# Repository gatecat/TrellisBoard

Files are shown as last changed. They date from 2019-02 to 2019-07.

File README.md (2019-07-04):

# Ultimate ECP5 Board

WIP - Rev 1.0 prototypes currently under test...

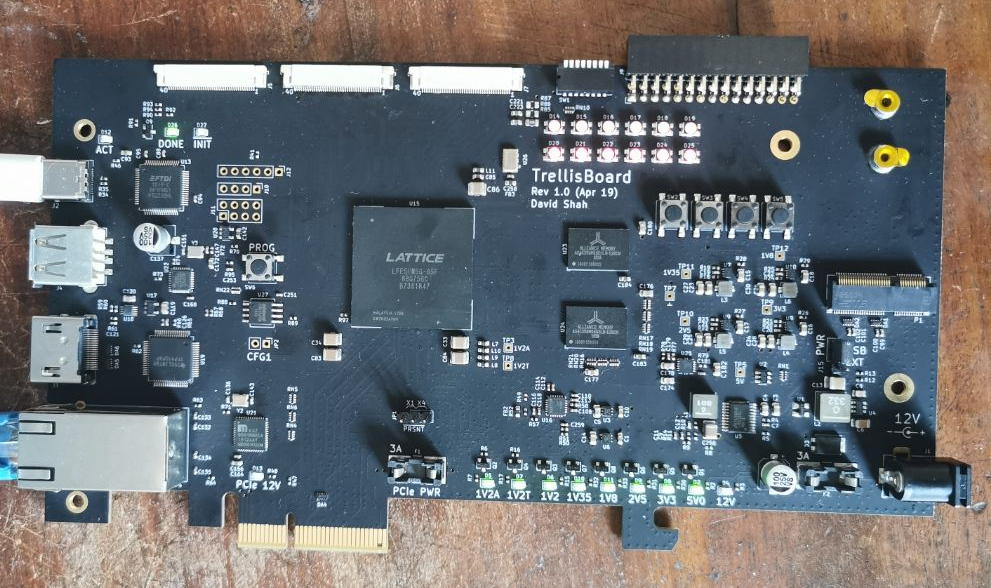
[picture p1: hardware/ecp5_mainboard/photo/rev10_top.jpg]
Photo of PCB rev 1.0

Render of PCB rev 1.0

## Key Features
 - Largest ECP5; LFE5UM5G-85F
 - PCIe 2.0 x2 card edge connector on two SERDES channels
 - Remaining two SERDES channels on M.2 E-key connector
 - 1GByte x32 DDR3L (two x16 chips)
 - Dedicated HDMI output, using TFP410 serialiser
 - 1000BASE-T GbE connector with RGMII PHY
 - USB-A 2.0 host connector with ULPI PHY
 - FT2232H for debug JTAG and UART/FIFO with type-C connector
 - PCIe, external 12V or USB power input
 - 12 bicolour (tristate) user LEDs, 4 user buttons, 8 user DIP switches
 - 128Mbit QSPI flash for boot and data
 - microSD card connector
 - Dual PMOD connector with extra "middle" IO pins
 - As many remaining IO as possible on high speed FFC connectors with a differential optimised pinout (3x 24 IO). Selectable 1.8V/2.5V/3.3V

## Layout
 - PCIe card form factor
 - At least Ethernet, USB-A, USB type-C power/debug and HDMI out
 - Other connectors probably would have to be on other sides. FFC connectors probably on top so they can loop over to another card to form a 2-slot card (e.g. with ADCs/DACs for SDR/DAQ)

## Possible accessories using high-speed FFC connectors
 - MIPI DSI smartphone-style LCDs
 - MIPI CSI-2 cameras
 - High speed ADC/DAC
 - HDMI in/out, direct or using serialiser chip
 - LVDS video in/out for LCDs or block cameras
 - Breakout board to dual or triple PMOD

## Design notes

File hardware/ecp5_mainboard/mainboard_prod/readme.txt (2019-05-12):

TrellisBoard rev1.0
--------------------

Contact: David Shah <dave@ds0.me>

Files:
 - gerber/: gerbers for all layers
        F_Cu, In1_Cu..In6_Cu, B_Cu: copper layers from top to bottom (8 layers)
        F_SilkS, B_SilkS: top and bottom silkscreen
        F_Mask, B_Mask: top and bottom soldermask
        F_Paste, B_Paste: top and bottom stencil
        Edge_Cuts: board outline
        NPTH: non-plated holes drill
        PTH: plated holes drill
 - part_mapping_top.svg, part_mapping_bottom.svg: graphical part mapping (copy of silkscreen)
 - ecp5_mainboard-all-pos.csv: x & y coordinates for all SMD parts
 - ecp5_mainboard_bom_elecrow.xls: bill-of-materials for all parts

BOM notes:
 - Turnkey order, all parts to be ordered by Elecrow
 - Parts with "Substition Allowed" = N must be exact part number match from a distributor (DigiKey, Mouser, etc). DigiKey part numbers are typically given but other distributors may be used
 - Parts with "Substition Allowed" = Y may be substitued with parts of an equal or better specification from another manufacturer/distributor.

PCB specification:
 - 200mm x 111.14mm
 - 8 layers
 - FR4 material
 - 1.6mm board thickness
 - 1oz copper thickness
 - 3mil track/3mil space
 - 0.2mm minimum hole diameter
 - ENIG surface finish
 - Hard gold fingers with 30 degree bevelling for card edge connector
 - Matte black soldermask (black if matte unavailable)
 - White silkscreen

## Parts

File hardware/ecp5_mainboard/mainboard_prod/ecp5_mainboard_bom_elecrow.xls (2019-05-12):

Designator | Package | Quantity | Value | Place | Pads SMD | Pads THT | Description | Manufacturer | Manufacturer P/N | Supplier | Supplier P/N | Substitution Allowed
C10,C1 | C_0603_1608Metric | 2 | 1µ | Y | 2 | 0 | 1uF 0603 16V X7R capacitor | Samsung | CL10B105MO8NNWC | Digikey | 1276-6524-1-ND | Y
C11 | C_0402_1005Metric | 1 | 180p | Y | 2 | 0 | 180pF 0402 50V C0G capacitor | Samsung | CL05C181JB5NNNC | Digikey | 1276-1651-1-ND | Y
C114,C112,C259,C258,C257,C204,C78,C77,C76,C75,C38,C39,C40,C54,C45,C74,C215,C217,C218,C224,C55,C56,C57,C58,C44,C61,C64,C79,C67,C71,C72,C113,C116,C82,C216,C94,C92,C91,C87,C98,C122,C95,C48,C51,C52,C53,C41,C111,C73,C97,C108,C110,C140,C156,C159,C194,C162,C186,C187,C188,C189,C190,C191,C192,C193,C195,C163,C185,C254,C239,C196,C197,C198,C199,C200,C203,C252,C205,C206,C225,C209,C210,C211,C212,C70,C226,C227,C229,C230,C231,C232,C234,C235,C236,C237,C238,C251,C249,C248,C247,C246,C245,C244,C242,C241 | C_0402_1005Metric | 105 | 470n | Y | 2 | 0 | 470nF 0402 10V X5R capacitor | Samsung | CL05A474KP5NNNC | Digikey | 1276-1173-1-ND | Y
C117,C115 | C_0402_1005Metric | 2 | DNP | N
C12 | C_0402_1005Metric | 1 | 750p | Y | 2 | 0 | 750pF 0402 50V X7R capacitor | Yageo | CC0402KRX7R9BB751 | Digikey | 311-3649-1-ND | Y
C121 | C_0402_1005Metric | 1 | 100p | Y | 2 | 0 | 100pF 0402 50V C0G capacitor | Yageo | CC0402JRNPO9BN101 | Digikey | 311-1024-1-ND | Y
C130,C129,C128,C127,C126,C131 | C_0402_1005Metric | 6 | 10n | Y | 2 | 0 | 10nF 0402 16V X7R capacitor | Samsung | CL05B103KO5NNNC | Digikey | 1276-1051-1-ND | Y
C136,C143 | C_0402_1005Metric | 2 | 22p | Y | 2 | 0 | 22pF 0402 50V C0G capacitor | Samsung | CL05C220JB5NNNC | Digikey | 1276-1116-1-ND | Y
C2, C137 | CP_Elec_6.3x5.8 | 2 | 100u/25V | Y | 2 | 0 | 100uF 25V 6.3mm SMD electrolytic | Nichicon | UWT1E101MCL1GS | Digikey | 493-2190-1-ND | Y
C147,C151 | C_0402_1005Metric | 2 | 12p | Y | 2 | 0 | 12pF 0402 50V C0G capacitor | Samsung | CL05C120JB5NNNC | Digikey | 1276-1178-1-ND | Y
C149,C146,C145,C144,C148,C160,C158,C157,C155,C154,C153,C152,C150,C47,C65,C42,C43,C63,C46,C62,C66 | C_0201_0603Metric | 21 | 10n | Y | 2 | 0 | 10nF 0201 10V X7R capacitor | Samsung | CL03B103KP3NNNC | Digikey | 1276-1152-1-ND | Y
C19,C20,C21,C22 | C_0402_1005Metric | 4 | 120p | Y | 2 | 0 | 120pF 0402 50V C0G capacitor | Yageo | CC0402FRNPO9BN121 | Digikey | 311-3727-1-ND | Y
C256,C84,C31,C33,C34,C13,C83, C86 | C_1210_3225Metric | 8 | 47µ | Y | 2 | 0 | 47uF 1210 16V X6S capacitor | Murata | GRM32EC81C476KE15L | Digikey | 490-10531-1-ND | Y
C260,C161,C173,C172,C220,C93,C165,C164,C96,C219,C221,C222,C223,C228,C90,C250,C89,C142,C37,C139,C243,C32,C35,C233,C36,C240,C138,C81,C80,C85,C184,C183 | C_0603_1608Metric | 32 | 4.7µ | Y | 2 | 0 | 4.7uF 0603 10V X5R capacitor | Samsung | CL10A475MP5LNNC | Digikey | 1276-6684-1-ND | Y
C27,C25,C24,C23,C18,C17,C16,C3,C4,C5,C15,C174,C14,C125,C176,C26,C28,C29,C30,C255,C180,C107,C109,C178,C177,C119,C120,C123,C124, C182 | C_0805_2012Metric | 30 | 10µ | Y | 2 | 0 | 10uF 0805 10V X7R capacitor | Samsung | CL21B106KPQNNNE | Digikey | 1276-1764-1-ND | Y
C59,C60,C50,C49 | C_0201_0603Metric | 4 | 1n | Y | 2 | 0 | 1nF 0201 16V X7R capacitor | Samsung | CL03B102KO3NNNC | Digikey | 1276-1342-1-ND | Y
C6 | C_1206_3216Metric | 1 | 22µ/25V | Y | 2 | 0 | 22uF 1206 25V X6S capacitor | Samsung | CL31X226KAHN3NE | Digikey | 1276-3299-1-ND | Y
C7,C253,C207,C68,C69,C88,C99,C101,C102,C103,C104,C105,C106,C118,C100,C134,C135,C141,C166,C167,C168,C169,C170,C171,C175,C179,C181,C133,C201,C202,C208,C213,C214,C132 | C_0402_1005Metric | 34 | 100n | Y | 2 | 0 | 100nF 0402 16V X7R capacitor | Samsung | CL05B104KO5NNNC | Digikey | 1276-1001-1-ND | Y
C8 | C_0805_2012Metric | 1 | 100n/25V | Y | 2 | 0 | 100nF 0805 25V X7R capacitor | Samsung | CL21B104KACNNNC | Digikey | 1276-1099-1-ND | Y
C9 | C_0402_1005Metric | 1 | 1.8n | Y | 2 | 0 | 1.8nF 0402 50V X7R capacitor | Samsung | CL05B182KB5NNNC | Digikey | 1276-1526-1-ND | Y
D18,D17,D19,D16,D15,D14 | Wurth_BiLED_150141_3528 | 6 | 150141YB73100 | Y | 4 | 0 | Blue/Yellow 3528 LED | Wurth | 150141YB73100 | Digikey | 732-5003-1-ND | N
D22,D21,D23,D24,D25,D20 | Wurth_BiLED_150141_3528 | 6 | 150141RV73100 | Y | 4 | 0 | Green/Red 3528 LED | Wurth | 150141RV73100 | Digikey | 732-5001-1-ND | N
D27 | LED_0805_2012Metric | 1 | RED | Y | 2 | 0 | Red 0805 LED | OSRAM | LH R974-LP-1 | Digikey | 475-1415-1-ND | Y
D3 | TO-277B | 1 | MBR15U60 | Y | 3 | 0 | Schottky Diode 60V 15A TO-277 | Micro | MBR15U60-TP | Digikey | MBR15U60-TPMSCT-ND | N
D8,D2,D26,D4,D5,D6,D7,D9,D10,D11,D12,D13 | LED_0805_2012Metric | 12 | GREEN | Y | 2 | 0 | Green 0805 LED | OSRAM | LG R971-KN-1 | Digikey | 475-1410-1-ND | Y
DA5,DA4,DA3,DA1,DA6,DA2 | USON10 | 6 | TPD4E02B04 | Y | 10 | 0 | High speed TVS 10USON | TI | TPD4E02B04DQAR | Digikey | 296-43875-1-ND | N
F1, F2 | FuseHolder_SMD_Shurter_0031.7701.11 | 2 | 3A | Y | 2 | 0 | SMD fuse holder OMF 63, OMF 125 | Schurter | 0031.7701.11 | Digikey | 486-1991-ND | N
FB1,FB2 | L_0603_1608Metric | 2 | 220R@100MHz | Y | 2 | 0 | 220R @ 100MHz 2A 0603 ferrite | TDK | MPZ1608S221ATA00 | Digikey | 445-1565-1-ND | N
FB3,FB8,FB9,FB7,FB5,FB6,FB4, L10,L11,L9,L8,L7,L12,L13 | L_0603_1608Metric | 14 | 100R | Y | 2 | 0 | 100R @ 100MHz 2A 0603 ferrite | TDK | MPZ1608Y101BTA00 | Digikey | 445-2984-1-ND | N
J1 | BarrelJack_Horizontal | 1 | 12V_EXT | Y | 0 | 3 | 2.1mm THT barrel connector | CUI | PJ-037A | Digikey | CP-037A-ND | N
J10 | PinHeader_1x04_P2.54mm_Vertical | 1 | UART | N
J11 | PinHeader_2x04_P2.54mm_Vertical | 1 | FLASH | N
J12 | PinHeader_1x06_P2.54mm_Vertical | 1 | JTAG | N
J13 | microSD_HC_Hirose_DM3AT-SF-PEJM5 | 1 | Micro_SD_Card | Y | 14 | 0 | SMD micro SD card socket | Hirose | DM3AT-SF-PEJM5 | Digikey | HR1964CT-ND | N
J2 | USB_C_Receptacle_Amphenol_12401610E4-2A | 1 | USB_C_Receptacle | Y | 24 | 4 | USB type-C connector | Amphenol | 12401610E4#2A | Digikey | 12401610E4#2ACT-ND | N
J3 | Molex_HDMI_A_47151-0001 | 1 | HDMI_A | Y | 19 | 4 | HDMI type-A SMD connector | Molex | 471510001 | Digikey | WM19086CT-ND | N
J4 | 292303-7 | 1 | USB_A | Y | 4 | 2 | USB A connector | TE | 292303-7 | Digikey | A115151-ND | N
J5, J6, J7 | TE_FPC_40pin_p0.5mm_4-1734839-0 | 3 | EXT2 | Y | 42 | 0 | 40pin 0.5mm FPC connector top contact | TE | 4-1734839-0 | Digikey | A100229CT-ND | N
J8,J14 | 9774025151R | 2 | 9774025151R | Y | 1 | 0 | M2.5x0.45 standoff | Wurth | 9774025151R | Digikey | 732-7078-1-ND | N
J9 | PinHeader_2x15_P2.54mm_Horizontal | 1 | PMOD_01 | Y | 0 | 30 | 2x15 2.54mm right angle THT socket | Sullins | PPPC152LJBN-RC | Digikey | S5568-ND | Y
JP1 | PinHeader_1x03_P2.54mm_Vertical | 1 | PRSNT | Y | 0 | 3 | 1x3 2.54mm straight THT header | Wurth | 61300311121 | Digikey | 732-5316-ND | Y
JP2 | PinHeader_1x02_P2.54mm_Vertical | 1 | CFG1 | N
L1 | L_Coilcraft_XAL5030 | 1 | 800nH/XAL5030 | Y | 2 | 0 | 800nH 13A 5030 inductor | Coilcraft | XAL5030-801MEB | Mouser | 994-XAL5030-801MEB | N
L2 | L_CoilCraft_XAL60xx | 1 | 3.3µH/XAL6030-332 | Y | 2 | 0 | 3.3uH 8A 6030 inductor | Coilcraft | XAL6030-332MEC | Mouser | 994-XAL6030-332MEC | N
L6,L3,L5,L4 | L_Vishay_IHLP-1212 | 4 | 470n/IHLP1212 | Y | 2 | 0 | 470nH 6.7A 1212 inductor | Vishay Dale | IHLP1212AEERR47M11 | Digikey | 541-1330-1-ND | N
P1 | 2199230-4 | 1 | M2_SOCKET_E | Y | 69 | 0 | M.2 socket E key | TE | 2199230-4 | Mouser | 571-2199230-4 | N
P3 | PCIe_EDGE_x4 | 1 | PCIe_x4_EDGE | N
P4 | Pulse_MagJack_JK0654219NL | 1 | JK0654219NL | Y | 0 | 20 | 1GbE Magjack | Pulse | JK0654219NL | Digikey | 1840-1183-ND | N
Q4,Q2 | SOT-23 | 2 | BC850 | Y | 3 | 0 | NPN transistor 45V 0.1A SOT-23 | ON semi | BC850BLT1G | Digikey | BC850BLT1GOSCT-ND | N
Q5,Q7,Q3,Q1,Q9,Q8,Q6 | SOT-23 | 7 | BSH111BKR | Y | 3 | 0 | N-ch MOSFET 55V 0.2A SOT-23 | Nexperia | BSH111BKR | Digikey | 1727-2340-1-ND | N
R12 | R_0402_1005Metric | 1 | 54.9k | Y | 2 | 0 | 54.9k 1% 0402 resistor | Yageo | RC0402FR-0754K9L | Digikey | YAG3185CT-ND | Y
R14 | R_0402_1005Metric | 1 | 470k | Y | 2 | 0 | 470k 1% 0402 resistor | Yageo | RC0402FR-07470KL | Digikey | 311-470KLRCT-ND | Y
R18 | R_0402_1005Metric | 1 | 124k | Y | 2 | 0 | 124k 1% 0402 resistor | Yageo | RC0402FR-07124KL | Digikey | 311-124KLRCT-ND | Y
R2,R46 | R_0402_1005Metric | 2 | 1.5k | Y | 2 | 0 | 1.5k 1% 0402 resistor | Yageo | RC0402FR-071K5L | Digikey | 311-1.50KLRCT-ND | Y
R20 | R_0402_1005Metric | 1 | 453k | Y | 2 | 0 | 453k 1% 0402 resistor | Yageo | RC0402FR-07453KL | Digikey | YAG3164CT-ND | Y
R22 | R_0402_1005Metric | 1 | 316k | Y | 2 | 0 | 316k 1% 0402 resistor | Yageo | RC0402FR-07316KL | Digikey | YAG3113CT-ND | Y
R23,R25,R21,R19 | R_0402_1005Metric | 4 | 100k | Y | 2 | 0 | 100k 1% 0402 resistor | Yageo | RC0402FR-07100KL | Digikey | 311-100KLRCT-ND | Y
R24,R61 | R_0402_1005Metric | 2 | 200k | Y | 2 | 0 | 200k 1% 0402 resistor | Yageo | RC0402FR-07200KL | Digikey | 311-200KLRCT-ND | Y
R3,R9,R88,R48 | R_0402_1005Metric | 4 | 4.7k | Y | 2 | 0 | 4.7k 1% 0402 resistor | Yageo | RC0402FR-074K7L | Digikey | 311-4.7KLRCT-ND | Y
R31,R30,R33,R17,R15,R64,R32,R65,R66,R63,R73,R7,R92,R89,R93,R47 | R_0402_1005Metric | 16 | 1k | Y | 2 | 0 | 1k 1% 0402 resistor | Yageo | RC0402FR-071KL | Digikey | 311-1.00KLRCT-ND | Y
R35,R34,R58 | R_0402_1005Metric | 3 | 0R | Y | 2 | 0 | 0R 0402 resistor | Yageo | RC0402FR-070RL | Digikey | 311-0.0LRCT-ND | Y
R36,R97,R91,R37 | R_0402_1005Metric | 4 | 22 | Y | 2 | 0 | 22R 1% 0402 resistor | Yageo | RC0402FR-0722RL | Digikey | 311-22.0LRCT-ND | Y
R39 | R_0402_1005Metric | 1 | 12k | Y | 2 | 0 | 12k 1% 0402 resistor | Yageo | RC0402FR-0712KL | Digikey | 311-12.0KLRCT-ND | Y
R4 | R_0402_1005Metric | 1 | 10 | Y | 2 | 0 | 10R 1% 0402 resistor | Yageo | RC0402FR-0710RL | Digikey | 311-10.0LRCT-ND | Y
R49 | R_0402_1005Metric | 1 | DNP | N
R5 | R_0402_1005Metric | 1 | 47k | Y | 2 | 0 | 47k 1% 0402 resistor | Yageo | RC0402FR-0747KL | Digikey | 311-47.0KLRCT-ND | Y
R51,R67,R68,R60,R59,R38,R50 | R_0402_1005Metric | 7 | 2.2k | Y | 2 | 0 | 2.2k 1% 0402 resistor | Yageo | RC0402FR-072K2L | Digikey | 311-2.20KLRCT-ND | Y
R52 | R_0402_1005Metric | 1 | 2.2 | Y | 2 | 0 | 2.2R 1% 0402 resistor | Yageo | RC0402FR-072R2L | Digikey | 311-2.20LRCT-ND | Y
R54,R53,R1,R29,R28,R27,R16,R10,R78,R77,R70,R11,R69,R6,R96,R8,R94,R79,R90,R95,R26,R13,R57,R40,R41 | R_0402_1005Metric | 25 | 10k | Y | 2 | 0 | 10k 1% 0402 resistor | Yageo | RC0402FR-0710KL | Digikey | 311-10.0KLRCT-ND | Y
R62 | R_0402_1005Metric | 1 | 510 | Y | 2 | 0 | 510R 1% 0402 resistor | Yageo | RC0402FR-07510RL | Digikey | 311-510LRCT-ND | Y
R71 | R_0402_1005Metric | 1 | 12.1k | Y | 2 | 0 | 12.1k 1% 0402 resistor | Yageo | RC0402FR-0712K1L | Digikey | 311-12.1KLRCT-ND | Y
R72 | R_0402_1005Metric | 1 | 1M | Y | 2 | 0 | 1M 1% 0402 resistor | Yageo | RC0402FR-071ML | Digikey | 311-1.00MLRCT-ND | Y
R74 | R_0402_1005Metric | 1 | 120k | Y | 2 | 0 | 120k 1% 0402 resistor | Yageo | RC0402FR-07120KL | Digikey | 311-120KLRCT-ND | Y
R76,R75 | R_0402_1005Metric | 2 | 51 | Y | 2 | 0 | 51R 1% 0402 resistor | Yageo | RC0402FR-0751RL | Digikey | 311-51.0LRCT-ND | Y
R81,R80 | R_0402_1005Metric | 2 | 240 | Y | 2 | 0 | 240R 1% 0402 resistor | Yageo | RC0402FR-07240RL | Digikey | 311-240LRCT-ND | Y
R82,R45,R42,R43,R44,R85 | R_0805_2012Metric | 6 | 0R | Y | 2 | 0 | 0R 1% 0805 resistor | Yageo | RC0805JR-070RL | Digikey | 311-0.0ARCT-ND | Y
R83,R84,R86,R87 | R_0805_2012Metric | 4 | DNP | N
RN12,RN9,RN8,RN5,RN4,RN6,RN22,RN23,RN24,RN1,RN2, RN3 | R_Array_Convex_4x0402 | 12 | 10k | Y | 8 | 0 | 10k 4x0402 convex resistor array | Panasonic | EXB-28V103JX | Digikey | Y7103CT-ND | Y
RN14,RN11,RN10,RN7,RN15,RN13 | R_Array_Convex_4x0402 | 6 | 2.2k | Y | 8 | 0 | 2.2k 4x0402 convex resistor array | Panasonic | EXB-28V222JX | Digikey | Y7222CT-ND | Y
RN16,RN18,RN19,RN20,RN21,RN17 | R_Array_Convex_4x0402 | 6 | 51 | Y | 8 | 0 | 51R 4x0402 convex resistor array | Panasonic | EXB-28V510JX | Digikey | Y7510CT-ND | Y
SW1 | DipSW_CHP-081TA | 1 | CHP-081TA | Y | 8 | 0 | 8x piano SMD DIP switch | Nidec Copal | CHP-081TA | Digikey | 563-1019-1-ND | N
SW6,SW5,SW4,SW3,SW2 | SW_SPST_B3S-1000 | 5 | SW_Push | Y | 4 | 0 | Push switch 6.6x6mm SMD | Omron | B3S-1000P | Digikey | SW836CT-ND | Y
TP10 | TestPoint_THTPad_1.5x1.5mm_Drill0.7mm | 1 | 2.5V | N
TP11 | TestPoint_THTPad_1.5x1.5mm_Drill0.7mm | 1 | 1.35V | N
TP12 | TestPoint_THTPad_1.5x1.5mm_Drill0.7mm | 1 | 1.8V | N
TP3 | TestPoint_THTPad_1.5x1.5mm_Drill0.7mm | 1 | 1.2VA | N
TP4 | TestPoint_Pad_1.5x1.5mm | 1 | 1.2V | N
TP5 | TestPoint_THTPad_1.5x1.5mm_Drill0.7mm | 1 | 5V | N
TP6 | TestPoint_Pad_1.5x1.5mm | 1 | GND | N
TP7 | TestPoint_THTPad_1.5x1.5mm_Drill0.7mm | 1 | GND | N
TP8 | TestPoint_THTPad_1.5x1.5mm_Drill0.7mm | 1 | 1.2VT | N
TP9 | TestPoint_THTPad_1.5x1.5mm_Drill0.7mm | 1 | 3.3V | N
U1 | SOT-143 | 1 | MAX811MEUS-T | Y | 4 | 0 | Voltage monitor 4.38V SOT143-4 | Maxim | MAX811MEUS+T | Digikey | MAX811MEUS+TCT-ND | N
U11 | WQFN-20-1EP_2.5x4.5mm_P0.5mm_EP1x2.9mm | 1 | CBTL02043A | Y | 21 | 0 | 2:1 high speed mux | NXP | CBTL02043ABQ,115 | Digikey | 568-6678-1-ND | N
U12 | SOT-23-6 | 1 | 93AA46B_OT | Y | 6 | 0 | 1K SPI EEPROM SOT-23-6 | Microchip | 93AA46BT-I/OT | Digikey | 93AA46BT-I/OTCT-ND | N
U13 | LQFP-64_10x10mm_P0.5mm | 1 | FT2232H | Y | 64 | 0 | USB HS UART/FIFO 64-LQFP | FTDI | FT2232HL | Digikey | 768-1024-1-ND | N
U15 | CABGA756_27x27mm_p0.8mm | 1 | ECP5UM5G_85_CABGA756 | Y | 756 | 0 | ECP5 FPGA 83.6K LUT 5G SERDES | Lattice Semi | LFE5UM5G-85F-8BG756C | Digikey | 220-2115-ND | N
U16 | QFN-24-1EP_4x4mm_P0.5mm_EP2.7x2.7mm | 1 | 5P49V6965 | Y | 25 | 0 | Programmable clock generator | IDT | 5P49V6965A000NLGI | Digikey | 800-3818-ND | N
U18 | VSSOP-8_2.3x2mm_P0.5mm | 1 | PCA9306 | Y | 8 | 0 | I2C level translator | TI | PCA9306DCUR | Digikey | 296-17988-1-ND | N
U19 | HTQFP-64-1EP_10x10mm_P0.5mm_EP8x8mm_Mask4.4x4.4mm_ThermalVias | 1 | TFP410 | Y | 65 | 0 | DVI transmitter | TI | TFP410PAP | Digikey | 296-12666-ND | N
U2 | SOT-23-6 | 1 | LM3880 | Y | 6 | 0 | Power supply sequencer | TI | LM3880MFE-1AA/NOPB | Digikey | 296-46426-1-ND | N
U20,U17 | SOT-23-5 | 2 | TPS2041B | Y | 5 | 0 | 0.5A power dist switch SOT-23-5 | TI | TPS2041BDBVR | Digikey | 296-21263-1-ND | N
U21 | QFN-48-1EP_7x7mm_P0.5mm_EP5.15x5.15mm | 1 | KSZ9031RNXCA | Y | 49 | 0 | 1GbE transceiver | Microchip | KSZ9031RNXCA-TR | Digikey | KSZ9031RNXCA-CT-ND | N
U22 | QFN-32-1EP_5x5mm_P0.5mm_EP3.45x3.45mm | 1 | USB3300-EZK | Y | 33 | 0 | USB2 HS ULPI PHY | Microchip | USB3300-EZK-TR | Digikey | USB3300-EZK-CT-ND | N
U24,U23 | BGA-96_9.0x13.0mm_Layout2x3x16_P0.8mm | 2 | AS4C256M16D3 | Y | 96 | 0 | 4Gb 256Mx16 800MHz DDR3L | Alliance Memory | AS4C256M16D3LB-12BCN | Digikey | 1450-1395-ND | N
U25 | VSON-10-1EP_3x3mm_P0.5mm_EP1.65x2.4mm | 1 | TPS51200DRC | Y | 11 | 0 | DDR termination regulator | TI | TPS51200DRCR | Digikey | 296-26978-1-ND | N
U26 | OSC_IDT_XU_5x3.2mm | 1 | XL_XO_LVDS | Y | 6 | 0 | 100MHz 3.3V LVDS oscillator 5x3.2mm | IDT | XUL535100.000JS6I8 | Digikey | 800-2855-1-ND | N
U27 | SO-8_5.3x6.2mm_P1.27mm | 1 | W25Q | Y | 8 | 0 | 128M SPI flash SO-8 | Winbond | W25Q128JVSIM TR | Digikey | W25Q128JVSIMCT-ND | N
U3,U6 | TI_WSON6_2x2mm_p0.65mm | 2 | TLV75712PDR | Y | 7 | 0 | 1.2V 1A LDO 6WSON | TI | TLV75712PDRVR | Digikey | 296-50005-1-ND | N
U4 | SOT-23-6 | 1 | TPS565208 | Y | 6 | 0 | 5A synchronous buck converter SOT-23-6 | TI | TPS565208DDCT | Digikey | 296-47502-1-ND | N
U5 | HTSSOP-20-1EP_4.4x6.5mm_P0.65mm_EP3.4x6.5mm | 1 | LM21212-2 | Y | 21 | 0 | 12A buck converter | TI | LM21212MH-2/NOPB | Digikey | LM21212MH-2/NOPB-ND | N
U7,U8,U9,U10 | TI_VSON-HR_1.5x2mm_p0.5mm | 4 | TPS62823 | Y | 8 | 0 | 3A buck converter | TI | TPS62823DLCR | Digikey | 296-50425-1-ND | N
X1 | Oscillator_SMD_EuroQuartz_XO32-4Pin_3.2x2.5mm | 1 | XO32 | Y | 4 | 0 | 12MHz 3.3V CMOS oscillator 3.2x2.5mm | Abracon | ASE-12.000MHZ-LC-T | Digikey | 535-9561-1-ND | N
Y1,Y2 | Crystal_Epsom_TSX-3225 | 2 | 25MHz | Y | 4 | 0 | 25MHz SMD crystal 3.2x2.5mm | Diodes Inc | FL2500133 | Digikey | FL2500133CT-ND | N
Y3 | Crystal_Epsom_TSX-3225 | 1 | 24MHz | Y | 4 | 0 | 24MHz SMD crystal 3.2x2.5mm | Epson | TSX-3225 24.0000MF10Z-C3 | Digikey | SER4373CT-ND | N
J16,J17 | MountingHole_3.2mm_M3_Pad | 2 | MOUNT | N

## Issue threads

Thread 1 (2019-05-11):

Consider 2 x 2 GB

tommythorn, 2019-05-11:
An ultimate board should IMhO maximize external memory.  Since 2 GiB chips are only ~$13, qty 1, maybe you’d consider going to that?

daveshah1, 2019-05-11:
What is the source for these chips? I can't find any DDR3/DDR3L 16Gb x16 chips stocked by DigiKey. Going to two 8Gb chips for 2GiB total might be an option, but these seem to be about $26 each on DigiKey so not super cheap. I suspect most applications needing this much memory will be bottlenecked by the maximum clock frequency of the ECP5 anyway.

tommythorn, 2019-05-11:
I have never used them so I can’t vouch for them, but https://www.components-center.com/product/Micron-Technology-Inc/MT41K1G16DGA-125-A.html

I strongly disagree with your assertion though. If you used this board for running Fedora/RISC-V, then 1 GB is very limiting.  The argument I got from Fedora for why they wouldn’t support 32-bit RISC-V is that they have packages that can barely compile in that little memory.

tommythorn, 2019-05-11:
Aiee, the qty 1 was a misread, sorry.  It’s qty 1020 but it doesn’t fundamentally change what I wrote.

daveshah1, 2019-05-11:
Seems like this part is now obsolete - https://media.digikey.com/pdf/PCNs/Micron/PCN-32255.pdf - so probably not a good idea to design it into something new. However, I will consider going up to at least 2GiB (two 8Gb chips) for the next revision as I can see this use case now (although compiling packages that need >1GiB RAM on a 100MHz system doesn't sound like a great deal of fun, adding swap into the equation won't help either)

tommythorn, 2019-05-11:
Reasonable if you expect to produce more than 500 of these boards, but if they are pin compatible and just a part swap away, I’d personally just stock up and use them.

Closed 2019-05-11.

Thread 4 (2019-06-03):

SDRAM

emard, 2019-06-03:
Big board, big FPGA, plenty of pins and PCB space.
DDR3 is great but some for some low-latency application SDRAM is still better.
Can you see if possible to add a 32-bit 64MB SDRAM on the next release :)?

daveshah1, 2019-06-03:
There certainly isn't plenty of PCB space available, almost all of the "empty" space is used for routing - and although there are a few spare FPGA pins, they are mostly impossible to break out without major rerouting and higher spec PCB (which I want to avoid now).

It might be possible to use some of the FFCs with a short cable for 16-bit SDRAM.

daveshah1, 2019-06-03:
Incidentally, the latency should be fairly similar to SDRAM - I am seeing a Trc (afaik, this is roughly random latency) of 48.75ns for the DDR3 compared to 60ns for a random SDRAM chip. Likewise a random column latency (Tck*CL) of 15ns for DDR3 compared to 18ns for SDRAM.

emard, 2019-06-03:
If minimig could be made to work with DDR3 that would be
a real-world test because its latency is for sprites running of
EDO RAM. Some people tried, minimig could boot of DDR3
but sprites don't work...

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

daveshah1, 2019-06-03:
My guess is that the problem is typical DDR3 controllers are optimised for throughput rather than latency; rather than an intrinsic fault of the memory itself.

emard, 2019-06-03:
yes DDR3 prefers to transfer a blocks of data
between random accesses, so roughly saying,
it's more similar to SD card than traditional RAM.

It's great for linux, it uses DDR3 very efficiently

With some practical opensource driver
I look forward that other projects also try
switching to DDR3

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

tommythorn, 2019-06-03:
Dave is absolutely correct, with a DDR controller configured/designed for low latency, DDR3 will be at least as fast as SDRAM (probably faster), but optimizing for latency usually compromises bandwidth.

*Iff* latency is of primary concern, you should consider SSRAM, RLDRAM (I & II), etc. but I the $/b is much higher and it probably wouldn't make sense for a general purpose board (I'd personally rather see higher capacity and bandwidth).

emard, 2019-06-04:
OK! Is the DDR3 on this board fully functional can it
already run risc-v linux for example?

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

daveshah1, 2019-06-04:
Yes, both DDR3 and Ethernet are working, although had to make some hacks to LiteX to give Linux access to the full 1GB.

```
        __   _ __      _  __
       / /  (_) /____ | |/_/
      / /__/ / __/ -_)>  <
     /____/_/\__/\__/_/|_|

 (c) Copyright 2012-2019 Enjoy-Digital
 (c) Copyright 2007-2015 M-Labs Ltd

 BIOS built on Jun  3 2019 19:48:31
 BIOS CRC passed (f0c3adde)

--============ SoC info ================--
CPU:       VexRiscv @ 75MHz
ROM:       32KB
SRAM:      4KB
L2:        8KB
MAIN-RAM:  1048576KB

--========= Peripherals init ===========--
Initializing SDRAM...
SDRAM now under software control
Read leveling:
m0, b0: |01100000| delays: 02+-01
best: m0, b0 delays: 02+-01
m1, b0: |01100000| delays: 02+-01
best: m1, b0 delays: 02+-01
m2, b0: |01110000| delays: 02+-01
best: m2, b0 delays: 02+-01
m3, b0: |01110000| delays: 02+-01
best: m3, b0 delays: 02+-01
SDRAM now under hardware control
Memtest OK

--========== Boot sequence =============--
Booting from serial...
Press Q or ESC to abort boot completely.
sL5DdSMmkekro
Timeout
Booting from network...
Local IP : 192.168.7.100
Remote IP: 192.168.7.1
Fetching from: UDP/69
Successfully downloaded 2726644 bytes from Image over TFTP
Successfully downloaded 4056576 bytes from rootfs.cpio over TFTP
Successfully downloaded 1870 bytes from rv32.dtb over TFTP
Successfully downloaded 9008 bytes from emulator.bin over TFTP
Executing booted program at 0x18000000
--============= Liftoff! ===============--
VexRiscv Machine Mode software built Jun  3 2019 19:41:01
--========== Booting Linux =============--
[    0.000000] No DTB passed to the kernel
[    0.000000] Linux version 5.0.9 (florent@lab) (gcc version 8.3.0 (Buildroot 2019.05-git-00938-g75f9fcd0c9-dirty)) #2 Fri May 10 15:14:31 CEST 2019
[    0.000000] Initial ramdisk at: 0x(ptrval) (8388608 bytes)
[    0.000000] Zone ranges:
[    0.000000]   Normal   [mem 0x00000000c0000000-0x00000000ffffffff]
[    0.000000] Movable zone start for each node
[    0.000000] Early memory node ranges
[    0.000000]   node   0: [mem 0x00000000c0000000-0x00000000ffffffff]
[    0.000000] Initmem setup node 0 [mem 0x00000000c0000000-0x00000000ffffffff]
[    0.000000] elf_hwcap is 0x1101
[    0.000000] Built 1 zonelists, mobility grouping on.  Total pages: 260096
[    0.000000] Kernel command line: mem=1024M@0x40000000 rootwait console=hvc0 root=/dev/ram0 init=/sbin/init swiotlb=32
[    0.000000] Dentry cache hash table entries: 131072 (order: 7, 524288 bytes)
[    0.000000] Inode-cache hash table entries: 65536 (order: 6, 262144 bytes)
[    0.000000] Sorting __ex_table...
[    0.000000] Memory: 1028716K/1048576K available (1957K kernel code, 92K rwdata, 317K rodata, 104K init, 184K bss, 19860K reserved, 0K cma-reserved)
[    0.000000] SLUB: HWalign=64, Order=0-3, MinObjects=0, CPUs=1, Nodes=1
[    0.000000] NR_IRQS: 0, nr_irqs: 0, preallocated irqs: 0
[    0.000000] clocksource: riscv_clocksource: mask: 0xffffffffffffffff max_cycles: 0x114c1bade8, max_idle_ns: 440795203839 ns
[    0.000269] sched_clock: 64 bits at 75MHz, resolution 13ns, wraps every 2199023255546ns
[    0.002474] Console: colour dummy device 80x25
[    0.138878] printk: console [hvc0] enabled
[    0.143473] Calibrating delay loop (skipped), value calculated using timer frequency.. 150.00 BogoMIPS (lpj=300000)
[    0.153687] pid_max: default: 32768 minimum: 301
[    0.168633] Mount-cache hash table entries: 2048 (order: 1, 8192 bytes)
[    0.175284] Mountpoint-cache hash table entries: 2048 (order: 1, 8192 bytes)
[    0.238500] devtmpfs: initialized
[    0.280905] clocksource: jiffies: mask: 0xffffffff max_cycles: 0xffffffff, max_idle_ns: 7645041785100000 ns
[    0.290435] futex hash table entries: 256 (order: -1, 3072 bytes)
[    0.432059] clocksource: Switched to clocksource riscv_clocksource
[    0.742689] Unpacking initramfs...
[    2.362331] Initramfs unpacking failed: junk in compressed archive
[    2.388519] workingset: timestamp_bits=30 max_order=18 bucket_order=0
[    2.759652] Block layer SCSI generic (bsg) driver version 0.4 loaded (major 254)
[    2.766647] io scheduler mq-deadline registered
[    2.770322] io scheduler kyber registered
[    4.714238] random: get_random_bytes called from init_oops_id+0x4c/0x60 with crng_init=0
[    4.751172] Freeing unused kernel memory: 104K
[    4.755315] This architecture does not have kernel memory protection.
[    4.761498] Run /init as init process
mount: mounting tmpfs on /dev/shm failed: Invalid argument
mount: mounting tmpfs on /tmp failed: Invalid argument
mount: mounting tmpfs on /run failed: Invalid argument
Starting syslogd: OK
Starting klogd: OK
Initializing random number generator... [    7.455767] random: dd: uninitialized urandom read (512 bytes read)
done.
Starting network: ip: socket: Function not implemented
ip: socket: Function not implemented
FAIL

Welcome to Buildroot
buildroot login: root

   __   _                                  __   _ __      _  __   _   __         ___  _
  / /  (_)__  __ ____ _________  ___  ____/ /  (_) /____ | |/_/__| | / /____ __ / _ \(_)__ _____  __
 / /__/ / _ \/ // /\ \ /___/ _ \/ _ \/___/ /__/ / __/ -_)>  </___/ |/ / -_) \ // , _/ (_-</ __/ |/ /
/____/_/_//_/\_,_//_\_\    \___/_//_/   /____/_/\__/\__/_/|_|    |___/\__/_\_\/_/|_/_/___/\__/|___/

                32-bits VexRiscv CPU with MMU integrated in a LiteX SoC
login[48]: root login on 'hvc0'
root@buildroot:~# free -m
              total        used        free      shared  buff/cache   available
Mem:           1004           3         996           0           5         990
Swap:             0           0           0
root@buildroot:~# cat /proc/cpuinfo
processor	: 0
hart		: 0
isa		: rv32ima
mmu		: sv32
uarch		: spinalhdl,vexriscv

root@buildroot:~#
```

emard, 2019-06-04:
oho, wonderful, a running linux!
maybe i'm off topic already but
i'd like to know is the SD card working also?

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

emard, 2019-06-04:
Actually I'd like to ask is linux booting off SD card and SPI flash,
standalone mode.

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

daveshah1, 2019-06-04:
No, haven't tested that yet - I don't think the SD card bootloader is in LiteX yet. Right now it is booting using TFTP to get the kernel, device tree & ramdisk

Closed 2019-06-04.

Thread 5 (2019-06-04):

Rev 1.0 status tracking

daveshah1, 2019-06-04:
Features tested so far:
 - [x] FT2232H JTAG and UART
 - [ ] FT2232H parallel mode
 - [x] USB powered
 - [ ] 12V power circuitry and connector
 - [x] LEDs
 - [x] Buttons and DIP switches
 - [x] DDR3 (tested up to 400Mbps at present)
 - [x] Ethernet PHY
 - [x] TFP410 HDMI (tested up to 1080p30 at present)
 - [ ] USB ULPI PHY
 - [ ] Clock generator
 - [ ] PCIe
 - [ ] M.2
 - [ ] FFCs
 - [ ] PMOD
 - [ ] micro SD

ki5libs, 2019-10-27:
Hi @daveshah1,

does FFC actual placement let you to use them? I see in the [datasheet](https://www.te.com/commerce/DocumentDelivery/DDEController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) that actuator opens down so connector should be very close to the board edge. How is it really?

daveshah1, 2019-10-28:
I haven't actually got a suitable cable to test with. On the board I have, it seems to move in and out alright at least. But maybe they should be moved to the edge in the next revision.

ki5libs, 2019-11-30:
Hi @daveshah1,

have you already checked clock from U26 oscillator? I'm just a little bit confused with not connected E/D pin...

daveshah1, 2019-11-30:
Hi @ki5libs, see #2 - it should be going into a PCLK pair on the left or right side, ideally near the DDR3. As it stands I've been using the 12MHz clock instead.

ki5libs, 2019-11-30:
@daveshah1, yes, I saw that. Maybe I wasn't clear enough, I just want to ask did you check U26 output in general. Is clock OK on both OUT pins without external pull-up resistor. I didn't noticed that datasheet has information about internal pull-up. Sorry, nevermind.

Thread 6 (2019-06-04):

LED "leakage"

daveshah1, 2019-06-04:
The Vf of the red and green LEDs combined is just enough for them to light dimly even with the middle tristated at 3.3V total. Perhaps this should be dropped a bit with a Schottky in the supply to avoid this.

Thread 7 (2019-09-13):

Using KiCAD repository symbols/footprints

ki5libs, 2019-09-13:
Hello @daveshah1

Nice board! But why do you use local libraries? Some symbols (ex. 93AA46B_OT in eco_memory) exist in upstream KiCAD repository (93AAxxB in Memory_EEPROM). What do you think about my help for creating  KiCAD repository PRs for the rest of the symbols (and may be footprints) with some reworkings in reasonable cases? It would be a good idea to use symbols from the repository in rev.1.1, woudn't it?

Best regards,
Anton Lysak

daveshah1, 2019-09-13:
In most cases, local libraries were used when I couldn't find a suitable symbol in the included ones, in some cases this might have been historical and an equivalent symbol is now upstream. I would certainly welcome your help in upstreaming symbols and move towards using upstreamed symbols wherever possible.

The ECP5 symbol came from a generator (https://github.com/xesscorp/KiPart/), I'm not sure how that would work in terms of upstreaming - given the large number of pins, one would want to avoid significant manual fixes.

ki5libs, 2019-09-13:
Perfect! Do you have any BOM for producing this board, which could be used as a datasheet source? Just because any symbol in the KiCAD repository should have the datasheet link.

daveshah1, 2019-09-13:
Yes, https://github.com/daveshah1/TrellisBoard/blob/master/hardware/ecp5_mainboard/mainboard_prod/ecp5_mainboard_bom_elecrow.xls (generating more of the BOM automatically might be something to look at in the future)

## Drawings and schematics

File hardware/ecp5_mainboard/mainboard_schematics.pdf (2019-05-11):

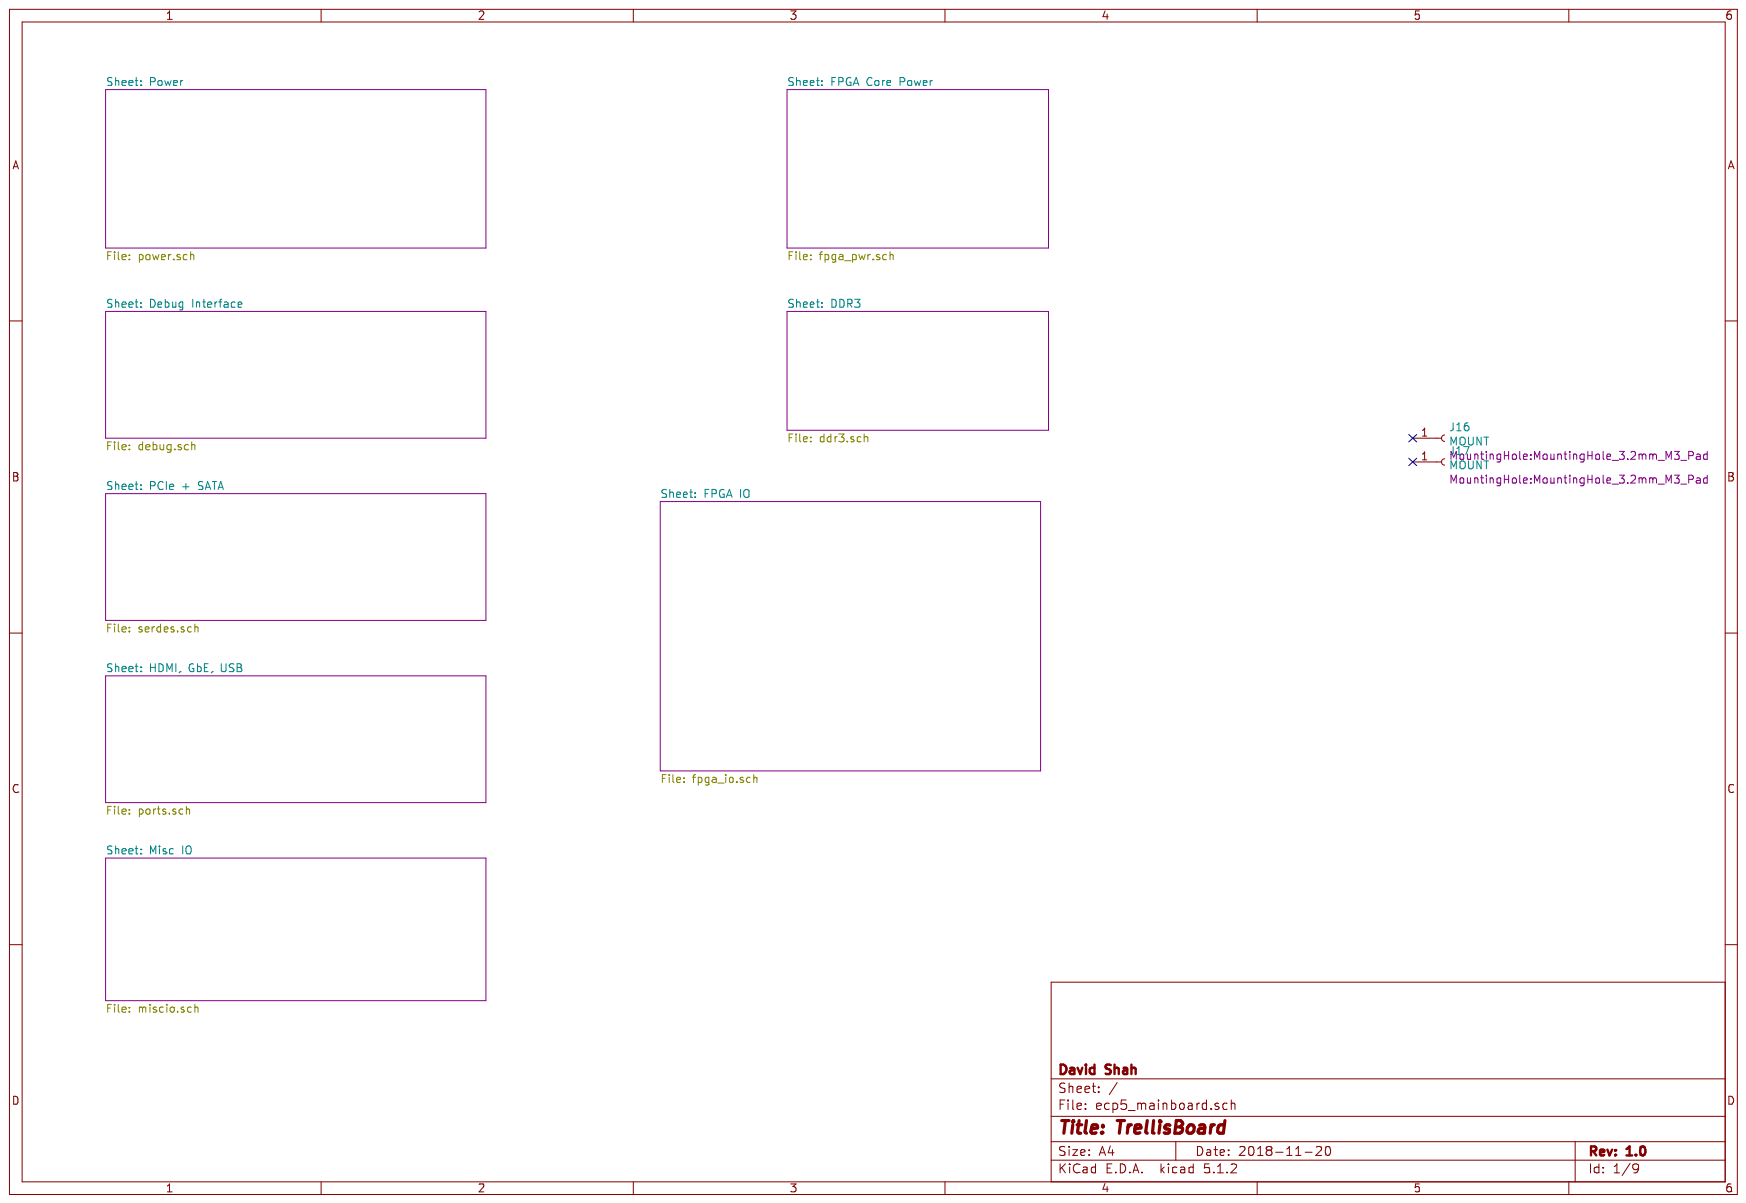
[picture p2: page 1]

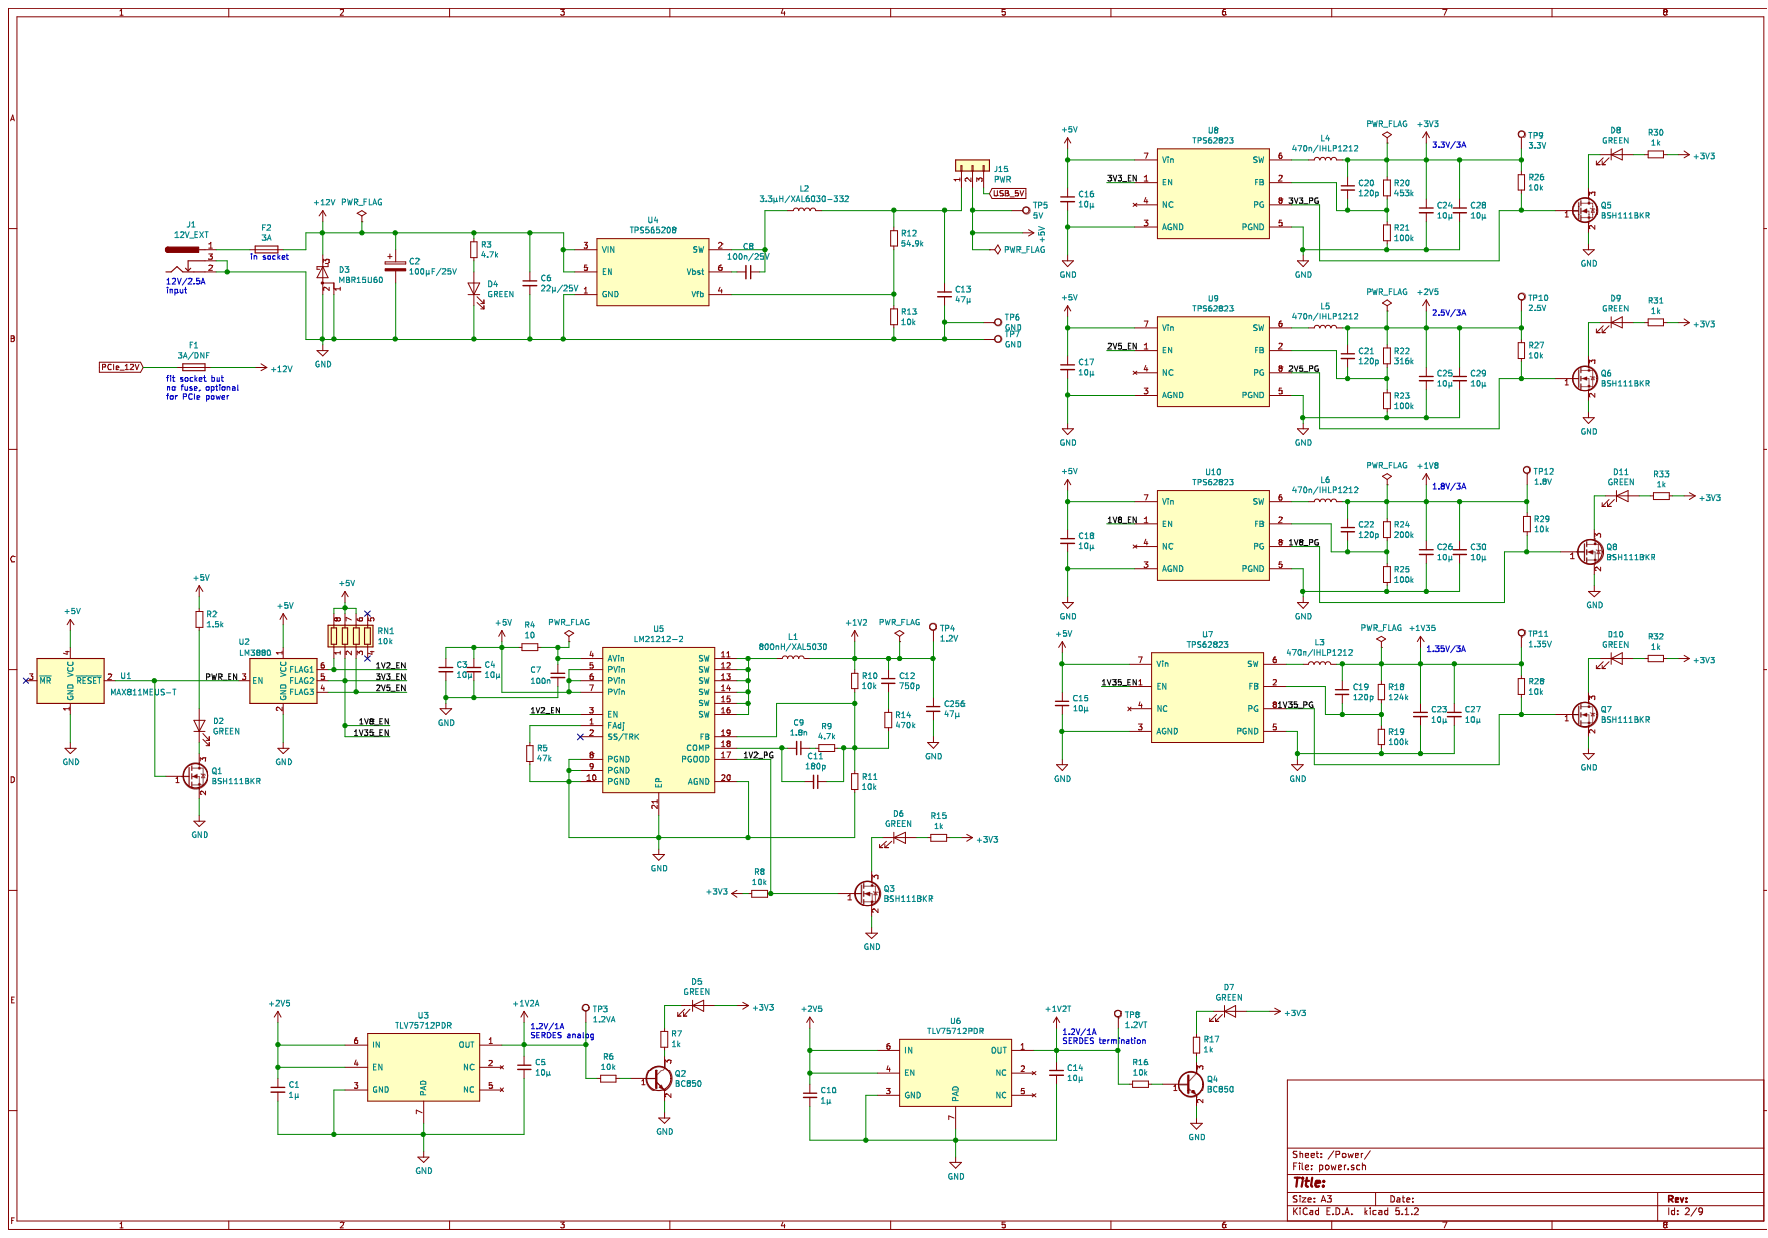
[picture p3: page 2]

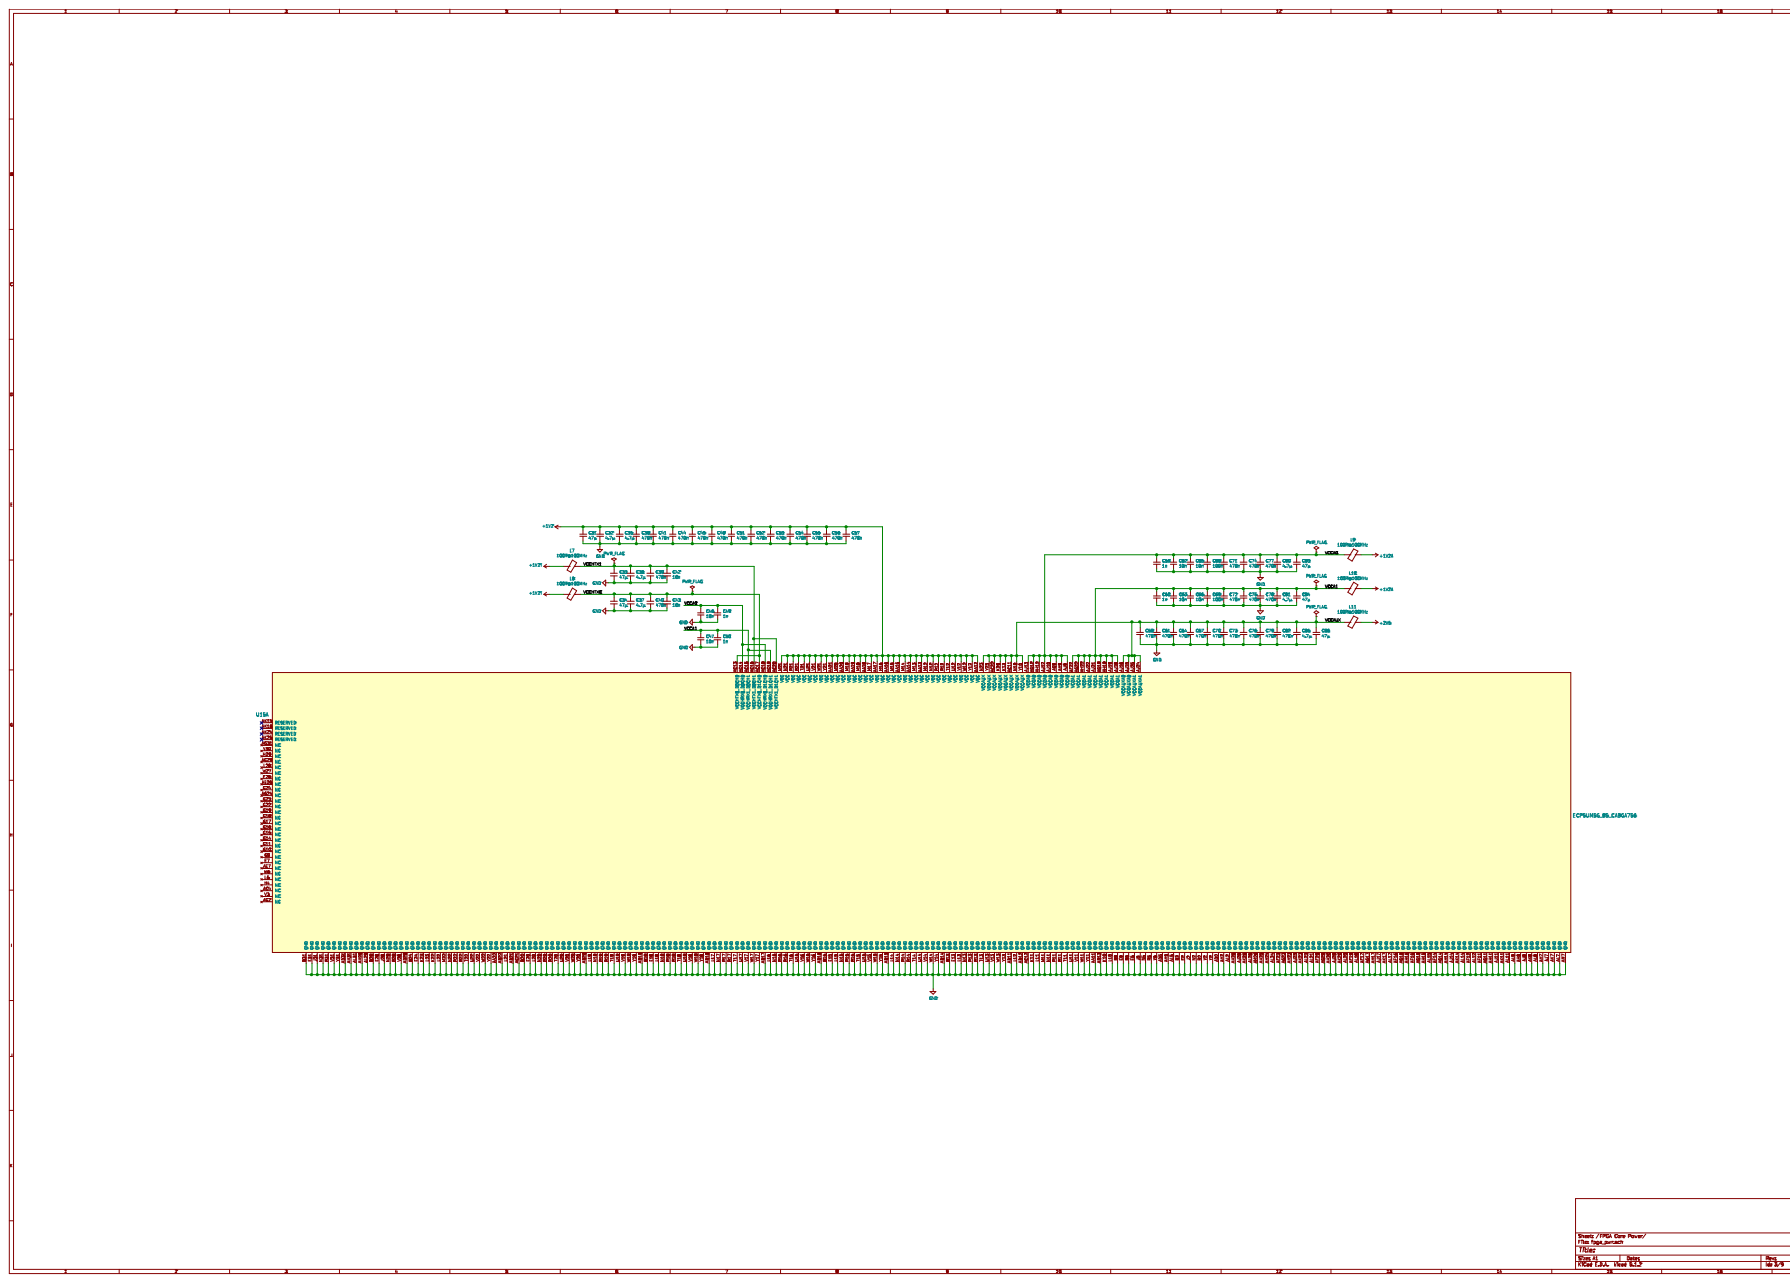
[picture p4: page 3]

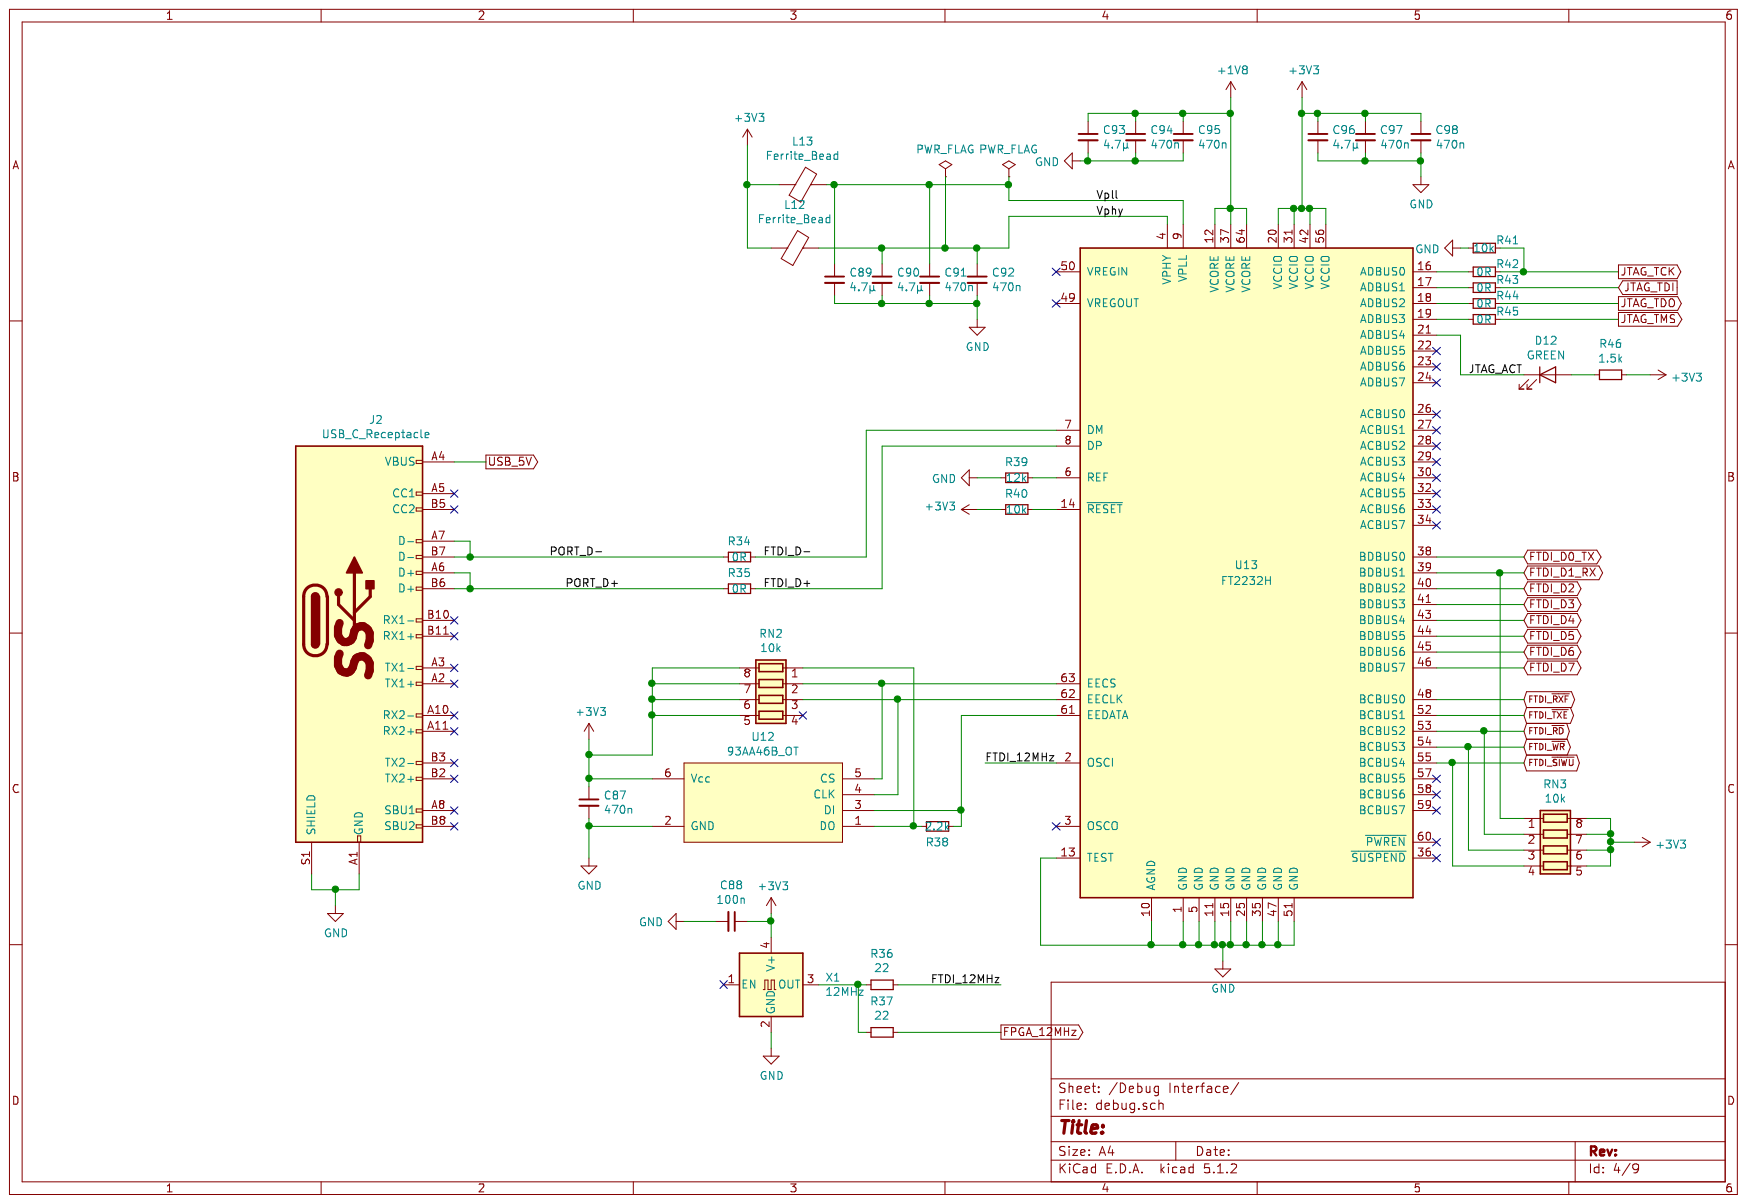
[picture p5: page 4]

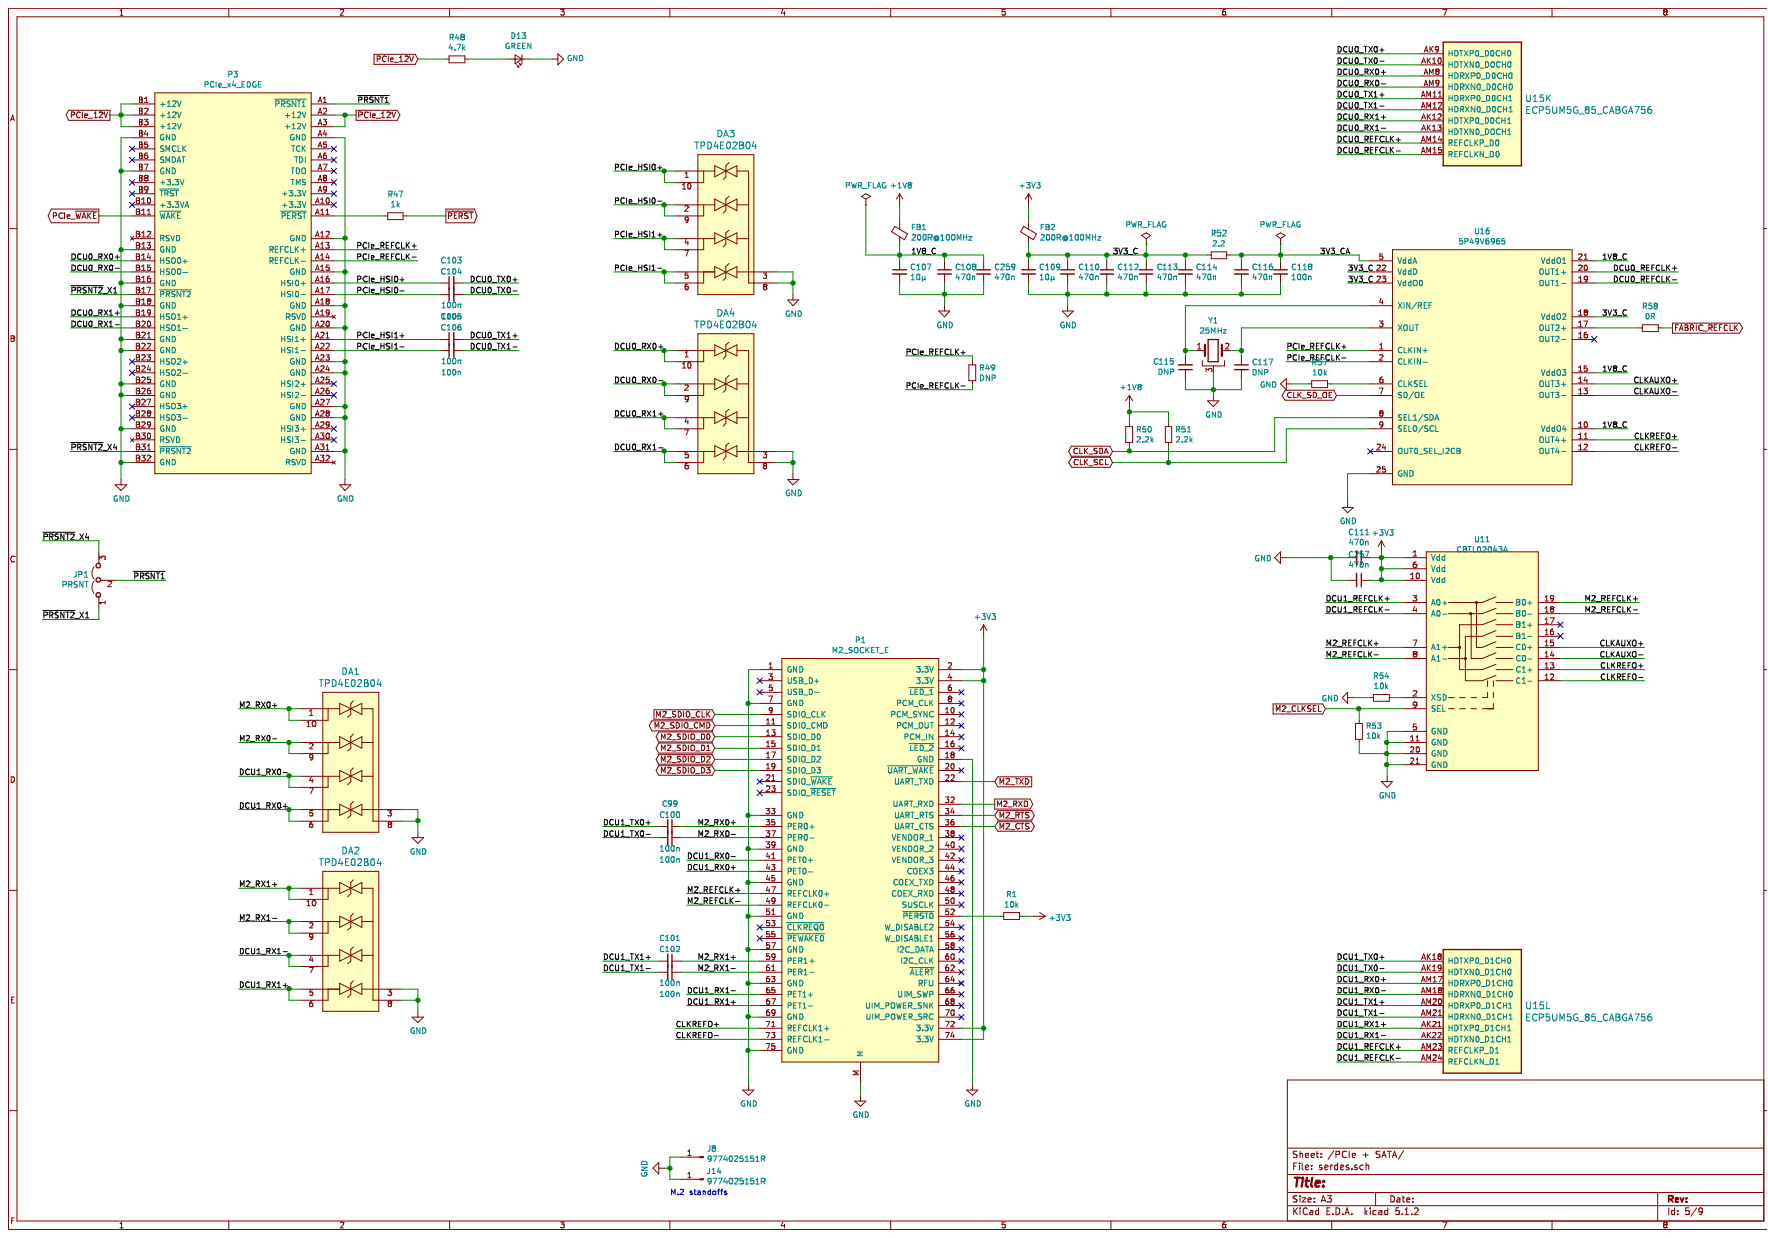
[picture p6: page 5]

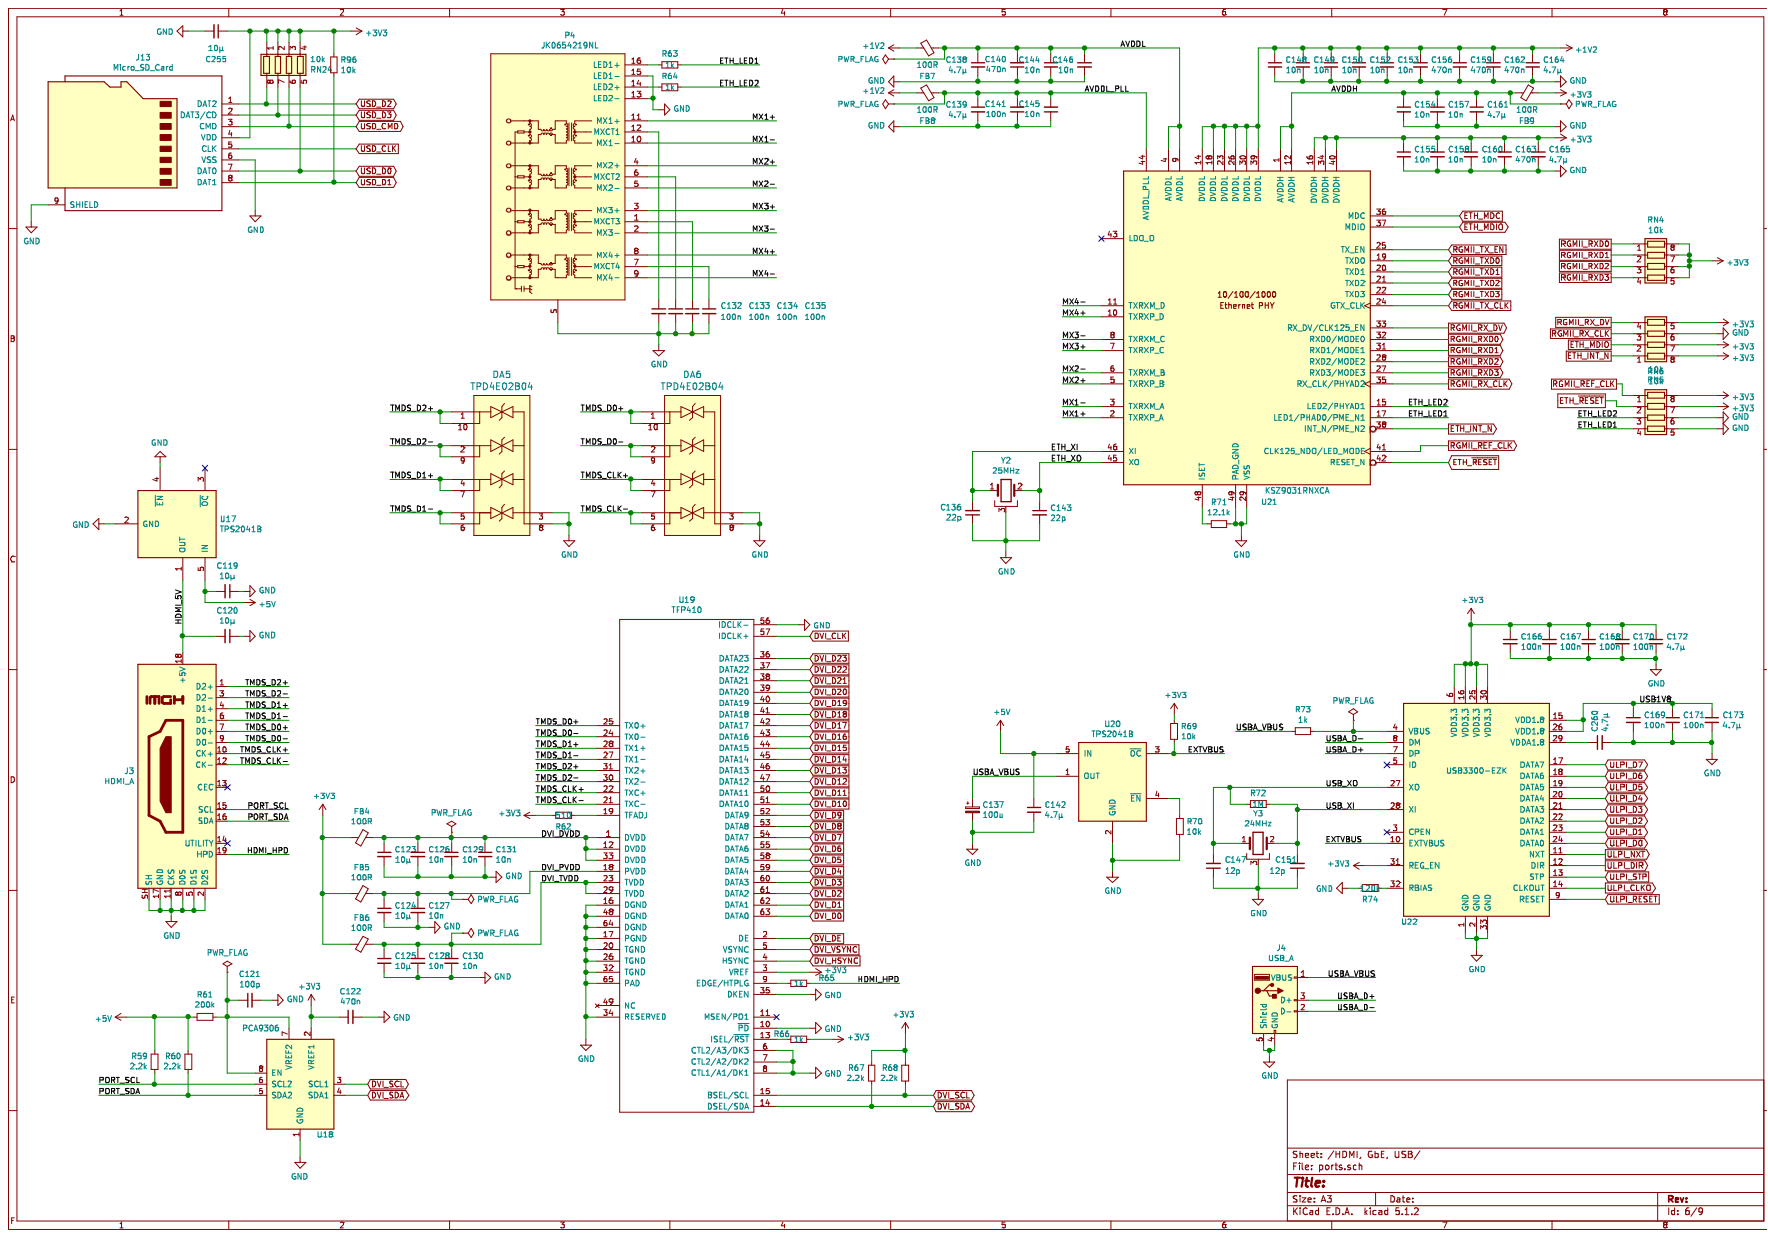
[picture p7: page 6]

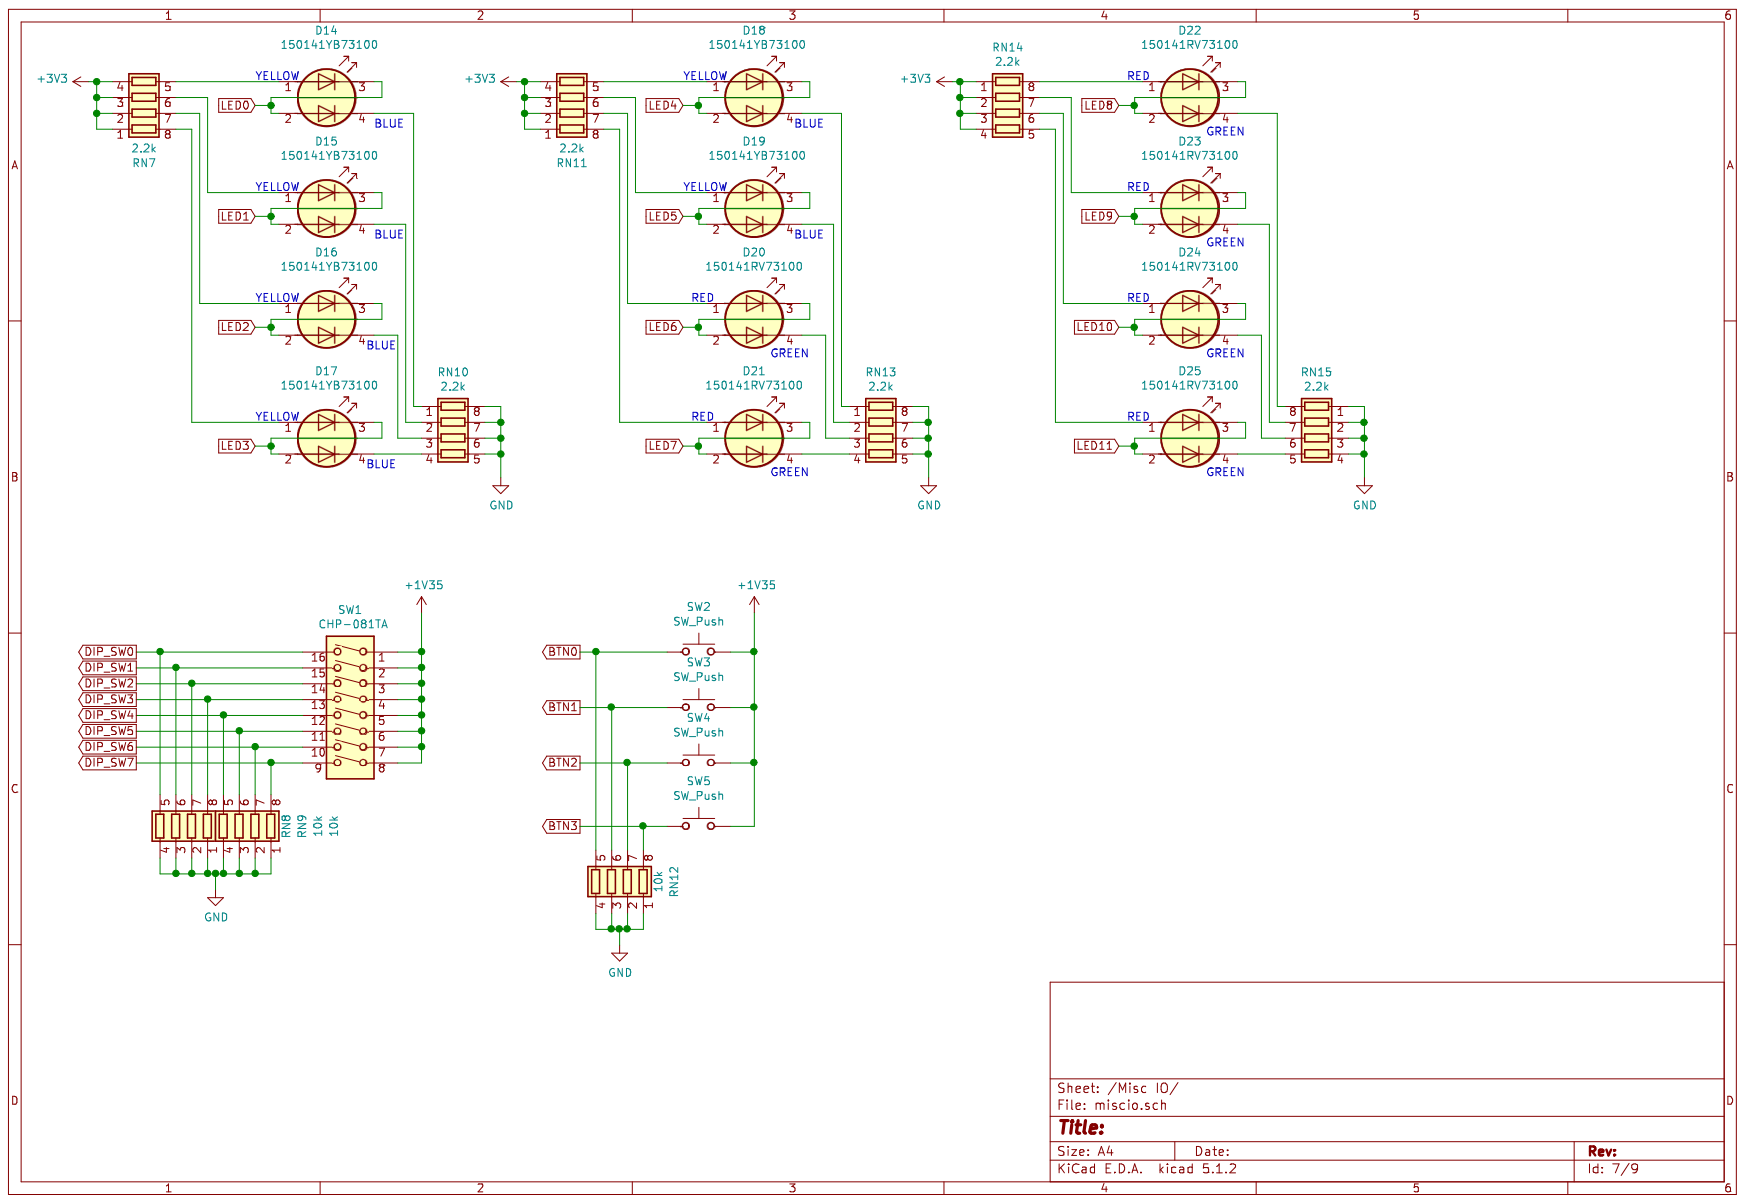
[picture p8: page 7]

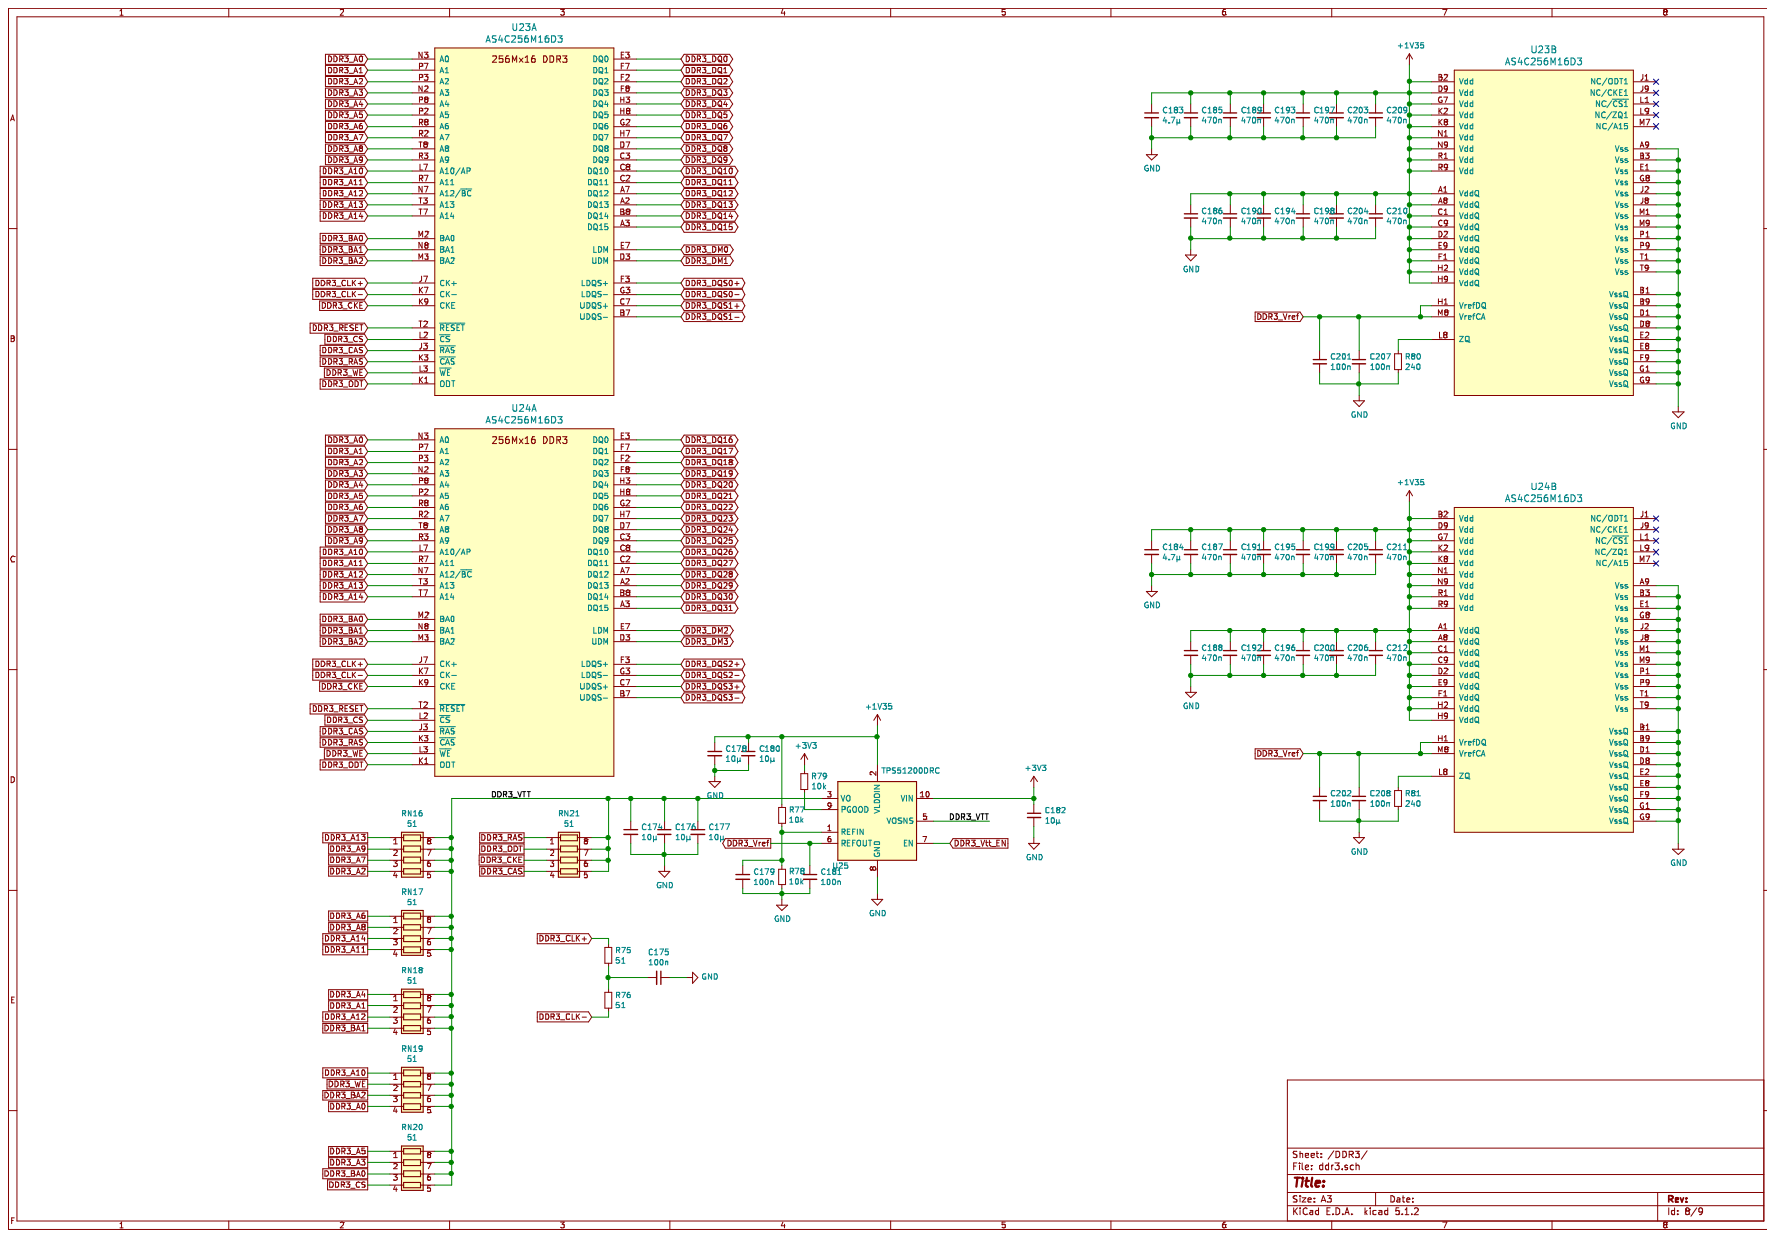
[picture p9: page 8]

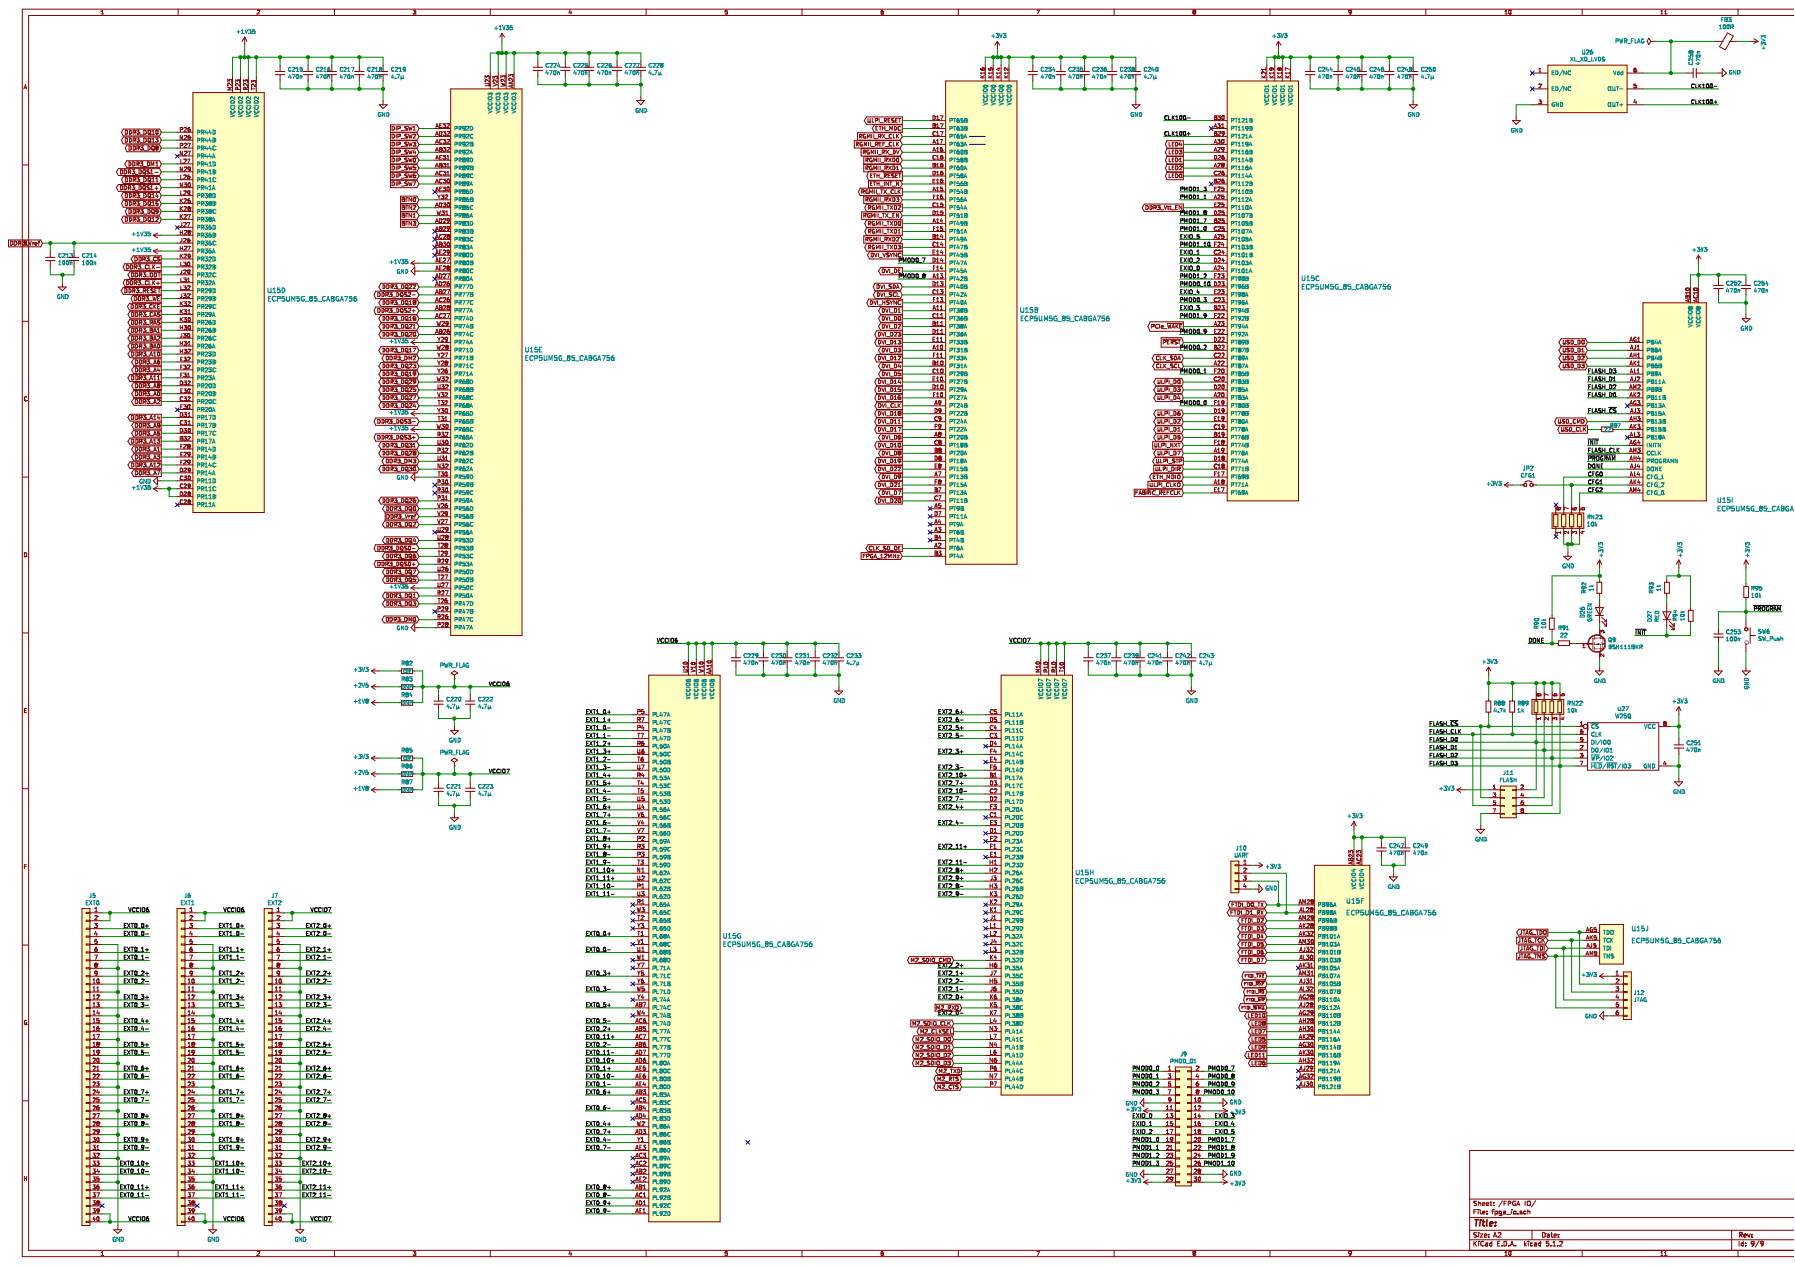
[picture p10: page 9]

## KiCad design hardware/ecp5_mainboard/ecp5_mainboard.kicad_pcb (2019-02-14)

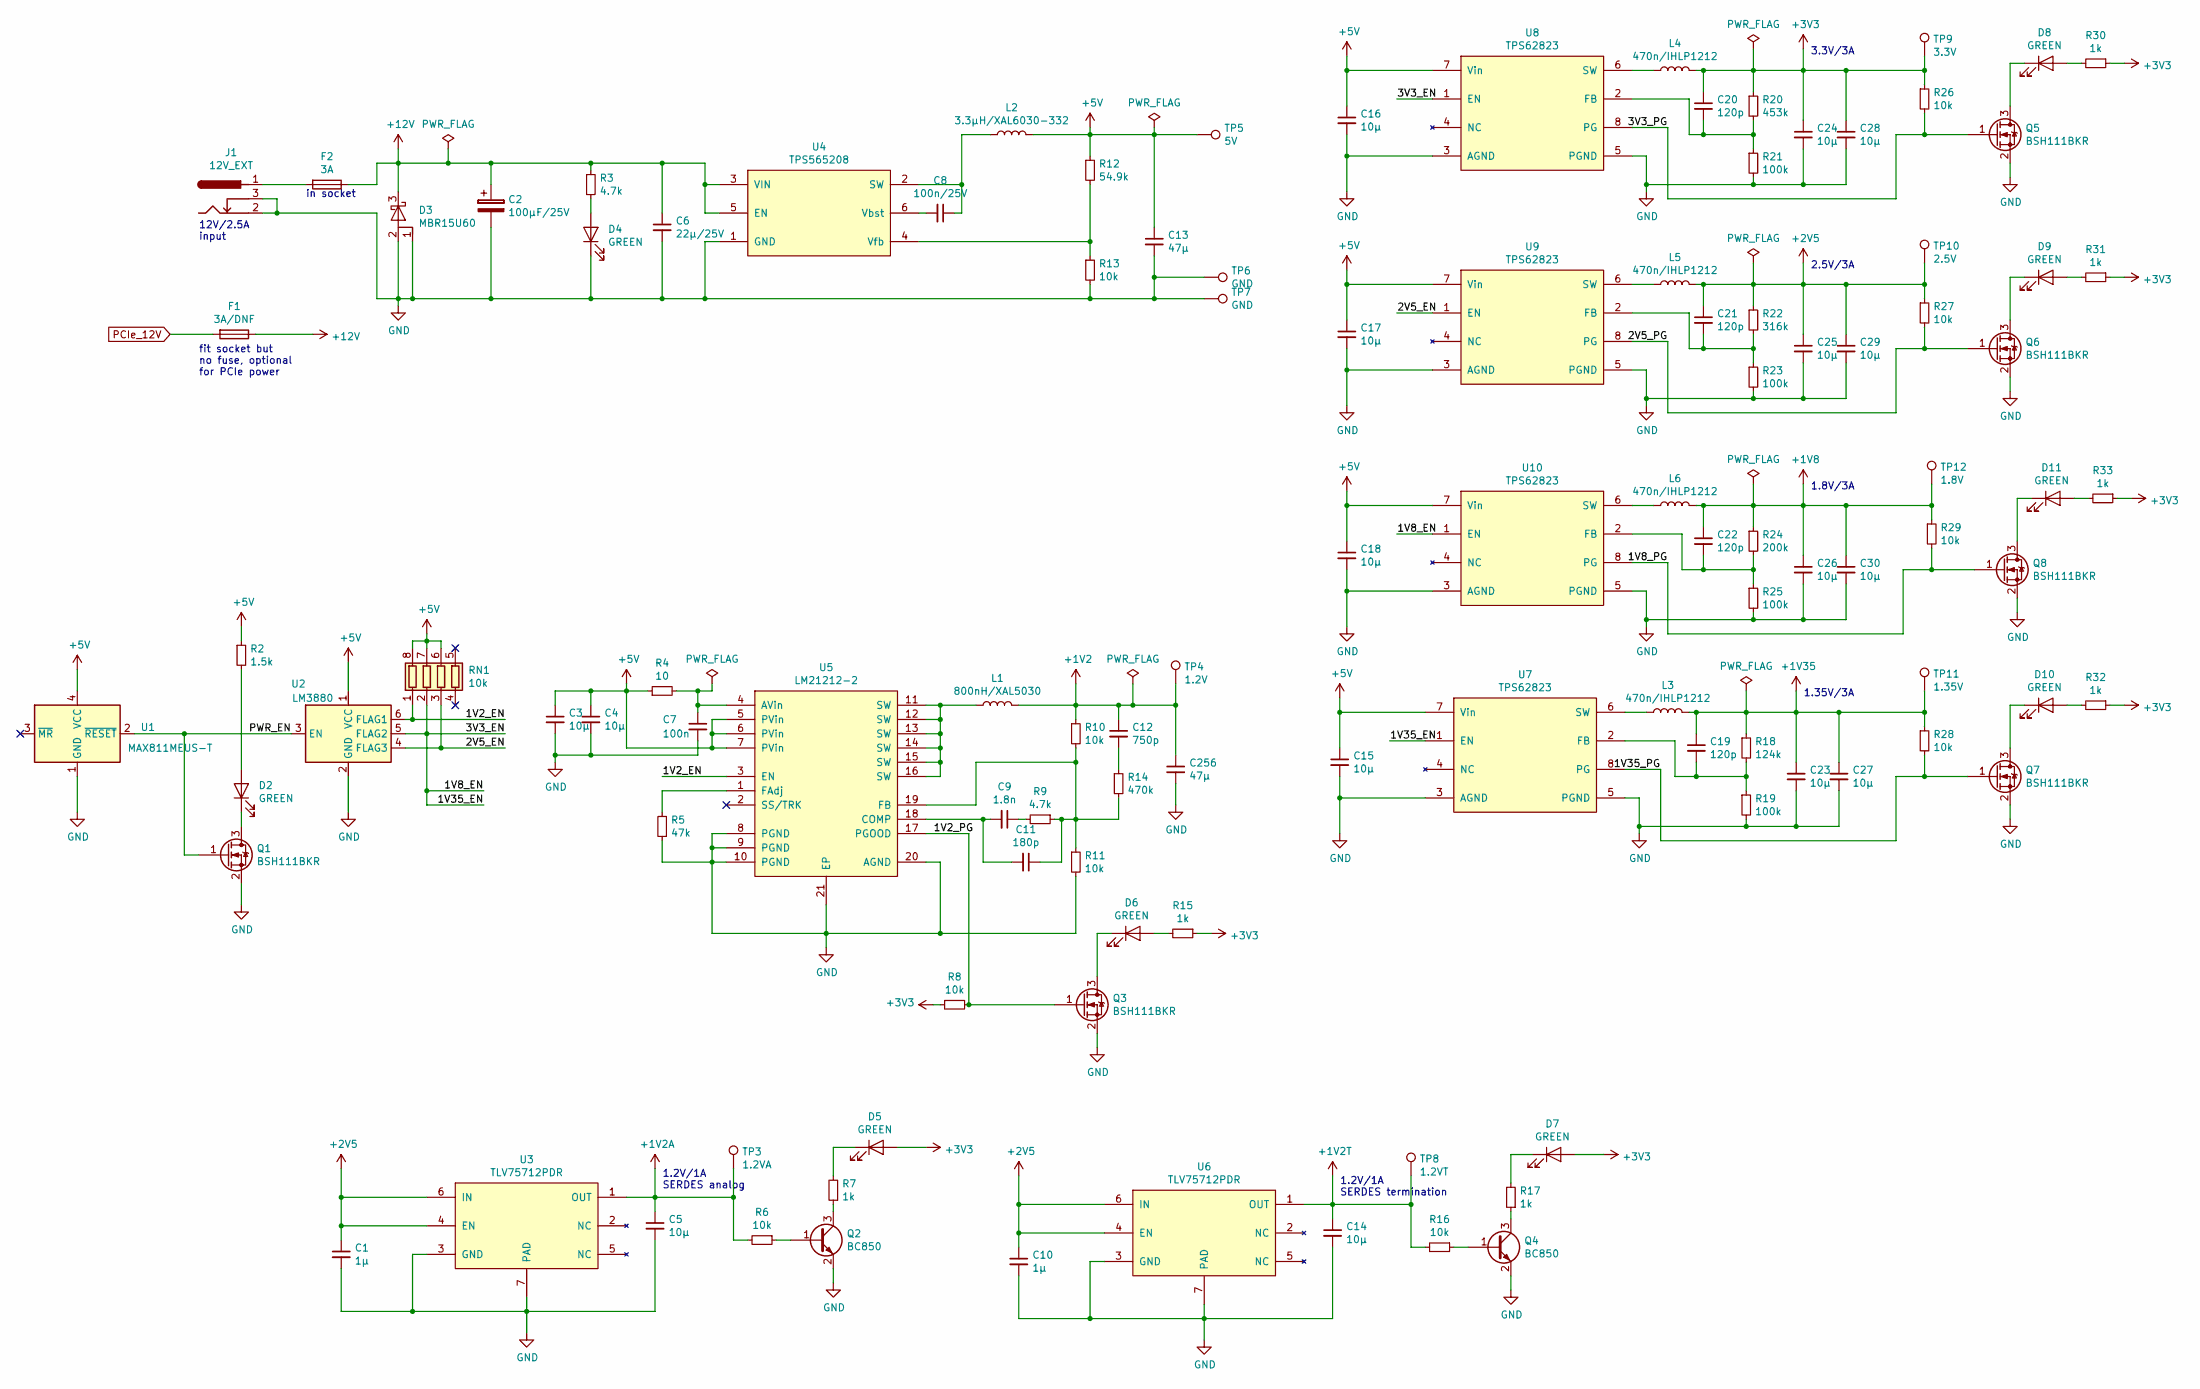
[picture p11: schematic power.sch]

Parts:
C1, C10: 1µ; C_0603_1608Metric
C2: 100µF/25V; CP_Elec_6.3x5.8
C3, C4, C5, C14, C15, C16, C17, C18, C23, C24, C25, C26, C27, C28, C29, C30: 10µ; C_0805_2012Metric
C6: 22µ/25V; C_1206_3216Metric
C7: 100n; C_0402_1005Metric
C8: 100n/25V; C_0805_2012Metric
C9: 1.8n; C_0402_1005Metric
C11: 180p; C_0402_1005Metric
C12: 750p; C_0402_1005Metric
C13, C256: 47µ; C_1210_3225Metric
C19, C20, C21, C22: 120p; C_0402_1005Metric
D2, D4, D5, D6, D7, D8, D9, D10, D11: GREEN; LED_0805_2012Metric
D3: MBR15U60; TO-277B
F1: 3A/DNF; FuseHolder_SMD_Shurter_0031.7701.11
F2: 3A; FuseHolder_SMD_Shurter_0031.7701.11
J1: 12V_EXT; BarrelJack_Horizontal
L1: 800nH/XAL5030; L_Coilcraft_XAL5030
L2: 3.3µH/XAL6030-332; L_CoilCraft_XAL60xx
L3, L4, L5, L6: 470n/IHLP1212; L_Vishay_IHLP-1212
Q1, Q3, Q5, Q6, Q7, Q8: BSH111BKR; SOT-23
Q2, Q4: BC850; SOT-23
R2: 1.5k; R_0402_1005Metric
R3, R9: 4.7k; R_0402_1005Metric
R4: 10; R_0402_1005Metric
R5: 47k; R_0402_1005Metric
R6, R8, R10, R11, R13, R16, R26, R27, R28, R29: 10k; R_0402_1005Metric
R7, R15, R17, R30, R31, R32, R33: 1k; R_0402_1005Metric
R12: 54.9k; R_0402_1005Metric
R14: 470k; R_0402_1005Metric
R18: 124k; R_0402_1005Metric
R19, R21, R23, R25: 100k; R_0402_1005Metric
R20: 453k; R_0402_1005Metric
R22: 316k; R_0402_1005Metric
R24: 200k; R_0402_1005Metric
RN1: 10k; R_Array_Convex_4x0402
TP3: 1.2VA; TestPoint_THTPad_1.5x1.5mm_Drill0.7mm
TP4: 1.2V; TestPoint_THTPad_1.5x1.5mm_Drill0.7mm
TP5: 5V; TestPoint_THTPad_1.5x1.5mm_Drill0.7mm
TP6, TP7: GND; TestPoint_THTPad_1.5x1.5mm_Drill0.7mm
TP8: 1.2VT; TestPoint_THTPad_1.5x1.5mm_Drill0.7mm
TP9: 3.3V; TestPoint_THTPad_1.5x1.5mm_Drill0.7mm
TP10: 2.5V; TestPoint_THTPad_1.5x1.5mm_Drill0.7mm
TP11: 1.35V; TestPoint_THTPad_1.5x1.5mm_Drill0.7mm
TP12: 1.8V; TestPoint_THTPad_1.5x1.5mm_Drill0.7mm
U1: MAX811MEUS-T; SOT-143
U2: LM3880; SOT-23-6
U3, U6: TLV75712PDR; TI_WSON8_2x2mm_p0.65mm
U4: TPS565208; SOT-23-6
U5: LM21212-2; HTSSOP-20-1EP_4.4x6.5mm_P0.65mm_EP3.4x6.5mm
U7, U8, U9, U10: TPS62823; TI_VSON-HR_1.5x2mm_p0.5mm

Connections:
+1V2: C12.1, C256.1, L1.2, R10.1, TP4.1; also elsewhere on the board
+1V2A: C5.1, R6.2, TP3.1, U3.1 (OUT); also elsewhere on the board
+1V2T: C14.1, R16.2, TP8.1, U6.1 (OUT); also elsewhere on the board
+1V8: C22.1, C26.1, C30.1, L6.2, R24.1, R29.1, TP12.1; also elsewhere on the board
+1V35: C19.1, C23.1, C27.1, L3.2, R18.1, R28.1, TP11.1; also elsewhere on the board
+2V5: C1.1, C10.1, C21.1, C25.1, C29.1, L5.2, R22.1, R27.1, TP10.1, U3.4 (EN), U3.6 (IN), U6.4 (EN), U6.6 (IN); also elsewhere on the board
+3V3: C20.1, C24.1, C28.1, D5.2 (A), D7.2 (A), L4.2, R8.2, R15.1, R20.1, R26.1, R30.1, R31.1, R32.1, R33.1, TP9.1; also elsewhere on the board
+5V: C3.1, C4.1, C13.1, C15.1, C16.1, C17.1, C18.1, L2.2, R2.1, R4.1, R12.1, RN1.6 (R3.2), RN1.7 (R2.2), RN1.8 (R1.2), TP5.1, U1.4 (VCC), U2.1 (VCC), U5.5 (PVin), U5.6 (PVin), U5.7 (PVin), U7.7 (Vin), U8.7 (Vin), U9.7 (Vin), U10.7 (Vin); also elsewhere on the board
+12V: C2.1, C6.1, D3.3 (K), F1.1, F2.1, R3.1, U4.3 (VIN), U4.5 (EN)
/Power/1V2_EN: RN1.1 (R1.1), U2.6 (FLAG1), U5.3 (EN)
/Power/1V2_PG: Q3.1 (G), R8.1, U5.17 (PGOOD)
/Power/1V8_PG: Q8.1 (G), R29.2, U10.8 (PG)
/Power/1V35_EN: RN1.2 (R2.1), U2.5 (FLAG2), U7.1 (EN), U8.1 (EN), U10.1 (EN)
/Power/1V35_PG: Q7.1 (G), R28.2, U7.8 (PG)
/Power/2V5_EN: RN1.3 (R3.1), U2.4 (FLAG3), U9.1 (EN)
/Power/2V5_PG: Q6.1 (G), R27.2, U9.8 (PG)
/Power/3V3_PG: Q5.1 (G), R26.2, U8.8 (PG)
/Power/PWR_EN: Q1.1 (G), U1.2 (~RESET), U2.3 (EN)
GND: C1.2, C2.2, C3.2, C4.2, C5.2, C6.2, C7.2, C10.2, C13.2, C14.2, C15.2, C16.2, C17.2, C18.2, C23.2, C24.2, C25.2, C26.2, C27.2, C28.2, C29.2, C30.2, C256.2, D3.1 (A), D3.2 (A), D4.1 (K), J1.2, J1.3, Q1.2 (S), Q2.2 (E), Q3.2 (S), Q4.2 (E), Q5.2 (S), Q6.2 (S), Q7.2 (S), Q8.2 (S), R5.1, R11.2, R13.2, R19.2, R21.2, R23.2, R25.2, TP6.1, TP7.1, U1.1 (GND), U2.2 (GND), U3.3 (GND), U3.7 (PAD), U4.1 (GND), U5.8 (PGND), U5.9 (PGND), U5.10 (PGND), U5.20 (AGND), U5.21 (EP), U6.3 (GND), U6.7 (PAD), U7.3 (AGND), U7.5 (PGND), U8.3 (AGND), U8.5 (PGND), U9.3 (AGND), U9.5 (PGND), U10.3 (AGND), U10.5 (PGND); also elsewhere on the board
unnamed: C7.1, R4.2, U5.4 (AVin)
unnamed: C8.1, L2.1, U4.2 (SW)
unnamed: C8.2, U4.6 (Vbst)
unnamed: C9.1, R9.2
unnamed: C11.1, R9.1, R10.2, R11.1, R14.2, U5.19 (FB)
unnamed: C9.2, C11.2, U5.18 (COMP)
unnamed: C12.2, R14.1
unnamed: C19.2, R18.2, R19.1, U7.2 (FB)
unnamed: C20.2, R20.2, R21.1, U8.2 (FB)
unnamed: C21.2, R22.2, R23.1, U9.2 (FB)
unnamed: C22.2, R24.2, R25.1, U10.2 (FB)
unnamed: D2.1 (K), Q1.3 (D)
unnamed: D2.2 (A), R2.2
unnamed: D4.2 (A), R3.2
unnamed: D5.1 (K), R7.2
unnamed: D6.1 (K), Q3.3 (D)
unnamed: D6.2 (A), R15.2
unnamed: D7.1 (K), R17.2
unnamed: D8.1 (K), Q5.3 (D)
unnamed: D8.2 (A), R30.2
unnamed: D9.1 (K), Q6.3 (D)
unnamed: D9.2 (A), R31.2
unnamed: D10.1 (K), Q7.3 (D)
unnamed: D10.2 (A), R32.2
unnamed: D11.1 (K), Q8.3 (D)
unnamed: D11.2 (A), R33.2
unnamed: F2.2, J1.1
unnamed: L1.1, U5.11 (SW), U5.12 (SW), U5.13 (SW), U5.14 (SW), U5.15 (SW), U5.16 (SW)
unnamed: L3.1, U7.6 (SW)
unnamed: L4.1, U8.6 (SW)
unnamed: L5.1, U9.6 (SW)
unnamed: L6.1, U10.6 (SW)
unnamed: Q2.1 (B), R6.1
unnamed: Q2.3 (C), R7.1
unnamed: Q4.1 (B), R16.1
unnamed: Q4.3 (C), R17.1
unnamed: R5.2, U5.1 (FAdj)
unnamed: R12.2, R13.1, U4.4 (Vfb)
PCIe_12V: F1.2; also elsewhere on the board

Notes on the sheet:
in socket
fit socket but no fuse, optional for PCIe power
12V/2.5A input
3.3V/3A
2.5V/3A
1.8V/3A
1.35V/3A
1.2V/1A SERDES analog
1.2V/1A SERDES termination

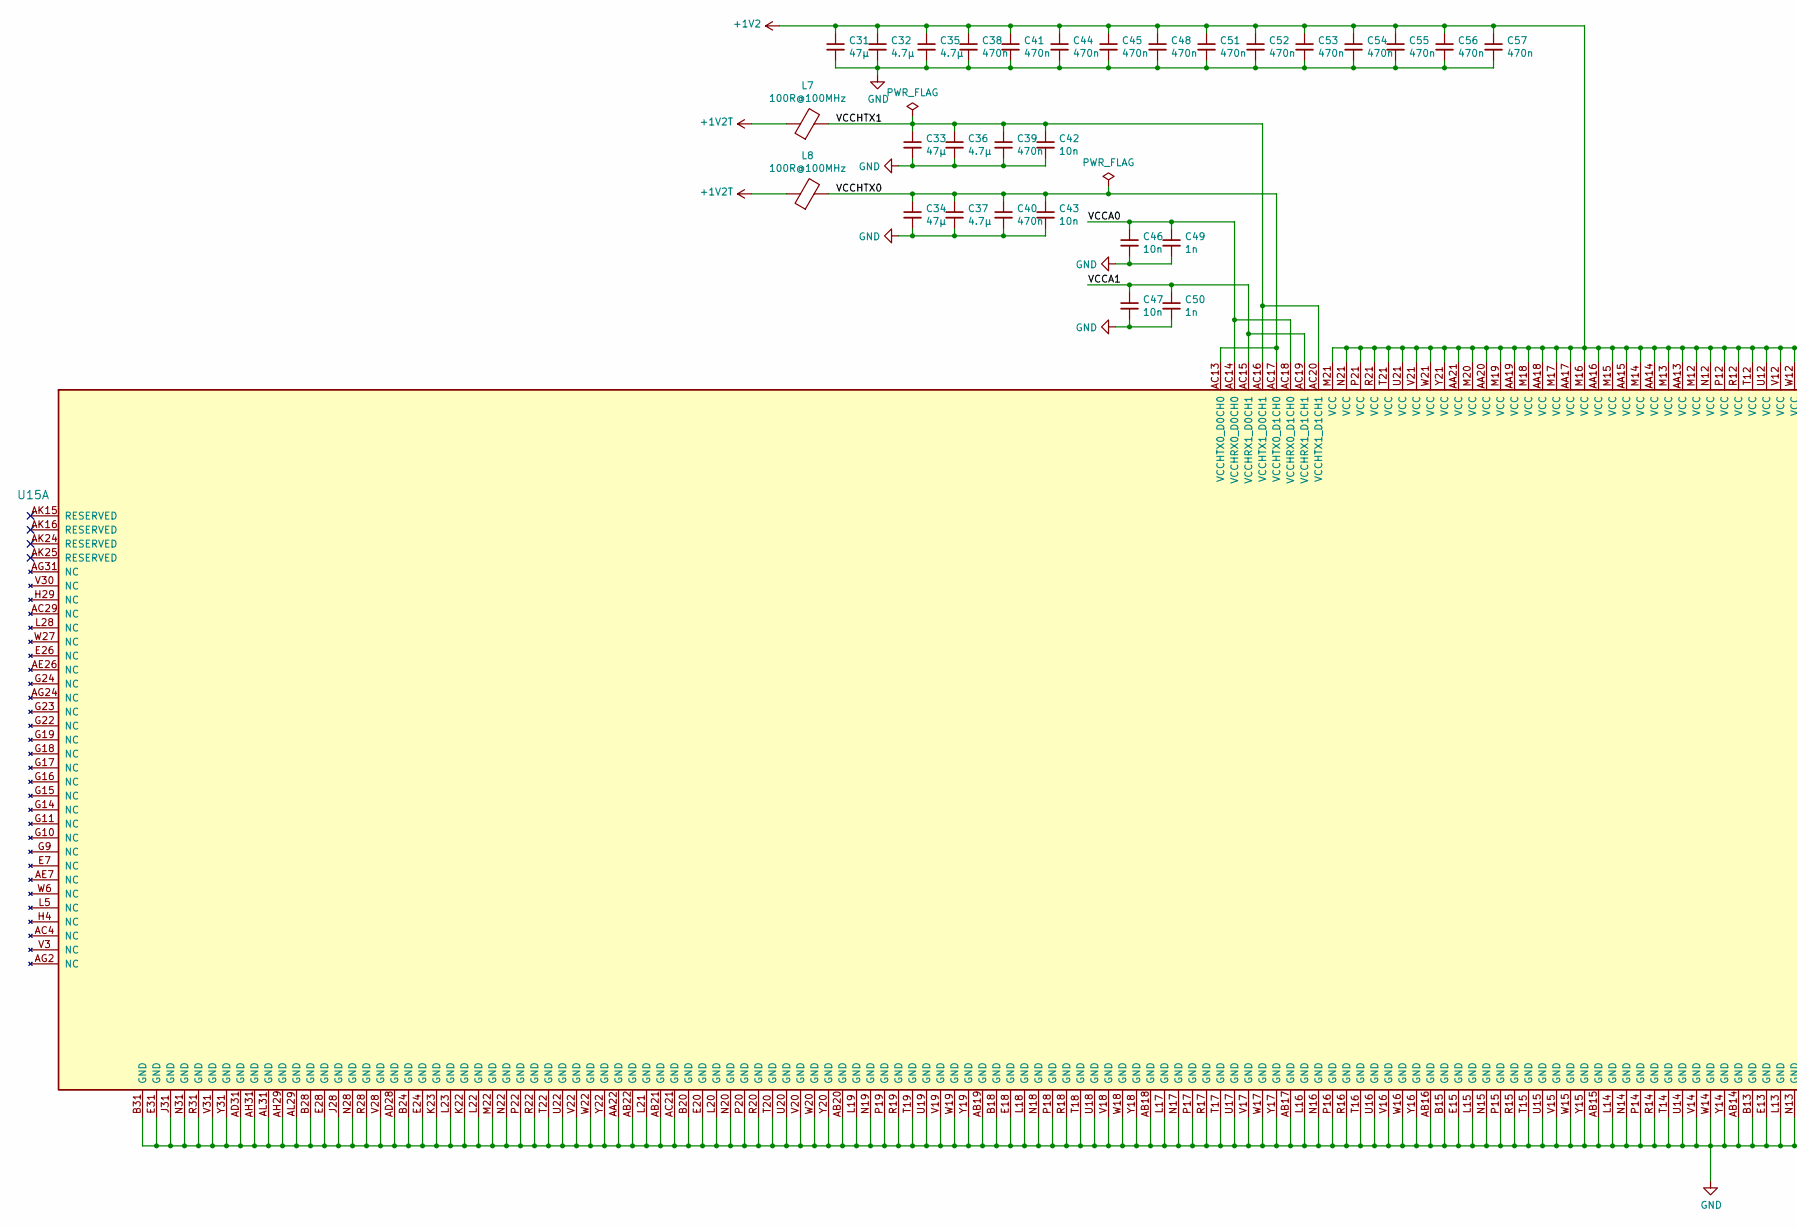
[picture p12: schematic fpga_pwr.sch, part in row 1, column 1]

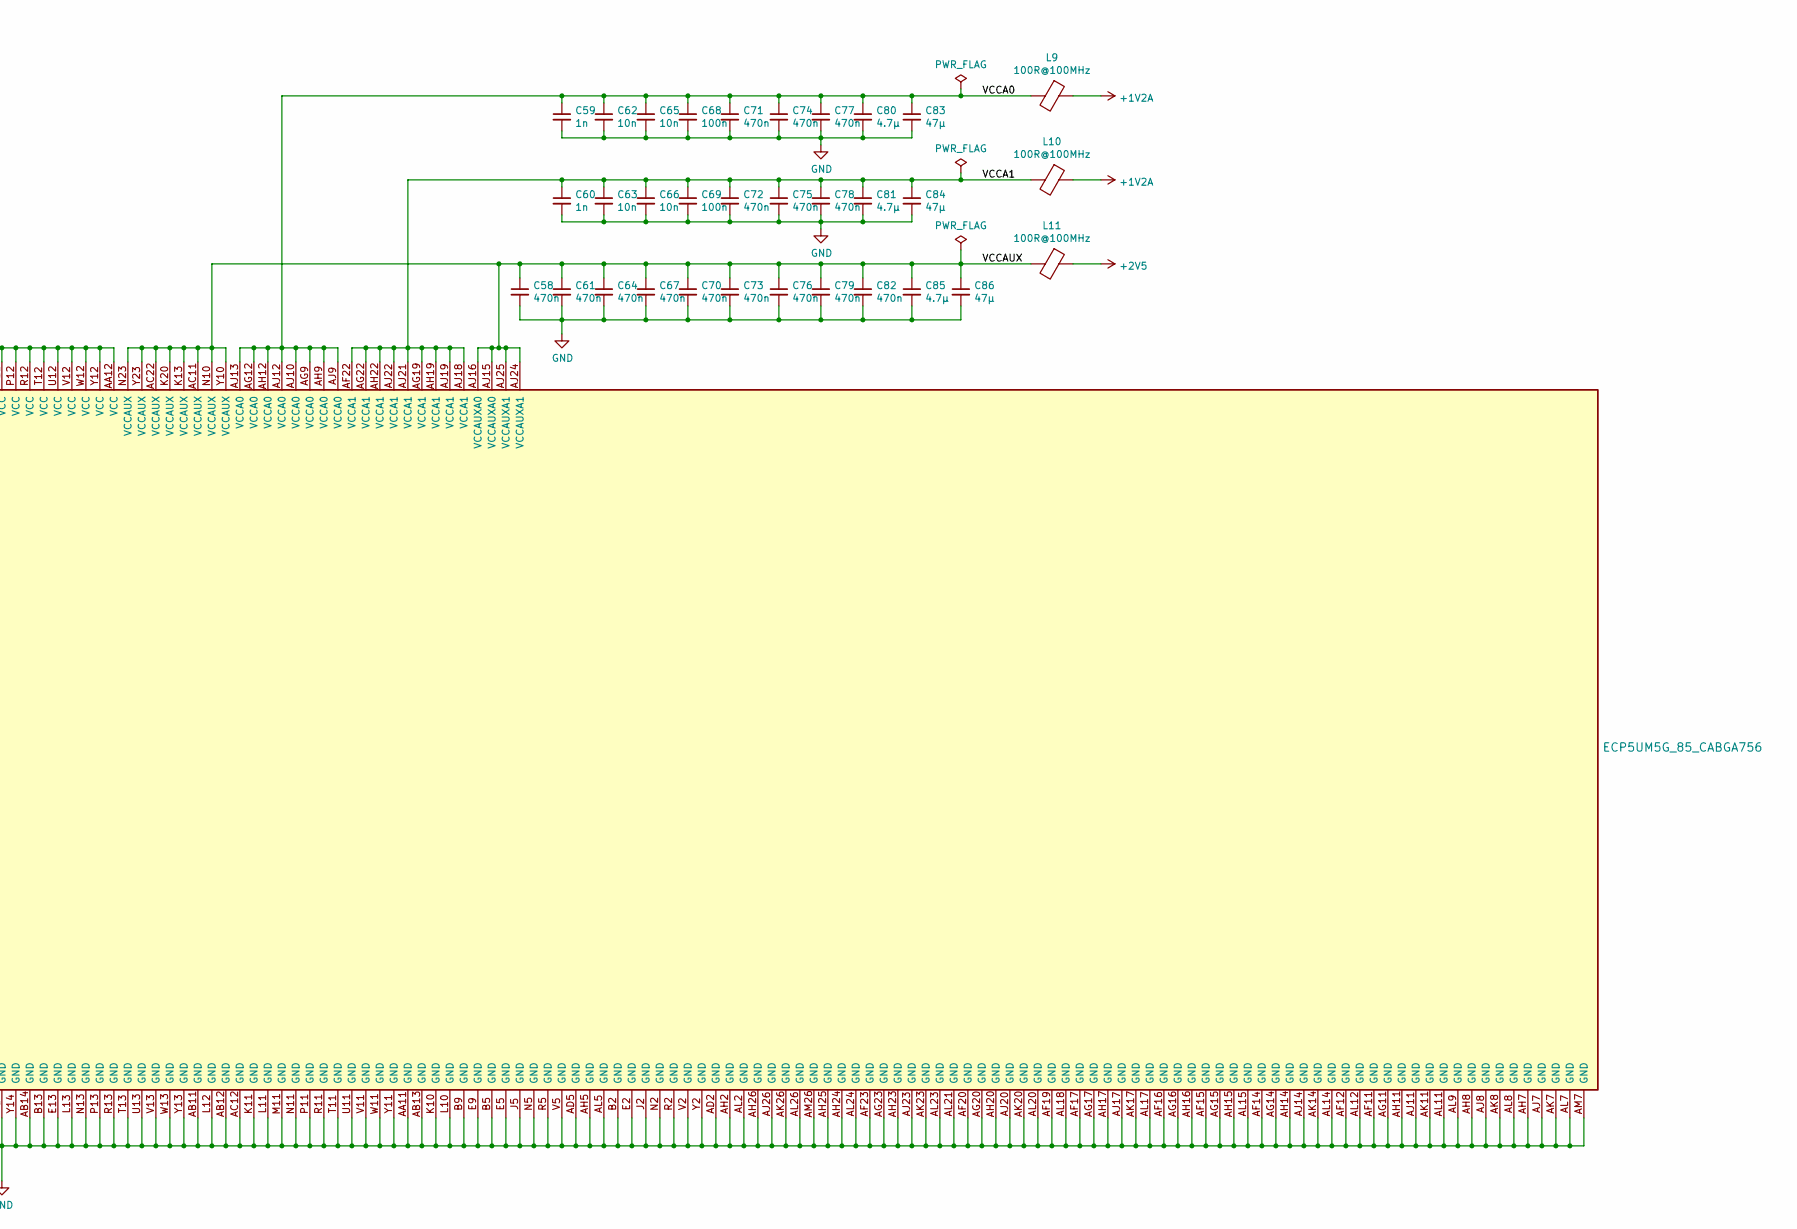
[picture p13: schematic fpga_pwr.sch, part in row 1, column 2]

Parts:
C31, C33, C34, C83, C84: 47µ; C_1210_3225Metric
C32, C35, C36, C37, C80, C81, C85: 4.7µ; C_0603_1608Metric
C38, C39, C40, C41, C44, C45, C48, C51, C52, C53, C54, C55, C56, C57, C58, C61, C64, C67, C70, C71, C72, C73, C74, C75, C76, C77, C78, C79, C82: 470n; C_0402_1005Metric
C42, C43, C46, C47, C62, C63, C65, C66: 10n; C_0201_0603Metric
C49, C50, C59, C60: 1n; C_0201_0603Metric
C68, C69: 100n; C_0402_1005Metric
C86: 47µ; C_1206_3216Metric
L7, L8, L9, L10, L11: 100R@100MHz; L_0603_1608Metric
U15: ECP5UM5G_85_CABGA756; CABGA756_27x27mm_p0.8mm

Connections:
+1V2: C31.1, C32.1, C35.1, C38.1, C41.1, C44.1, C45.1, C48.1, C51.1, C52.1, C53.1, C54.1, C55.1, C56.1, C57.1, U15.AA12 (VCC), U15.AA13 (VCC), U15.AA14 (VCC), U15.AA15 (VCC), U15.AA16 (VCC), U15.AA17 (VCC), U15.AA18 (VCC), U15.AA19 (VCC), U15.AA20 (VCC), U15.AA21 (VCC), U15.M12 (VCC), U15.M13 (VCC), U15.M14 (VCC), U15.M15 (VCC), U15.M16 (VCC), U15.M17 (VCC), U15.M18 (VCC), U15.M19 (VCC), U15.M20 (VCC), U15.M21 (VCC), U15.N12 (VCC), U15.N21 (VCC), U15.P12 (VCC), U15.P21 (VCC), U15.R12 (VCC), U15.R21 (VCC), U15.T12 (VCC), U15.T21 (VCC), U15.U12 (VCC), U15.U21 (VCC), U15.V12 (VCC), U15.V21 (VCC), U15.W12 (VCC), U15.W21 (VCC), U15.Y12 (VCC), U15.Y21 (VCC); also elsewhere on the board
+1V2A: L9.1, L10.1; also elsewhere on the board
+1V2T: L7.1, L8.1; also elsewhere on the board
+2V5: L11.1; also elsewhere on the board
/FPGA Core Power/VCCA0: C46.1, C49.1, C59.1, C62.1, C65.1, C68.1, C71.1, C74.1, C77.1, C80.1, C83.1, L9.2, U15.AC14 (VCCHRX0_D0CH0), U15.AC18 (VCCHRX0_D1CH0), U15.AG9 (VCCA0), U15.AG12 (VCCA0), U15.AH9 (VCCA0), U15.AH12 (VCCA0), U15.AJ9 (VCCA0), U15.AJ10 (VCCA0), U15.AJ12 (VCCA0), U15.AJ13 (VCCA0)
/FPGA Core Power/VCCA1: C47.1, C50.1, C60.1, C63.1, C66.1, C69.1, C72.1, C75.1, C78.1, C81.1, C84.1, L10.2, U15.AC15 (VCCHRX1_D0CH1), U15.AC19 (VCCHRX1_D1CH1), U15.AF22 (VCCA1), U15.AG19 (VCCA1), U15.AG22 (VCCA1), U15.AH19 (VCCA1), U15.AH22 (VCCA1), U15.AJ18 (VCCA1), U15.AJ19 (VCCA1), U15.AJ21 (VCCA1), U15.AJ22 (VCCA1)
/FPGA Core Power/VCCAUX: C58.1, C61.1, C64.1, C67.1, C70.1, C73.1, C76.1, C79.1, C82.1, C85.1, C86.1, L11.2, U15.AC11 (VCCAUX), U15.AC22 (VCCAUX), U15.AJ15 (VCCAUXA0), U15.AJ16 (VCCAUXA0), U15.AJ24 (VCCAUXA1), U15.AJ25 (VCCAUXA1), U15.K13 (VCCAUX), U15.K20 (VCCAUX), U15.N10 (VCCAUX), U15.N23 (VCCAUX), U15.Y10 (VCCAUX), U15.Y23 (VCCAUX)
/FPGA Core Power/VCCHTX0: C34.1, C37.1, C40.1, C43.1, L8.2, U15.AC13 (VCCHTX0_D0CH0), U15.AC17 (VCCHTX0_D1CH0)
/FPGA Core Power/VCCHTX1: C33.1, C36.1, C39.1, C42.1, L7.2, U15.AC16 (VCCHTX1_D0CH1), U15.AC20 (VCCHTX1_D1CH1)
GND: C31.2, C32.2, C33.2, C34.2, C35.2, C36.2, C37.2, C38.2, C39.2, C40.2, C41.2, C42.2, C43.2, C44.2, C45.2, C46.2, C47.2, C48.2, C49.2, C50.2, C51.2, C52.2, C53.2, C54.2, C55.2, C56.2, C57.2, C58.2, C59.2, C60.2, C61.2, C62.2, C63.2, C64.2, C65.2, C66.2, C67.2, C68.2, C69.2, C70.2, C71.2, C72.2, C73.2, C74.2, C75.2, C76.2, C77.2, C78.2, C79.2, C80.2, C81.2, C82.2, C83.2, C84.2, C85.2, C86.2, U15.AA11 (GND), U15.AA22 (GND), U15.AB11 (GND), U15.AB12 (GND), U15.AB13 (GND), U15.AB14 (GND), U15.AB15 (GND), U15.AB16 (GND), U15.AB17 (GND), U15.AB18 (GND), U15.AB19 (GND), U15.AB20 (GND), U15.AB21 (GND), U15.AB22 (GND), U15.AC12 (GND), U15.AC21 (GND), U15.AD2 (GND), U15.AD5 (GND), U15.AD28 (GND), U15.AD31 (GND), U15.AF11 (GND), U15.AF12 (GND), U15.AF14 (GND), U15.AF15 (GND), U15.AF16 (GND), U15.AF17 (GND), U15.AF19 (GND), U15.AF20 (GND), U15.AF23 (GND), U15.AG11 (GND), U15.AG14 (GND), U15.AG15 (GND), U15.AG16 (GND), U15.AG17 (GND), U15.AG20 (GND), U15.AG23 (GND), U15.AH2 (GND), U15.AH5 (GND), U15.AH7 (GND), U15.AH8 (GND), U15.AH11 (GND), U15.AH14 (GND), U15.AH15 (GND), U15.AH16 (GND), U15.AH17 (GND), U15.AH20 (GND), U15.AH23 (GND), U15.AH24 (GND), U15.AH25 (GND), U15.AH26 (GND), U15.AH29 (GND), U15.AH31 (GND), U15.AJ7 (GND), U15.AJ8 (GND), U15.AJ11 (GND), U15.AJ14 (GND), U15.AJ17 (GND), U15.AJ20 (GND), U15.AJ23 (GND), U15.AJ26 (GND), U15.AK7 (GND), U15.AK8 (GND), U15.AK11 (GND), U15.AK14 (GND), U15.AK17 (GND), U15.AK20 (GND), U15.AK23 (GND), U15.AK26 (GND), U15.AL2 (GND), U15.AL5 (GND), U15.AL7 (GND), U15.AL8 (GND), U15.AL9 (GND), U15.AL11 (GND), U15.AL12 (GND), U15.AL14 (GND), U15.AL15 (GND), U15.AL17 (GND), U15.AL18 (GND), U15.AL20 (GND), U15.AL21 (GND), U15.AL23 (GND), U15.AL24 (GND), U15.AL26 (GND), U15.AL29 (GND), U15.AL31 (GND), U15.AM7 (GND), U15.AM26 (GND), U15.B2 (GND), U15.B5 (GND), U15.B9 (GND), U15.B13 (GND), U15.B15 (GND), U15.B18 (GND), U15.B20 (GND), U15.B24 (GND), U15.B28 (GND), U15.B31 (GND), U15.E2 (GND), U15.E5 (GND), U15.E9 (GND), U15.E13 (GND), U15.E15 (GND), U15.E18 (GND), U15.E20 (GND), U15.E24 (GND), U15.E28 (GND), U15.E31 (GND), U15.J2 (GND), U15.J5 (GND), U15.J28 (GND), U15.J31 (GND), U15.K10 (GND), U15.K11 (GND), U15.K22 (GND), U15.K23 (GND), U15.L10 (GND), U15.L11 (GND), U15.L12 (GND), U15.L13 (GND), U15.L14 (GND), U15.L15 (GND), U15.L16 (GND), U15.L17 (GND), U15.L18 (GND), U15.L19 (GND), U15.L20 (GND), U15.L21 (GND), U15.L22 (GND), U15.L23 (GND), U15.M11 (GND), U15.M22 (GND), U15.N2 (GND), U15.N5 (GND), U15.N11 (GND), U15.N13 (GND), U15.N14 (GND), U15.N15 (GND), U15.N16 (GND), U15.N17 (GND), U15.N18 (GND), U15.N19 (GND), U15.N20 (GND), U15.N22 (GND), U15.N28 (GND), U15.N31 (GND), U15.P11 (GND), U15.P13 (GND), U15.P14 (GND), U15.P15 (GND), U15.P16 (GND), U15.P17 (GND), U15.P18 (GND), U15.P19 (GND), U15.P20 (GND), U15.P22 (GND), U15.R2 (GND), U15.R5 (GND), U15.R11 (GND), U15.R13 (GND), U15.R14 (GND), U15.R15 (GND), U15.R16 (GND), U15.R17 (GND), U15.R18 (GND), U15.R19 (GND), U15.R20 (GND), U15.R22 (GND), U15.R28 (GND), U15.R31 (GND), U15.T11 (GND), U15.T13 (GND), U15.T14 (GND), U15.T15 (GND), U15.T16 (GND), U15.T17 (GND), U15.T18 (GND), U15.T19 (GND), U15.T20 (GND), U15.T22 (GND), U15.U11 (GND), U15.U13 (GND), U15.U14 (GND), U15.U15 (GND), U15.U16 (GND), U15.U17 (GND), U15.U18 (GND), U15.U19 (GND), U15.U20 (GND), U15.U22 (GND), U15.V2 (GND), U15.V5 (GND), U15.V11 (GND), U15.V13 (GND), U15.V14 (GND), U15.V15 (GND), U15.V16 (GND), U15.V17 (GND), U15.V18 (GND), U15.V19 (GND), U15.V20 (GND), U15.V22 (GND), U15.V28 (GND), U15.V31 (GND), U15.W11 (GND), U15.W13 (GND), U15.W14 (GND), U15.W15 (GND), U15.W16 (GND), U15.W17 (GND), U15.W18 (GND), U15.W19 (GND), U15.W20 (GND), U15.W22 (GND), U15.Y2 (GND), U15.Y11 (GND), U15.Y13 (GND), U15.Y14 (GND), U15.Y15 (GND), U15.Y16 (GND), U15.Y17 (GND), U15.Y18 (GND), U15.Y19 (GND), U15.Y20 (GND), U15.Y22 (GND), U15.Y31 (GND); also elsewhere on the board

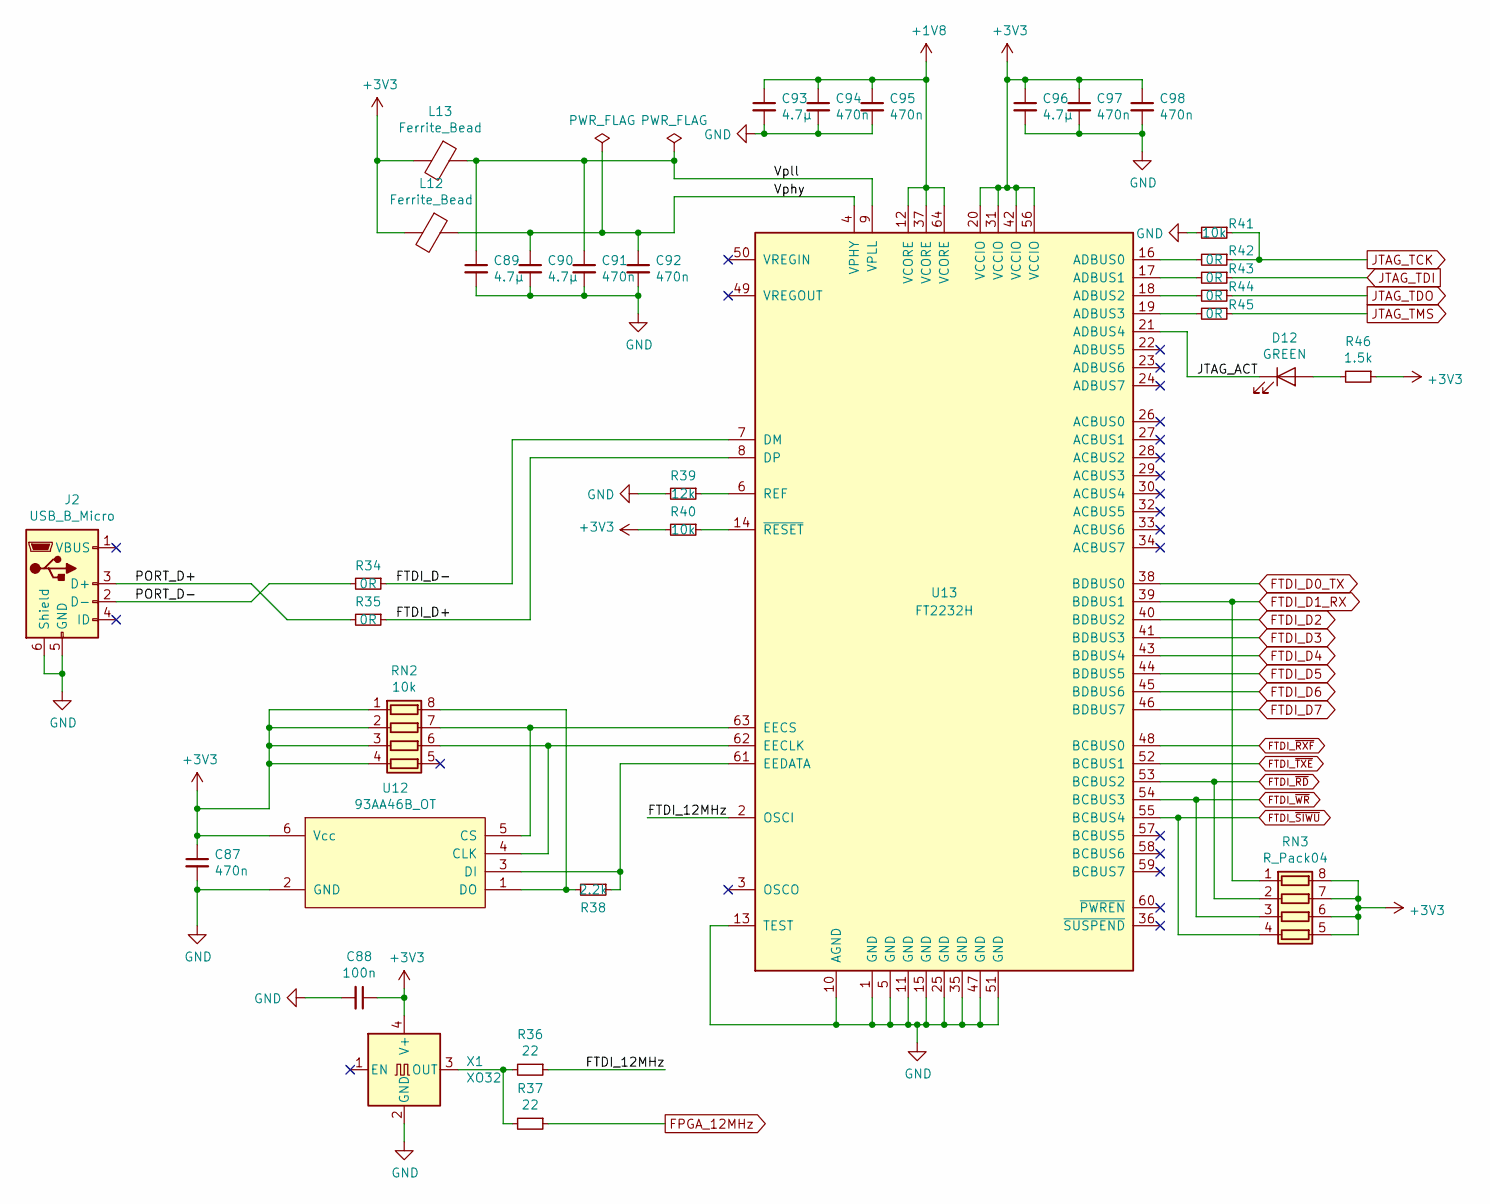
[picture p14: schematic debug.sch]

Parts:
C87, C91, C92, C94, C95, C97, C98: 470n; C_0402_1005Metric
C88: 100n; C_0402_1005Metric
C89, C90, C93, C96: 4.7µ; C_0603_1608Metric
D12: GREEN; LED_0805_2012Metric
J2: USB_B_Micro; USB_Micro-B_Molex-105017-0001
L12, L13: Ferrite_Bead; L_0603_1608Metric
R34, R35: 0R; R_0402_1005Metric
R36, R37: 22; R_0402_1005Metric
R38: 2.2k; R_0402_1005Metric
R39: 12k; R_0402_1005Metric
R40, R41: 10k; R_0402_1005Metric
R42, R43, R44, R45: 0R; R_0805_2012Metric
R46: 1.5k; R_0402_1005Metric
RN2: 10k; R_Array_Convex_4x0402
RN3: R_Pack04; R_Array_Convex_4x0402
U12: 93AA46B_OT; SOT-23-6
U13: FT2232H; LQFP-64_10x10mm_P0.5mm
X1: XO32; Oscillator_SMD_EuroQuartz_XO32-4Pin_3.2x2.5mm

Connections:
+1V8: C93.1, C94.1, C95.1, U13.12 (VCORE), U13.37 (VCORE), U13.64 (VCORE); also elsewhere on the board
+3V3: C87.1, C88.1, C96.1, C97.1, C98.1, L12.2, L13.2, R40.2, R46.1, RN2.1 (R1.1), RN2.2 (R2.1), RN2.3 (R3.1), RN2.4 (R4.1), RN3.5 (R4.2), RN3.6 (R3.2), RN3.7 (R2.2), RN3.8 (R1.2), U12.6 (Vcc), U13.20 (VCCIO), U13.31 (VCCIO), U13.42 (VCCIO), U13.56 (VCCIO), X1.4 (V+); also elsewhere on the board
/Debug Interface/FTDI_12MHz: R36.1, U13.2 (OSCI)
/Debug Interface/FTDI_D+: R35.1, U13.8 (DP)
/Debug Interface/FTDI_D-: R34.1, U13.7 (DM)
/Debug Interface/JTAG_ACT: D12.1 (K), U13.21 (ADBUS4)
/Debug Interface/PORT_D+: J2.3 (D+), R35.2
/Debug Interface/PORT_D-: J2.2 (D-), R34.2
/Debug Interface/Vphy: C90.1, C92.1, L12.1, U13.4 (VPHY)
/Debug Interface/Vpll: C89.1, C91.1, L13.1, U13.9 (VPLL)
FPGA_12MHz: R37.1; also elsewhere on the board
FTDI_D0_TX: U13.38 (BDBUS0); also elsewhere on the board
FTDI_D1_RX: RN3.1 (R1.1), U13.39 (BDBUS1); also elsewhere on the board
FTDI_D2: U13.40 (BDBUS2); also elsewhere on the board
FTDI_D3: U13.41 (BDBUS3); also elsewhere on the board
FTDI_D4: U13.43 (BDBUS4); also elsewhere on the board
FTDI_D5: U13.44 (BDBUS5); also elsewhere on the board
FTDI_D6: U13.45 (BDBUS6); also elsewhere on the board
FTDI_D7: U13.46 (BDBUS7); also elsewhere on the board
FTDI_~RD: RN3.2 (R2.1), U13.53 (BCBUS2); also elsewhere on the board
FTDI_~RXF: U13.48 (BCBUS0); also elsewhere on the board
FTDI_~SIWU: RN3.4 (R4.1), U13.55 (BCBUS4); also elsewhere on the board
FTDI_~TXE: U13.52 (BCBUS1); also elsewhere on the board
FTDI_~WR: RN3.3 (R3.1), U13.54 (BCBUS3); also elsewhere on the board
GND: C87.2, C88.2, C89.2, C90.2, C91.2, C92.2, C93.2, C94.2, C95.2, C96.2, C97.2, C98.2, J2.5 (GND), J2.6 (Shield), R39.2, R41.2, U12.2 (GND), U13.1 (GND), U13.5 (GND), U13.10 (AGND), U13.11 (GND), U13.13 (TEST), U13.15 (GND), U13.25 (GND), U13.35 (GND), U13.47 (GND), U13.51 (GND), X1.2 (GND); also elsewhere on the board
JTAG_TCK: R41.1, R42.1; also elsewhere on the board
JTAG_TDI: R43.1; also elsewhere on the board
JTAG_TDO: R44.1; also elsewhere on the board
JTAG_TMS: R45.1; also elsewhere on the board
unnamed: D12.2 (A), R46.2
unnamed: R36.2, R37.2, X1.3 (OUT)
unnamed: R38.1, U12.3 (DI), U13.61 (EEDATA)
unnamed: R38.2, RN2.8 (R1.2), U12.1 (DO)
unnamed: R39.1, U13.6 (REF)
unnamed: R40.1, U13.14 (~RESET)
unnamed: R42.2, U13.16 (ADBUS0)
unnamed: R43.2, U13.17 (ADBUS1)
unnamed: R44.2, U13.18 (ADBUS2)
unnamed: R45.2, U13.19 (ADBUS3)
unnamed: RN2.6 (R3.2), U12.4 (CLK), U13.62 (EECLK)
unnamed: RN2.7 (R2.2), U12.5 (CS), U13.63 (EECS)

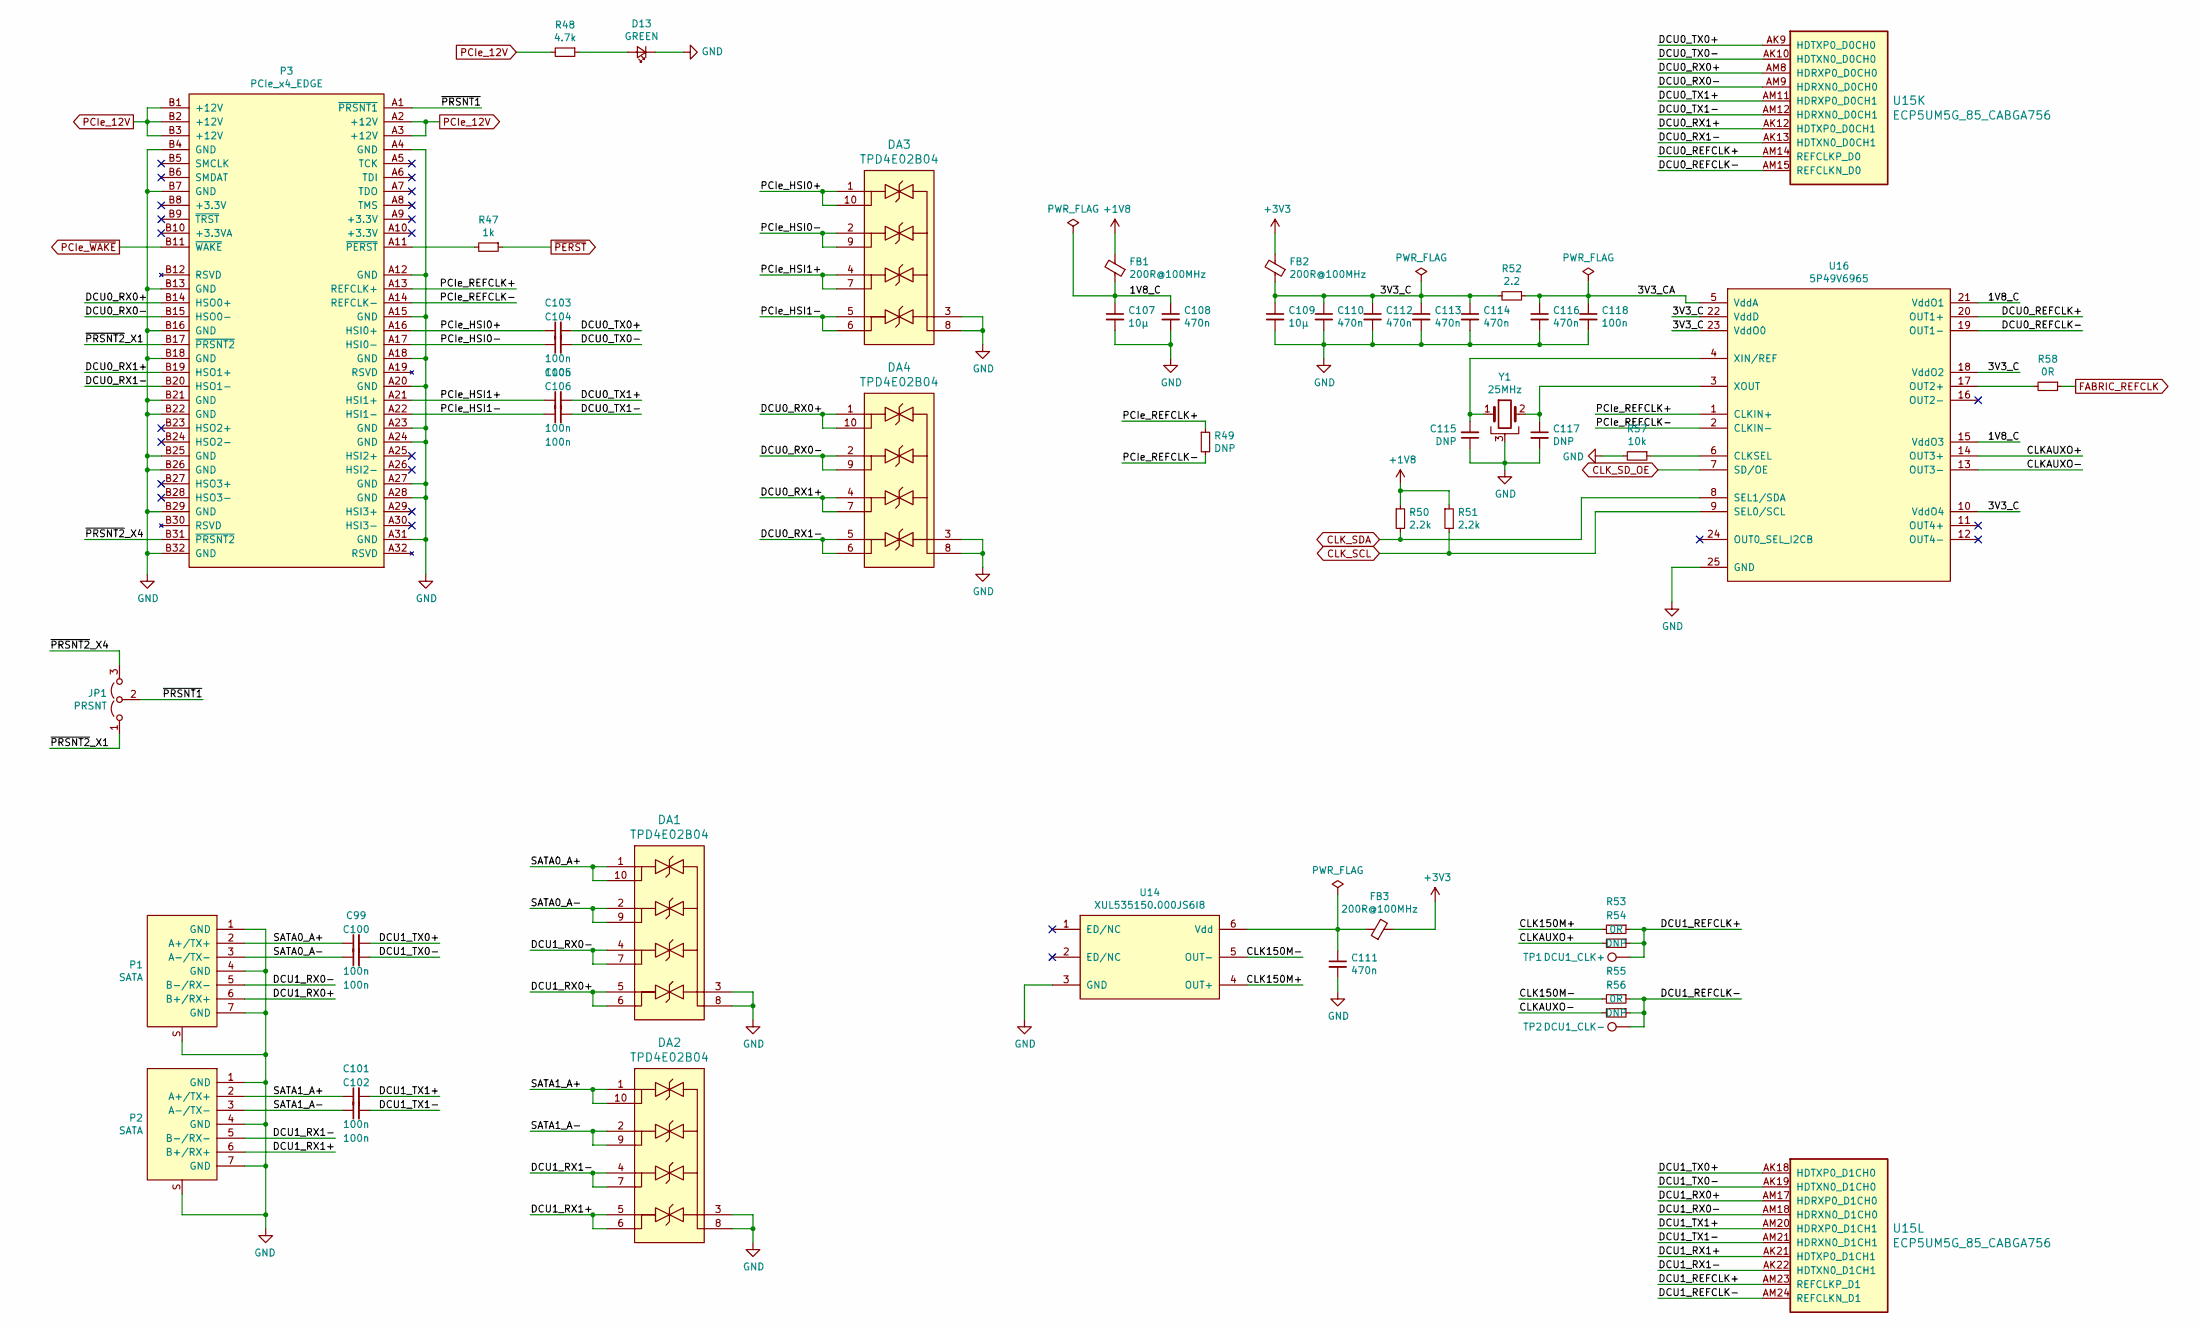
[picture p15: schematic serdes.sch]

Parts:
C99, C100, C101, C102, C103, C104, C105, C106, C118: 100n; C_0402_1005Metric
C107, C109: 10µ; C_0805_2012Metric
C108, C110, C111, C112, C113, C114, C116: 470n; C_0402_1005Metric
C115, C117: DNP; C_0402_1005Metric
D13: GREEN; LED_0805_2012Metric
DA1, DA2, DA3, DA4: TPD4E02B04; USON10
FB1, FB2, FB3: 200R@100MHz; L_0603_1608Metric
JP1: PRSNT; PinHeader_1x03_P2.54mm_Vertical
P1, P2: SATA; Molex_SATA_047080-4001
P3: PCIe_x4_EDGE; PCIe_EDGE_x4
R47: 1k; R_0402_1005Metric
R48: 4.7k; R_0402_1005Metric
R49: DNP; R_0402_1005Metric
R50, R51: 2.2k; R_0402_1005Metric
R52: 2.2; R_0402_1005Metric
R53, R55: 0R; R_0805_2012Metric
R54, R56: DNP; R_0805_2012Metric
R57: 10k; R_0402_1005Metric
R58: 0R; R_0402_1005Metric
TP1: DCU1_CLK+; TestPoint_Pad_1.5x1.5mm
TP2: DCU1_CLK-; TestPoint_Pad_1.5x1.5mm
U14: XUL535150.000JS6I8; OSC_IDT_XU_5x3.2mm
U15: ECP5UM5G_85_CABGA756; CABGA756_27x27mm_p0.8mm
U16: 5P49V6965; QFN-24-1EP_4x4mm_P0.5mm_EP2.7x2.7mm
Y1: 25MHz; Crystal_Epsom_TSX-3225

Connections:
+1V8: FB1.2, R50.1, R51.1; also elsewhere on the board
+3V3: FB2.2, FB3.2; also elsewhere on the board
/PCIe + SATA/1V8_C: C107.1, C108.1, FB1.1, U16.15 (VddO3), U16.21 (VddO1)
/PCIe + SATA/3V3_C: C109.1, C110.1, C112.1, C113.1, C114.1, FB2.1, R52.2, U16.10 (VddO4), U16.18 (VddO2), U16.22 (VddD), U16.23 (VddO0)
/PCIe + SATA/3V3_CA: C116.1, C118.1, R52.1, U16.5 (VddA)
/PCIe + SATA/CLK150M+: R53.2, U14.4 (OUT+)
/PCIe + SATA/CLK150M-: R55.2, U14.5 (OUT-)
/PCIe + SATA/CLKAUXO+: R54.2, U16.14 (OUT3+)
/PCIe + SATA/CLKAUXO-: R56.2, U16.13 (OUT3-)
/PCIe + SATA/DCU0_REFCLK+: U15.AM14 (REFCLKP_D0), U16.20 (OUT1+)
/PCIe + SATA/DCU0_REFCLK-: U15.AM15 (REFCLKN_D0), U16.19 (OUT1-)
/PCIe + SATA/DCU0_RX0+: DA4.1 (IO1), DA4.10, P3.B14 (HSO0+), U15.AM8 (HDRXP0_D0CH0)
/PCIe + SATA/DCU0_RX0-: DA4.2 (IO2), DA4.9, P3.B15 (HSO0-), U15.AM9 (HDRXN0_D0CH0)
/PCIe + SATA/DCU0_RX1+: DA4.4 (IO3), DA4.7, P3.B19 (HSO1+), U15.AK12 (HDTXP0_D0CH1)
/PCIe + SATA/DCU0_RX1-: DA4.5 (IO4), DA4.6, P3.B20 (HSO1-), U15.AK13 (HDTXN0_D0CH1)
/PCIe + SATA/DCU0_TX0+: C103.2, U15.AK9 (HDTXP0_D0CH0)
/PCIe + SATA/DCU0_TX0-: C104.2, U15.AK10 (HDTXN0_D0CH0)
/PCIe + SATA/DCU0_TX1+: C105.2, U15.AM11 (HDRXP0_D0CH1)
/PCIe + SATA/DCU0_TX1-: C106.2, U15.AM12 (HDRXN0_D0CH1)
/PCIe + SATA/DCU1_REFCLK+: R53.1, R54.1, TP1.1, U15.AM23 (REFCLKP_D1)
/PCIe + SATA/DCU1_REFCLK-: R55.1, R56.1, TP2.1, U15.AM24 (REFCLKN_D1)
/PCIe + SATA/DCU1_RX0+: DA1.5 (IO4), DA1.6, P1.6 (B+/RX+), U15.AM17 (HDRXP0_D1CH0)
/PCIe + SATA/DCU1_RX0-: DA1.4 (IO3), DA1.7, P1.5 (B-/RX-), U15.AM18 (HDRXN0_D1CH0)
/PCIe + SATA/DCU1_RX1+: DA2.5 (IO4), DA2.6, P2.6 (B+/RX+), U15.AK21 (HDTXP0_D1CH1)
/PCIe + SATA/DCU1_RX1-: DA2.4 (IO3), DA2.7, P2.5 (B-/RX-), U15.AK22 (HDTXN0_D1CH1)
/PCIe + SATA/DCU1_TX0+: C99.2, U15.AK18 (HDTXP0_D1CH0)
/PCIe + SATA/DCU1_TX0-: C100.2, U15.AK19 (HDTXN0_D1CH0)
/PCIe + SATA/DCU1_TX1+: C101.2, U15.AM20 (HDRXP0_D1CH1)
/PCIe + SATA/DCU1_TX1-: C102.2, U15.AM21 (HDRXN0_D1CH1)
/PCIe + SATA/PCIe_HSI0+: C103.1, DA3.1 (IO1), DA3.10, P3.A16 (HSI0+)
/PCIe + SATA/PCIe_HSI0-: C104.1, DA3.2 (IO2), DA3.9, P3.A17 (HSI0-)
/PCIe + SATA/PCIe_HSI1+: C105.1, DA3.4 (IO3), DA3.7, P3.A21 (HSI1+)
/PCIe + SATA/PCIe_HSI1-: C106.1, DA3.5 (IO4), DA3.6, P3.A22 (HSI1-)
/PCIe + SATA/PCIe_REFCLK+: P3.A13 (REFCLK+), R49.1, U16.1 (CLKIN+)
/PCIe + SATA/PCIe_REFCLK-: P3.A14 (REFCLK-), R49.2, U16.2 (CLKIN-)
/PCIe + SATA/SATA0_A+: C99.1, DA1.1 (IO1), DA1.10, P1.2 (A+/TX+)
/PCIe + SATA/SATA0_A-: C100.1, DA1.2 (IO2), DA1.9, P1.3 (A-/TX-)
/PCIe + SATA/SATA1_A+: C101.1, DA2.1 (IO1), DA2.10, P2.2 (A+/TX+)
/PCIe + SATA/SATA1_A-: C102.1, DA2.2 (IO2), DA2.9, P2.3 (A-/TX-)
/PCIe + SATA/~PRSNT1: JP1.2 (C), P3.A1 (~PRSNT1)
/PCIe + SATA/~PRSNT2~_X1: JP1.1 (A), P3.B17 (~PRSNT2)
/PCIe + SATA/~PRSNT2~_X4: JP1.3 (B), P3.B31 (~PRSNT2)
CLK_SCL: R51.2, U16.9 (SEL0/SCL); also elsewhere on the board
CLK_SDA: R50.2, U16.8 (SEL1/SDA); also elsewhere on the board
CLK_SD_OE: U16.7 (SD/OE); also elsewhere on the board
FABRIC_REFCLK: R58.1; also elsewhere on the board
GND: C107.2, C108.2, C109.2, C110.2, C111.2, C112.2, C113.2, C114.2, C115.1, C116.2, C117.2, C118.2, D13.1 (K), DA1.3 (GND), DA1.8, DA2.3 (GND), DA2.8, DA3.3 (GND), DA3.8, DA4.3 (GND), DA4.8, P1.1 (GND), P1.4 (GND), P1.7 (GND), P1.S, P2.1 (GND), P2.4 (GND), P2.7 (GND), P2.S, P3.A4 (GND), P3.A12 (GND), P3.A15 (GND), P3.A18 (GND), P3.A20 (GND), P3.A23 (GND), P3.A24 (GND), P3.A27 (GND), P3.A28 (GND), P3.A31 (GND), P3.B4 (GND), P3.B7 (GND), P3.B13 (GND), P3.B16 (GND), P3.B18 (GND), P3.B21 (GND), P3.B22 (GND), P3.B25 (GND), P3.B26 (GND), P3.B29 (GND), P3.B32 (GND), R57.2, U14.3 (GND), U16.25 (GND), Y1.3; also elsewhere on the board
unnamed: C111.1, FB3.1, U14.6 (Vdd)
unnamed: C115.2, U16.4 (XIN/REF), Y1.1
unnamed: C117.1, U16.3 (XOUT), Y1.2
unnamed: D13.2 (A), R48.1
unnamed: P3.A11 (~PERST), R47.2
unnamed: R57.1, U16.6 (CLKSEL)
unnamed: R58.2, U16.17 (OUT2+)
PCIe_12V: P3.A2 (+12V), P3.A3 (+12V), P3.B1 (+12V), P3.B2 (+12V), P3.B3 (+12V), R48.2; also elsewhere on the board
PCIe_~WAKE: P3.B11 (~WAKE); also elsewhere on the board
~PERST: R47.1; also elsewhere on the board

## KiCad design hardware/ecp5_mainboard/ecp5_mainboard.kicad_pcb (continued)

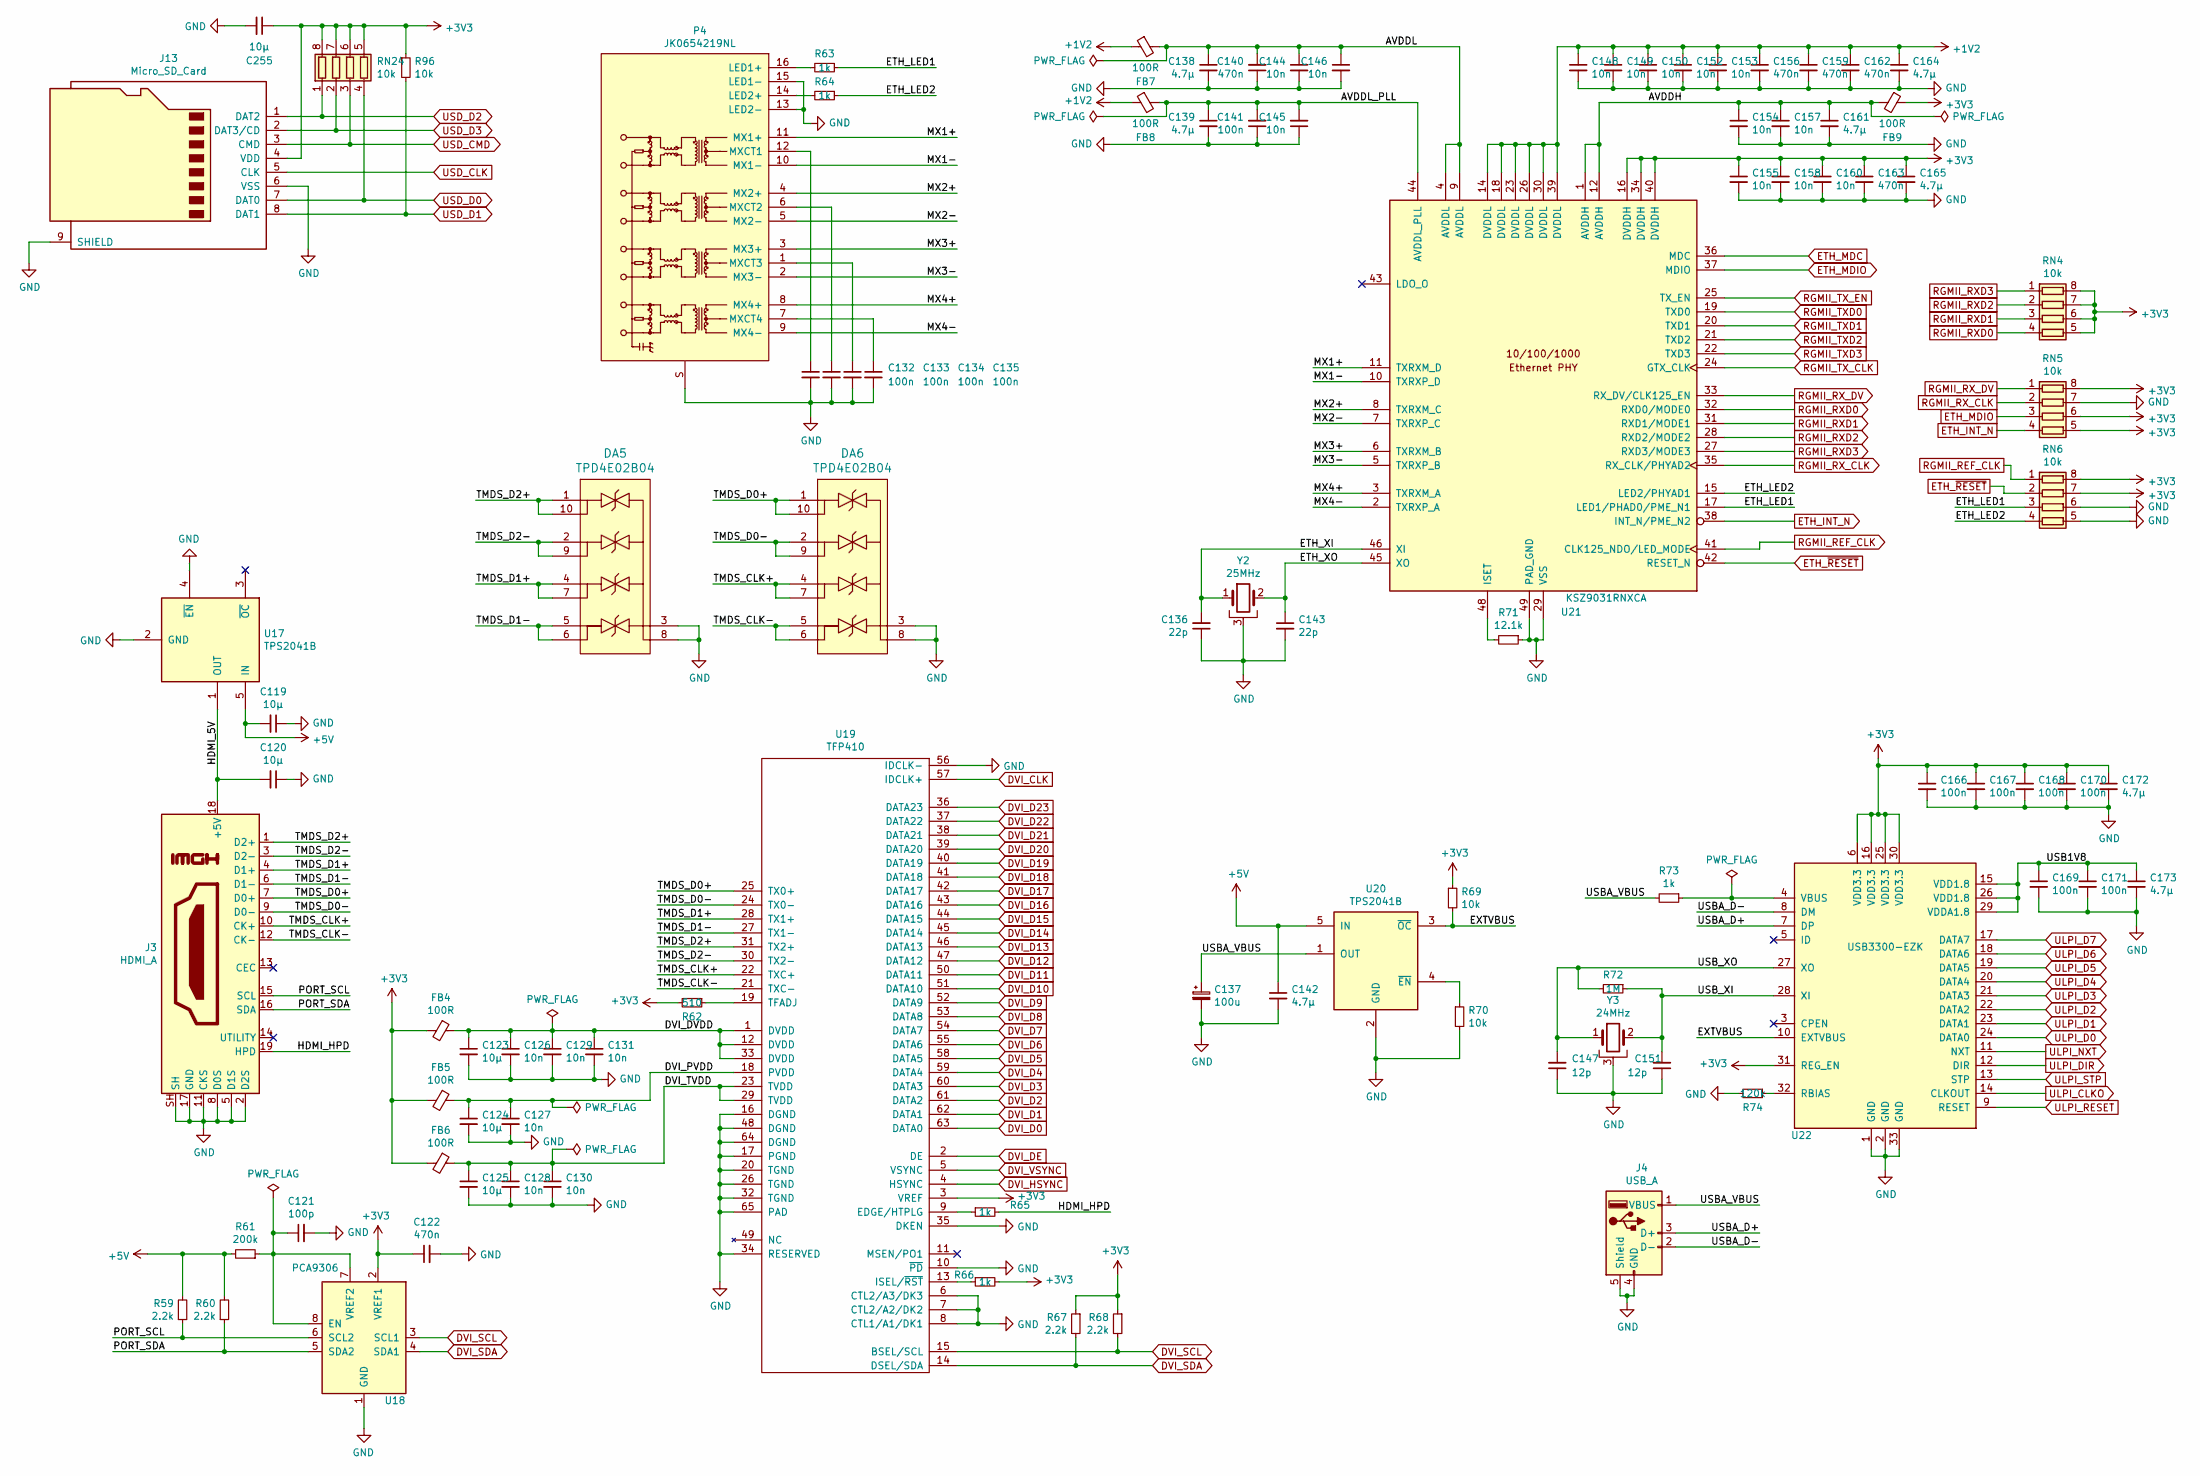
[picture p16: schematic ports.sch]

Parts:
C119, C120, C123, C124, C125, C255: 10µ; C_0805_2012Metric
C121: 100p; C_0402_1005Metric
C122, C140, C156, C159, C162, C163: 470n; C_0402_1005Metric
C126, C127, C128, C129, C130, C131: 10n; C_0402_1005Metric
C132, C133, C134, C135, C141, C166, C167, C168, C169, C170, C171: 100n; C_0402_1005Metric
C136, C143: 22p; C_0402_1005Metric
C137: 100u; CP_Elec_6.3x5.8
C138, C139, C142, C161, C164, C165, C172, C173: 4.7µ; C_0603_1608Metric
C144, C145, C146, C148, C149, C150, C152, C153, C154, C155, C157, C158, C160: 10n; C_0201_0603Metric
C147, C151: 12p; C_0402_1005Metric
DA5, DA6: TPD4E02B04; USON10
FB4, FB5, FB6, FB7, FB8, FB9: 100R; L_0603_1608Metric
J3: HDMI_A; Molex_HDMI_A_47151-0001
J4: USB_A; 292303-7
J13: Micro_SD_Card; microSD_HC_Hirose_DM3AT-SF-PEJM5
P4: JK0654219NL; Pulse_MagJack_JK0654219NL
R59, R60, R67, R68: 2.2k; R_0402_1005Metric
R61: 200k; R_0402_1005Metric
R62: 510; R_0402_1005Metric
R63, R64, R65, R66, R73: 1k; R_0402_1005Metric
R69, R70, R96: 10k; R_0402_1005Metric
R71: 12.1k; R_0402_1005Metric
R72: 1M; R_0402_1005Metric
R74: 120k; R_0402_1005Metric
RN4, RN5, RN6, RN24: 10k; R_Array_Convex_4x0402
U17, U20: TPS2041B; SOT-23-5
U18: PCA9306; VSSOP-8_2.3x2mm_P0.5mm
U19: TFP410; HTQFP-64-1EP_10x10mm_P0.5mm_EP8x8mm_Mask4.4x4.4mm_ThermalVi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
U21: KSZ9031RNXCA; QFN-48-1EP_7x7mm_P0.5mm_EP5.15x5.15mm
U22: USB3300-EZK; QFN-32-1EP_5x5mm_P0.5mm_EP3.45x3.45mm
Y2: 25MHz; Crystal_Epsom_TSX-3225
Y3: 24MHz; Crystal_Epsom_TSX-3225

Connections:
+1V2: C148.1, C149.1, C150.1, C152.1, C153.1, C156.1, C159.1, C162.1, C164.1, FB7.1, FB8.1, U21.14 (DVDDL), U21.18 (DVDDL), U21.23 (DVDDL), U21.26 (DVDDL), U21.30 (DVDDL), U21.39 (DVDDL); also elsewhere on the board
+3V3: C122.1, C155.1, C158.1, C160.1, C163.1, C165.1, C166.1, C167.1, C168.1, C170.1, C172.1, C255.1, FB4.2, FB5.2, FB6.2, FB9.1, J13.4 (VDD), R62.2, R66.2, R67.1, R68.1, R69.1, R96.1, RN4.5 (R4.2), RN4.6 (R3.2), RN4.7 (R2.2), RN4.8 (R1.2), RN5.5 (R4.2), RN5.6 (R3.2), RN5.8 (R1.2), RN6.7 (R2.2), RN6.8 (R1.2), RN24.5 (R4.2), RN24.6 (R3.2), RN24.7 (R2.2), RN24.8 (R1.2), U18.2 (VREF1), U19.3 (VREF), U21.16 (DVDDH), U21.34 (DVDDH), U21.40 (DVDDH), U22.6 (VDD3.3), U22.16 (VDD3.3), U22.25 (VDD3.3), U22.30 (VDD3.3), U22.31 (REG_EN); also elsewhere on the board
+5V: C119.2, C142.1, R59.2, R60.2, R61.2, U17.5 (IN), U20.5 (IN); also elsewhere on the board
/HDMI, GbE, USB/AVDDH: C154.1, C157.1, C161.1, FB9.2, U21.1 (AVDDH), U21.12 (AVDDH)
/HDMI, GbE, USB/AVDDL: C138.1, C140.2, C144.1, C146.1, FB7.2, U21.4 (AVDDL), U21.9 (AVDDL)
/HDMI, GbE, USB/AVDDL_PLL: C139.1, C141.2, C145.2, FB8.2, U21.44 (AVDDL_PLL)
/HDMI, GbE, USB/DVI_DVDD: C123.1, C126.1, C129.1, C131.1, FB4.1, U19.1 (DVDD), U19.12 (DVDD), U19.33 (DVDD)
/HDMI, GbE, USB/DVI_PVDD: C124.1, C127.1, FB5.1, U19.18 (PVDD)
/HDMI, GbE, USB/DVI_TVDD: C125.1, C128.1, C130.1, FB6.1, U19.23 (TVDD), U19.29 (TVDD)
/HDMI, GbE, USB/ETH_LED1: R63.1, RN6.3 (R3.1), U21.17 (LED1/PHAD0/PME_N1)
/HDMI, GbE, USB/ETH_LED2: R64.1, RN6.4 (R4.1), U21.15 (LED2/PHYAD1)
/HDMI, GbE, USB/ETH_XI: C136.2, U21.46 (XI), Y2.1
/HDMI, GbE, USB/ETH_XO: C143.1, U21.45 (XO), Y2.2
/HDMI, GbE, USB/EXTVBUS: R69.2, U20.3 (~OC), U22.10 (EXTVBUS)
/HDMI, GbE, USB/HDMI_5V: C120.2, J3.18 (+5V), U17.1 (OUT)
/HDMI, GbE, USB/HDMI_HPD: J3.19 (HPD), R65.2
/HDMI, GbE, USB/MX1+: P4.11 (MX1+), U21.11 (TXRXM_D)
/HDMI, GbE, USB/MX1-: P4.10 (MX1-), U21.10 (TXRXP_D)
/HDMI, GbE, USB/MX2+: P4.4 (MX2+), U21.8 (TXRXM_C)
/HDMI, GbE, USB/MX2-: P4.5 (MX2-), U21.7 (TXRXP_C)
/HDMI, GbE, USB/MX3+: P4.3 (MX3+), U21.6 (TXRXM_B)
/HDMI, GbE, USB/MX3-: P4.2 (MX3-), U21.5 (TXRXP_B)
/HDMI, GbE, USB/MX4+: P4.8 (MX4+), U21.3 (TXRXM_A)
/HDMI, GbE, USB/MX4-: P4.9 (MX4-), U21.2 (TXRXP_A)
/HDMI, GbE, USB/PORT_SCL: J3.15 (SCL), R59.1, U18.6 (SCL2)
/HDMI, GbE, USB/PORT_SDA: J3.16 (SDA), R60.1, U18.5 (SDA2)
/HDMI, GbE, USB/TMDS_CLK+: DA6.4 (IO3), DA6.7, J3.10 (CK+), U19.22 (TXC+)
/HDMI, GbE, USB/TMDS_CLK-: DA6.5 (IO4), DA6.6, J3.12 (CK-), U19.21 (TXC-)
/HDMI, GbE, USB/TMDS_D0+: DA6.1 (IO1), DA6.10, J3.7 (D0+), U19.25 (TX0+)
/HDMI, GbE, USB/TMDS_D0-: DA6.2 (IO2), DA6.9, J3.9 (D0-), U19.24 (TX0-)
/HDMI, GbE, USB/TMDS_D1+: DA5.4 (IO3), DA5.7, J3.4 (D1+), U19.28 (TX1+)
/HDMI, GbE, USB/TMDS_D1-: DA5.5 (IO4), DA5.6, J3.6 (D1-), U19.27 (TX1-)
/HDMI, GbE, USB/TMDS_D2+: DA5.1 (IO1), DA5.10, J3.1 (D2+), U19.31 (TX2+)
/HDMI, GbE, USB/TMDS_D2-: DA5.2 (IO2), DA5.9, J3.3 (D2-), U19.30 (TX2-)
/HDMI, GbE, USB/USB1V8: C169.1, C171.1, C173.1, U22.15 (VDD1.8), U22.26 (VDD1.8), U22.29 (VDDA1.8)
/HDMI, GbE, USB/USBA_D+: J4.3 (D+), U22.7 (DP)
/HDMI, GbE, USB/USBA_D-: J4.2 (D-), U22.8 (DM)
/HDMI, GbE, USB/USBA_VBUS: C137.1, J4.1 (VBUS), R73.2, U20.1 (OUT)
/HDMI, GbE, USB/USB_XI: C151.2, R72.1, U22.28 (XI), Y3.2
/HDMI, GbE, USB/USB_XO: C147.2, R72.2, U22.27 (XO), Y3.1
DVI_CLK: U19.57 (IDCLK+); also elsewhere on the board
DVI_D0: U19.63 (DATA0); also elsewhere on the board
DVI_D1: U19.62 (DATA1); also elsewhere on the board
DVI_D2: U19.61 (DATA2); also elsewhere on the board
DVI_D3: U19.60 (DATA3); also elsewhere on the board
DVI_D4: U19.59 (DATA4); also elsewhere on the board
DVI_D5: U19.58 (DATA5); also elsewhere on the board
DVI_D6: U19.55 (DATA6); also elsewhere on the board
DVI_D7: U19.54 (DATA7); also elsewhere on the board
DVI_D8: U19.53 (DATA8); also elsewhere on the board
DVI_D9: U19.52 (DATA9); also elsewhere on the board
DVI_D10: U19.51 (DATA10); also elsewhere on the board
DVI_D11: U19.50 (DATA11); also elsewhere on the board
DVI_D12: U19.47 (DATA12); also elsewhere on the board
DVI_D13: U19.46 (DATA13); also elsewhere on the board
DVI_D14: U19.45 (DATA14); also elsewhere on the board
DVI_D15: U19.44 (DATA15); also elsewhere on the board
DVI_D16: U19.43 (DATA16); also elsewhere on the board
DVI_D17: U19.42 (DATA17); also elsewhere on the board
DVI_D18: U19.41 (DATA18); also elsewhere on the board
DVI_D19: U19.40 (DATA19); also elsewhere on the board
DVI_D20: U19.39 (DATA20); also elsewhere on the board
DVI_D21: U19.38 (DATA21); also elsewhere on the board
DVI_D22: U19.37 (DATA22); also elsewhere on the board
DVI_D23: U19.36 (DATA23); also elsewhere on the board
DVI_DE: U19.2 (DE); also elsewhere on the board
DVI_HSYNC: U19.4 (HSYNC); also elsewhere on the board
DVI_SCL: R68.2, U18.3 (SCL1), U19.15 (BSEL/SCL); also elsewhere on the board
DVI_SDA: R67.2, U18.4 (SDA1), U19.14 (DSEL/SDA); also elsewhere on the board
DVI_VSYNC: U19.5 (VSYNC); also elsewhere on the board
ETH_INT_N: RN5.4 (R4.1), U21.38 (INT_N/PME_N2); also elsewhere on the board
ETH_MDC: U21.36 (MDC); also elsewhere on the board
ETH_MDIO: RN5.3 (R3.1), U21.37 (MDIO); also elsewhere on the board
ETH_~RESET: RN6.2 (R2.1), U21.42 (RESET_N); also elsewhere on the board
GND: C119.1, C120.1, C121.2, C122.2, C123.2, C124.2, C125.2, C126.2, C127.2, C128.2, C129.2, C130.2, C131.2, C132.2, C133.2, C134.2, C135.2, C136.1, C137.2, C138.2, C139.2, C140.1, C141.1, C142.2, C143.2, C144.2, C145.1, C146.2, C147.1, C148.2, C149.2, C150.2, C151.1, C152.2, C153.2, C154.2, C155.2, C156.2, C157.2, C158.2, C159.2, C160.2, C161.2, C162.2, C163.2, C164.2, C165.2, C166.2, C167.2, C168.2, C169.2, C170.2, C171.2, C172.2, C173.2, C255.2, DA5.3 (GND), DA5.8, DA6.3 (GND), DA6.8, J3.2 (D2S), J3.5 (D1S), J3.8 (D0S), J3.11 (CKS), J3.17 (GND), J3.SH, J4.4 (GND), J4.5 (Shield), J13.6 (VSS), J13.9 (SHIELD), P4.13 (LED2-), P4.15 (LED1-), P4.S, R70.2, R71.1, R74.2, RN5.7 (R2.2), RN6.5 (R4.2), RN6.6 (R3.2), U17.2 (GND), U17.4 (~EN), U18.1 (GND), U19.6 (CTL2/A3/DK3), U19.7 (CTL2/A2/DK2), U19.8 (CTL1/A1/DK1), U19.10 (~PD), U19.16 (DGND), U19.17 (PGND), U19.20 (TGND), U19.26 (TGND), U19.32 (TGND), U19.34 (RESERVED), U19.35 (DKEN), U19.48 (DGND), U19.56 (IDCLK-), U19.64 (DGND), U19.65 (PAD), U20.2 (GND), U21.29 (VSS), U21.49 (PAD_GND), U22.1 (GND), U22.2 (GND), U22.33 (GND), Y2.3, Y3.3; also elsewhere on the board
unnamed: C121.1, R61.1, U18.7 (VREF2), U18.8 (EN)
unnamed: C132.1, P4.12 (MXCT1)
unnamed: C133.1, P4.6 (MXCT2)
unnamed: C134.1, P4.1 (MXCT3)
unnamed: C135.1, P4.7 (MXCT4)
unnamed: P4.14 (LED2+), R64.2
unnamed: P4.16 (LED1+), R63.2
unnamed: R62.1, U19.19 (TFADJ)
unnamed: R65.1, U19.9 (EDGE/HTPLG)
unnamed: R66.1, U19.13 (ISEL/~RST)
unnamed: R70.1, U20.4 (~EN)
unnamed: R71.2, U21.48 (ISET)
unnamed: R73.1, U22.4 (VBUS)
unnamed: R74.1, U22.32 (RBIAS)
RGMII_REF_CLK: RN6.1 (R1.1), U21.41 (CLK125_NDO/LED_MODE); also elsewhere on the board
RGMII_RXD0: RN4.4 (R4.1), U21.32 (RXD0/MODE0); also elsewhere on the board
RGMII_RXD1: RN4.3 (R3.1), U21.31 (RXD1/MODE1); also elsewhere on the board
RGMII_RXD2: RN4.2 (R2.1), U21.28 (RXD2/MODE2); also elsewhere on the board
RGMII_RXD3: RN4.1 (R1.1), U21.27 (RXD3/MODE3); also elsewhere on the board
RGMII_RX_CLK: RN5.2 (R2.1), U21.35 (RX_CLK/PHYAD2); also elsewhere on the board
RGMII_RX_DV: RN5.1 (R1.1), U21.33 (RX_DV/CLK125_EN); also elsewhere on the board
RGMII_TXD0: U21.19 (TXD0); also elsewhere on the board
RGMII_TXD1: U21.20 (TXD1); also elsewhere on the board
RGMII_TXD2: U21.21 (TXD2); also elsewhere on the board
RGMII_TXD3: U21.22 (TXD3); also elsewhere on the board
RGMII_TX_CLK: U21.24 (GTX_CLK); also elsewhere on the board
RGMII_TX_EN: U21.25 (TX_EN); also elsewhere on the board
ULPI_CLKO: U22.14 (CLKOUT); also elsewhere on the board
ULPI_D0: U22.24 (DATA0); also elsewhere on the board
ULPI_D1: U22.23 (DATA1); also elsewhere on the board
ULPI_D2: U22.22 (DATA2); also elsewhere on the board
ULPI_D3: U22.21 (DATA3); also elsewhere on the board
ULPI_D4: U22.20 (DATA4); also elsewhere on the board
ULPI_D5: U22.19 (DATA5); also elsewhere on the board
ULPI_D6: U22.18 (DATA6); also elsewhere on the board
ULPI_D7: U22.17 (DATA7); also elsewhere on the board
ULPI_DIR: U22.12 (DIR); also elsewhere on the board
ULPI_NXT: U22.11 (NXT); also elsewhere on the board
ULPI_RESET: U22.9 (RESET); also elsewhere on the board
ULPI_STP: U22.13 (STP); also elsewhere on the board
USD_CLK: J13.5 (CLK); also elsewhere on the board
USD_CMD: J13.3 (CMD), RN24.3 (R3.1); also elsewhere on the board
USD_D0: J13.7 (DAT0), RN24.4 (R4.1); also elsewhere on the board
USD_D1: J13.8 (DAT1), R96.2; also elsewhere on the board
USD_D2: J13.1 (DAT2), RN24.1 (R1.1); also elsewhere on the board
USD_D3: J13.2 (DAT3/CD), RN24.2 (R2.1); also elsewhere on the board

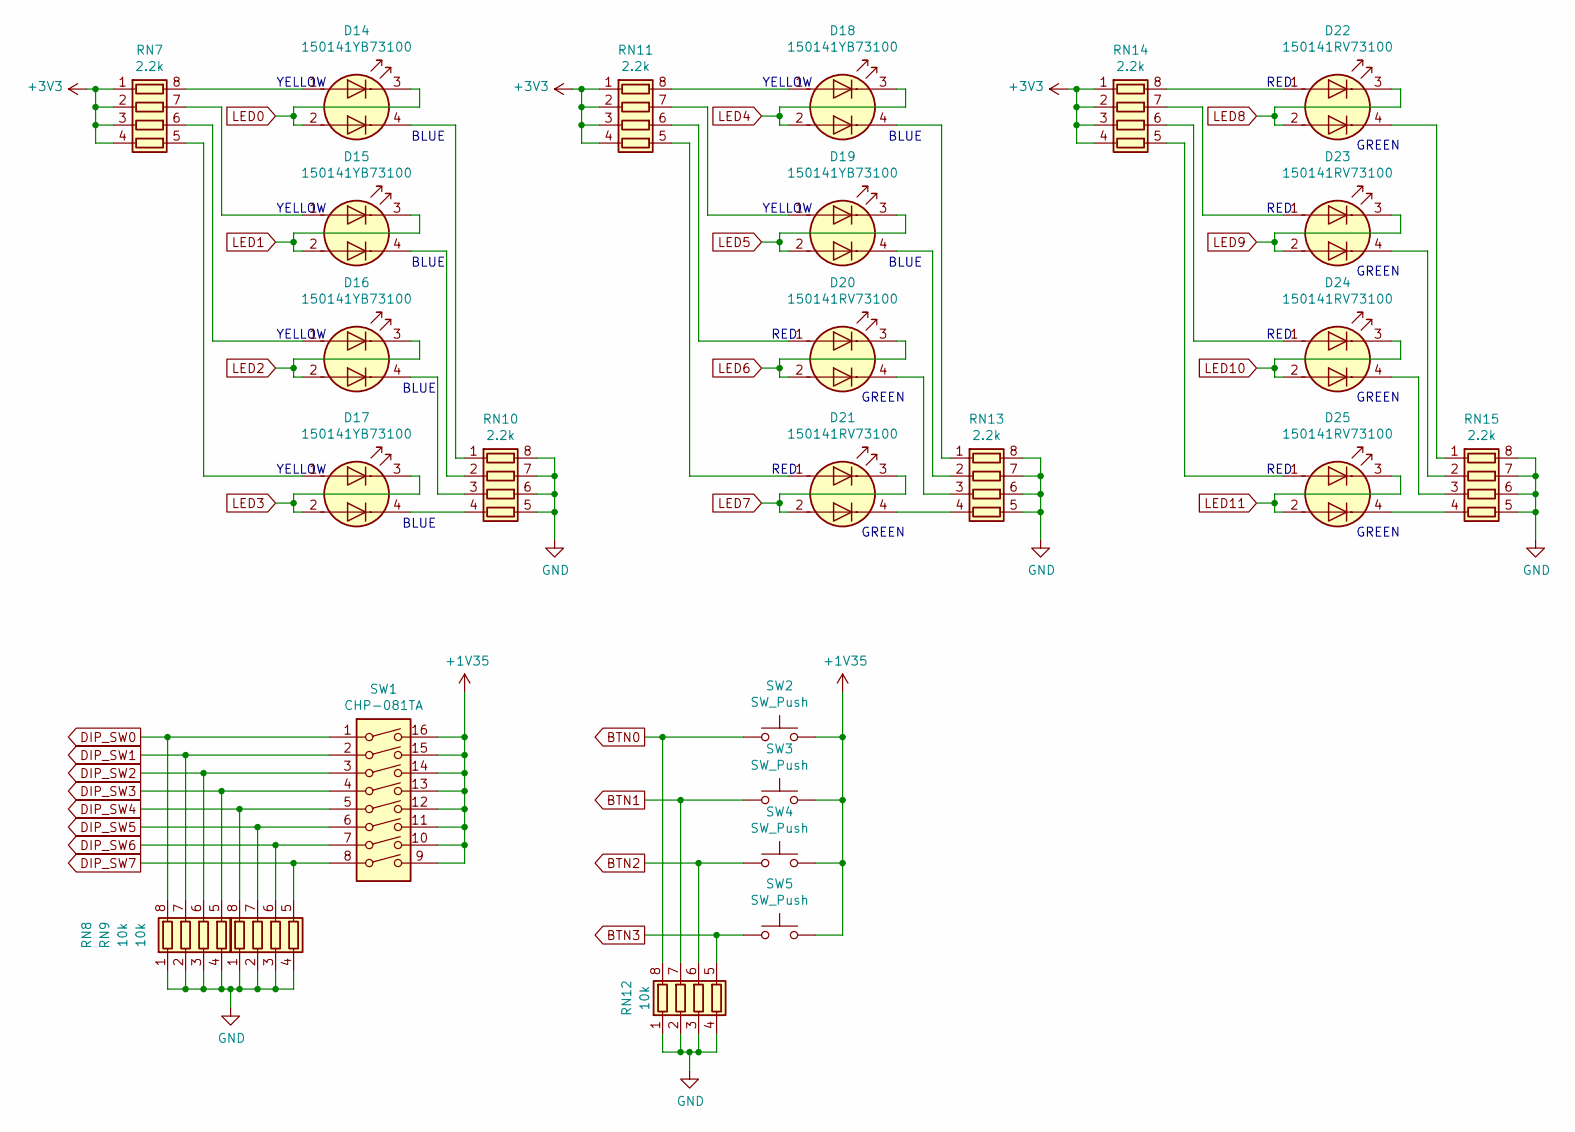
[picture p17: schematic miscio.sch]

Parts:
D14, D15, D16, D17, D18, D19: 150141YB73100; Wurth_BiLED_150141_3528
D20, D21, D22, D23, D24, D25: 150141RV73100; Wurth_BiLED_150141_3528
RN7, RN10, RN11, RN13, RN14, RN15: 2.2k; R_Array_Convex_4x0402
RN8, RN9, RN12: 10k; R_Array_Convex_4x0402
SW1: CHP-081TA; DipSW_CHP-081TA
SW2, SW3, SW4, SW5: SW_Push; SW_SPST_B3S-1000

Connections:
+1V35: SW1.9, SW1.10, SW1.11, SW1.12, SW1.13, SW1.14, SW1.15, SW1.16, SW2.2, SW3.2, SW4.2, SW5.2; also elsewhere on the board
+3V3: RN7.1 (R1.1), RN7.2 (R2.1), RN7.3 (R3.1), RN7.4 (R4.1), RN11.1 (R1.1), RN11.2 (R2.1), RN11.3 (R3.1), RN11.4 (R4.1), RN14.1 (R1.1), RN14.2 (R2.1), RN14.3 (R3.1), RN14.4 (R4.1); also elsewhere on the board
BTN0: RN12.8 (R1.2), SW2.1; also elsewhere on the board
BTN1: RN12.7 (R2.2), SW3.1; also elsewhere on the board
BTN2: RN12.6 (R3.2), SW4.1; also elsewhere on the board
BTN3: RN12.5 (R4.2), SW5.1; also elsewhere on the board
DIP_SW0: RN8.8 (R1.2), SW1.1; also elsewhere on the board
DIP_SW1: RN8.7 (R2.2), SW1.2; also elsewhere on the board
DIP_SW2: RN8.6 (R3.2), SW1.3; also elsewhere on the board
DIP_SW3: RN8.5 (R4.2), SW1.4; also elsewhere on the board
DIP_SW4: RN9.8 (R1.2), SW1.5; also elsewhere on the board
DIP_SW5: RN9.7 (R2.2), SW1.6; also elsewhere on the board
DIP_SW6: RN9.6 (R3.2), SW1.7; also elsewhere on the board
DIP_SW7: RN9.5 (R4.2), SW1.8; also elsewhere on the board
GND: RN8.1 (R1.1), RN8.2 (R2.1), RN8.3 (R3.1), RN8.4 (R4.1), RN9.1 (R1.1), RN9.2 (R2.1), RN9.3 (R3.1), RN9.4 (R4.1), RN10.5 (R4.2), RN10.6 (R3.2), RN10.7 (R2.2), RN10.8 (R1.2), RN12.1 (R1.1), RN12.2 (R2.1), RN12.3 (R3.1), RN12.4 (R4.1), RN13.5 (R4.2), RN13.6 (R3.2), RN13.7 (R2.2), RN13.8 (R1.2), RN15.5 (R4.2), RN15.6 (R3.2), RN15.7 (R2.2), RN15.8 (R1.2); also elsewhere on the board
LED0: D14.2 (A2), D14.3 (K1); also elsewhere on the board
LED1: D15.2 (A2), D15.3 (K1); also elsewhere on the board
LED2: D16.2 (A2), D16.3 (K1); also elsewhere on the board
LED3: D17.2 (A2), D17.3 (K1); also elsewhere on the board
LED4: D18.2 (A2), D18.3 (K1); also elsewhere on the board
LED5: D19.2 (A2), D19.3 (K1); also elsewhere on the board
LED6: D20.2 (A2), D20.3 (K1); also elsewhere on the board
LED7: D21.2 (A2), D21.3 (K1); also elsewhere on the board
LED8: D22.2 (A2), D22.3 (K1); also elsewhere on the board
LED9: D23.2 (A2), D23.3 (K1); also elsewhere on the board
LED10: D24.2 (A2), D24.3 (K1); also elsewhere on the board
LED11: D25.2 (A2), D25.3 (K1); also elsewhere on the board
unnamed: D14.1 (A1), RN7.8 (R1.2)
unnamed: D14.4 (K2), RN10.1 (R1.1)
unnamed: D15.1 (A1), RN7.7 (R2.2)
unnamed: D15.4 (K2), RN10.2 (R2.1)
unnamed: D16.1 (A1), RN7.6 (R3.2)
unnamed: D16.4 (K2), RN10.3 (R3.1)
unnamed: D17.1 (A1), RN7.5 (R4.2)
unnamed: D17.4 (K2), RN10.4 (R4.1)
unnamed: D18.1 (A1), RN11.8 (R1.2)
unnamed: D18.4 (K2), RN13.1 (R1.1)
unnamed: D19.1 (A1), RN11.7 (R2.2)
unnamed: D19.4 (K2), RN13.2 (R2.1)
unnamed: D20.1 (A1), RN11.6 (R3.2)
unnamed: D20.4 (K2), RN13.3 (R3.1)
unnamed: D21.1 (A1), RN11.5 (R4.2)
unnamed: D21.4 (K2), RN13.4 (R4.1)
unnamed: D22.1 (A1), RN14.8 (R1.2)
unnamed: D22.4 (K2), RN15.1 (R1.1)
unnamed: D23.1 (A1), RN14.7 (R2.2)
unnamed: D23.4 (K2), RN15.2 (R2.1)
unnamed: D24.1 (A1), RN14.6 (R3.2)
unnamed: D24.4 (K2), RN15.3 (R3.1)
unnamed: D25.1 (A1), RN14.5 (R4.2)
unnamed: D25.4 (K2), RN15.4 (R4.1)

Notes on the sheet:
BLUE
YELLOW
RED
GREEN

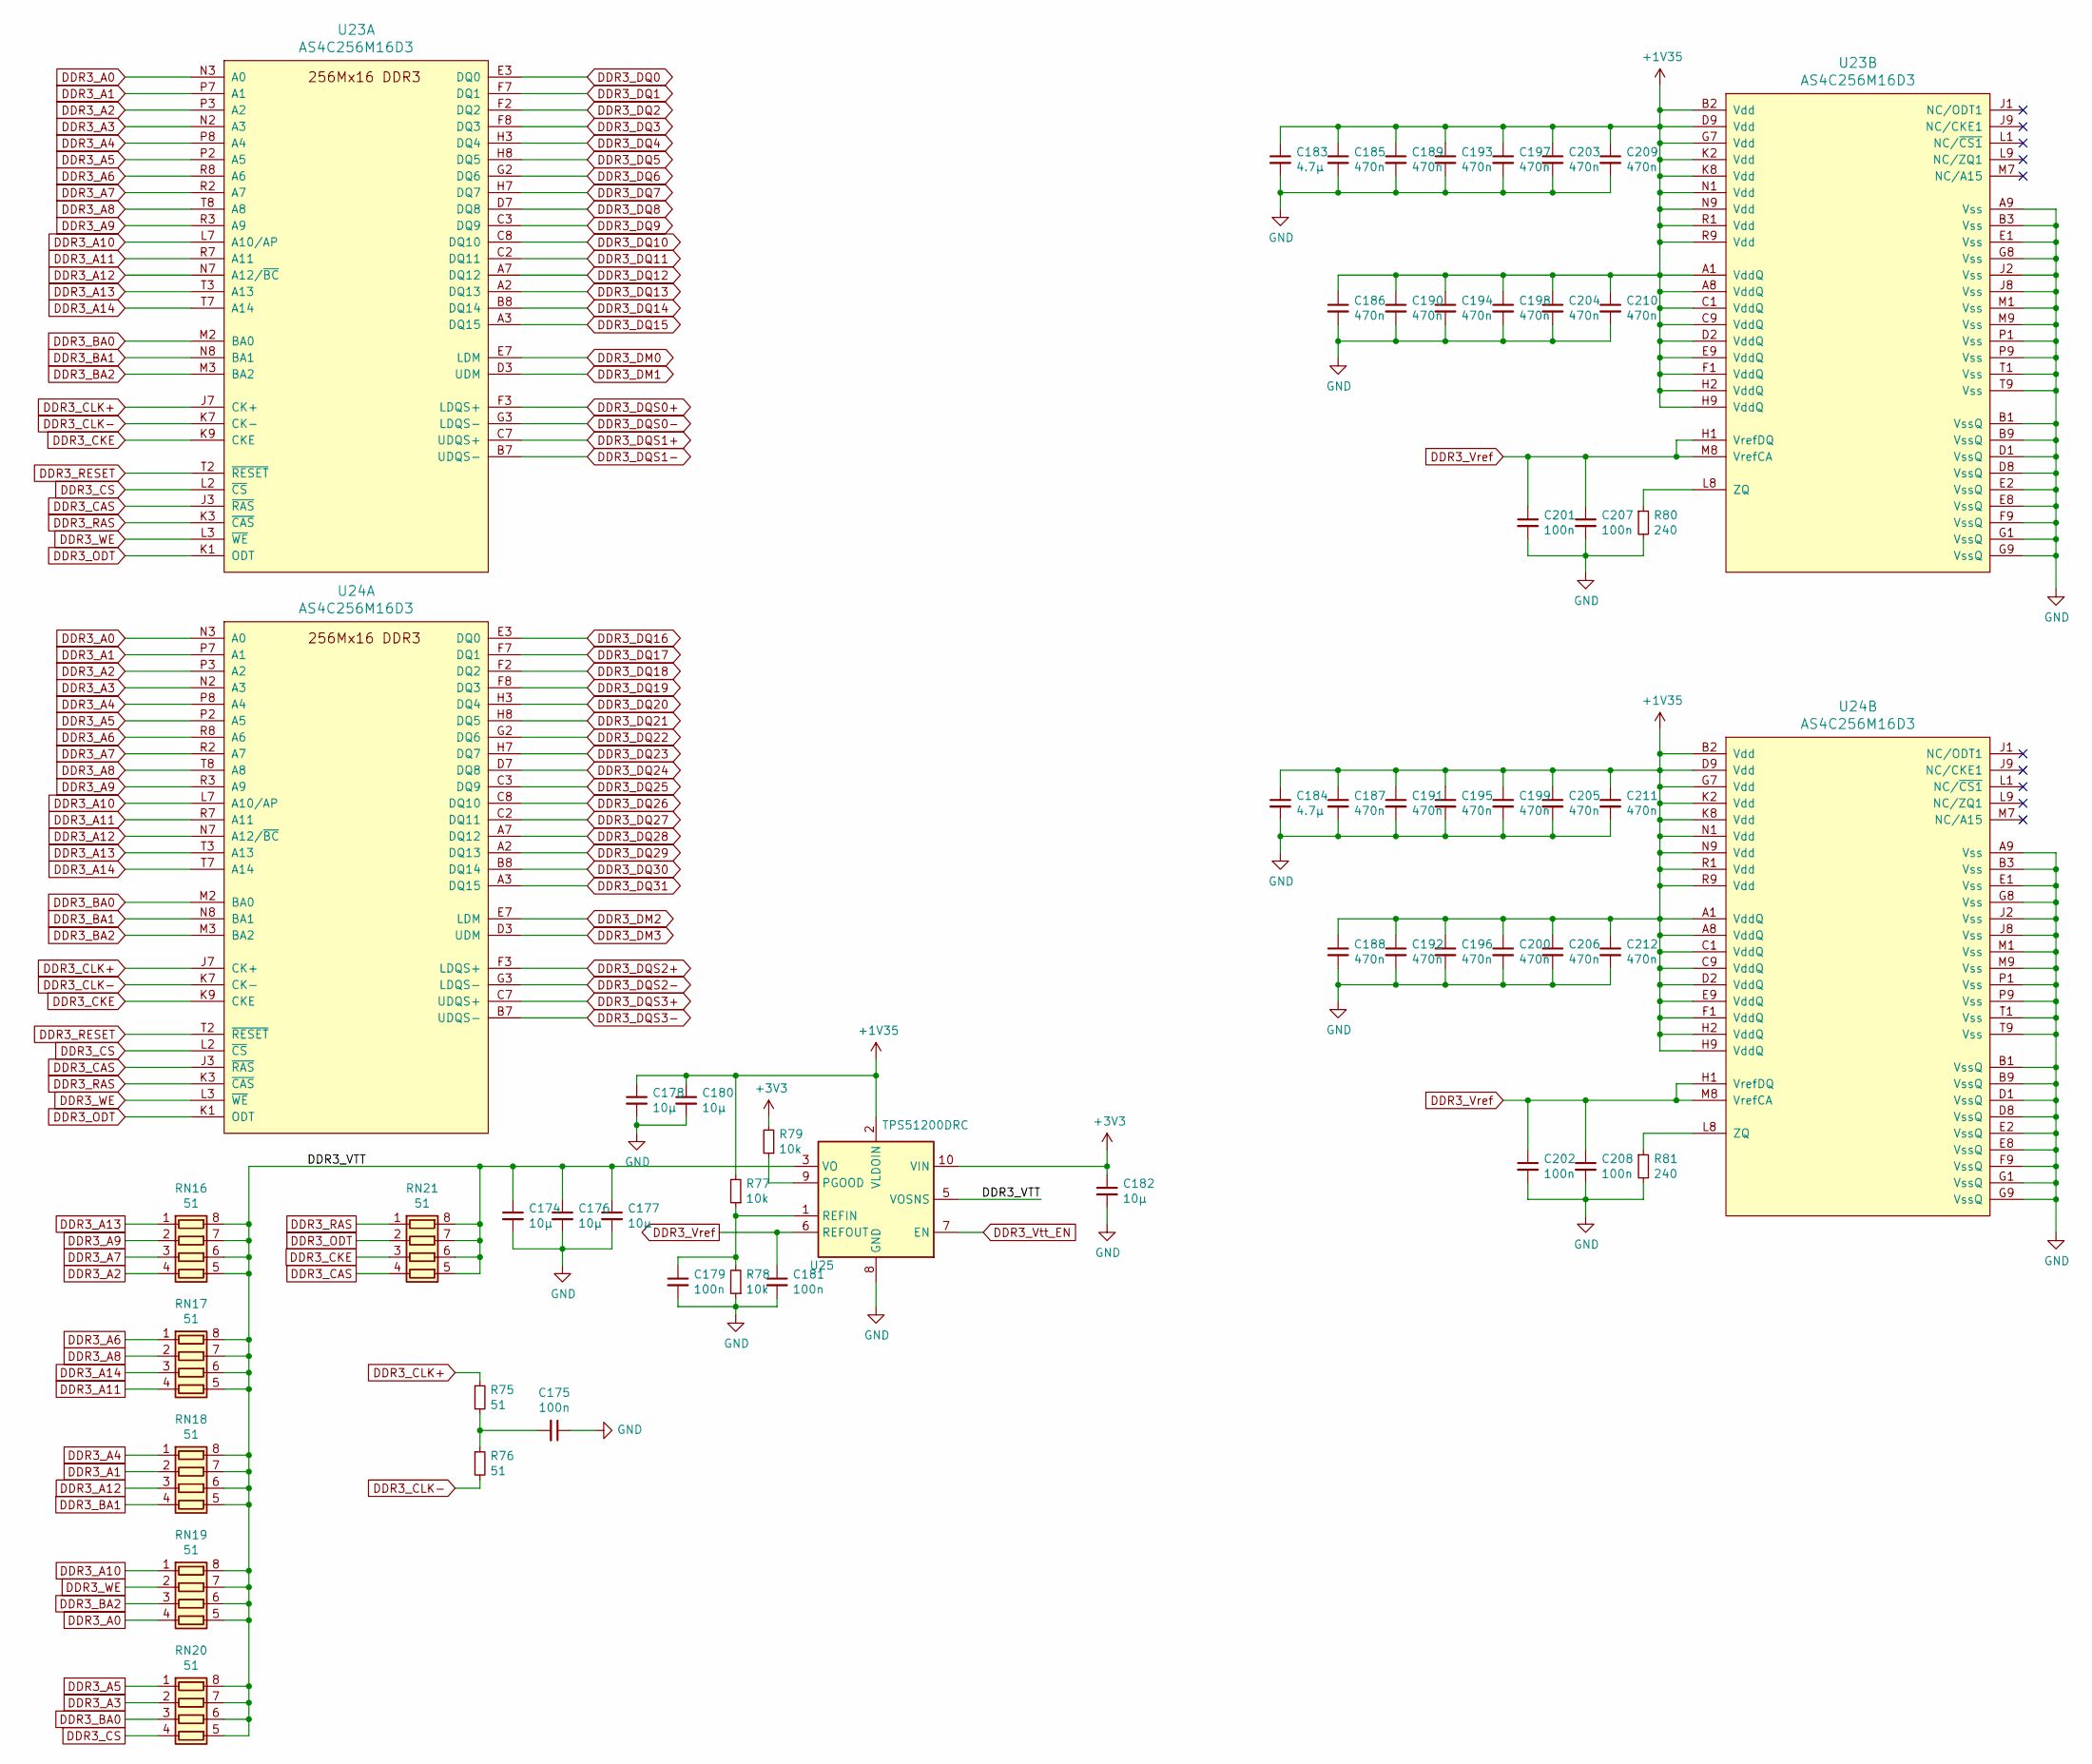
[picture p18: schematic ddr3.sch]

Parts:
C174, C176, C177, C178, C180: 10µ; C_0805_2012Metric
C175, C179, C181, C201, C202, C207, C208: 100n; C_0402_1005Metric
C182: 10µ; C_0603_1608Metric
C183, C184: 4.7µ; C_0603_1608Metric
C185, C186, C187, C188, C189, C190, C191, C192, C193, C194, C195, C196, C197, C198, C199, C200, C203, C204, C205, C206, C209, C210, C211, C212: 470n; C_0402_1005Metric
R75, R76: 51; R_0402_1005Metric
R77, R78, R79: 10k; R_0402_1005Metric
R80, R81: 240; R_0402_1005Metric
RN16, RN17, RN18, RN19, RN20, RN21: 51; R_Array_Convex_4x0402
U23, U24: AS4C256M16D3; BGA-96_9.0x13.0mm_Layout2x3x16_P0.8mm
U25: TPS51200DRC; VSON-10-1EP_3x3mm_P0.5mm_EP1.65x2.4mm

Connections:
+1V35: C178.1, C180.1, C183.1, C184.1, C185.1, C186.1, C187.1, C188.1, C189.1, C190.1, C191.1, C192.1, C193.1, C194.1, C195.1, C196.1, C197.1, C198.1, C199.1, C200.1, C203.1, C204.1, C205.1, C206.1, C209.1, C210.1, C211.1, C212.1, R77.2, U23.A1 (VddQ), U23.A8 (VddQ), U23.B2 (Vdd), U23.C1 (VddQ), U23.C9 (VddQ), U23.D2 (VddQ), U23.D9 (Vdd), U23.E9 (VddQ), U23.F1 (VddQ), U23.G7 (Vdd), U23.H2 (VddQ), U23.H9 (VddQ), U23.K2 (Vdd), U23.K8 (Vdd), U23.N1 (Vdd), U23.N9 (Vdd), U23.R1 (Vdd), U23.R9 (Vdd), U24.A1 (VddQ), U24.A8 (VddQ), U24.B2 (Vdd), U24.C1 (VddQ), U24.C9 (VddQ), U24.D2 (VddQ), U24.D9 (Vdd), U24.E9 (VddQ), U24.F1 (VddQ), U24.G7 (Vdd), U24.H2 (VddQ), U24.H9 (VddQ), U24.K2 (Vdd), U24.K8 (Vdd), U24.N1 (Vdd), U24.N9 (Vdd), U24.R1 (Vdd), U24.R9 (Vdd), U25.2 (VLDOIN); also elsewhere on the board
+3V3: C182.1, R79.2, U25.10 (VIN); also elsewhere on the board
/DDR3/DDR3_VTT: C174.1, C176.1, C177.1, RN16.5 (R4.2), RN16.6 (R3.2), RN16.7 (R2.2), RN16.8 (R1.2), RN17.5 (R4.2), RN17.6 (R3.2), RN17.7 (R2.2), RN17.8 (R1.2), RN18.5 (R4.2), RN18.6 (R3.2), RN18.7 (R2.2), RN18.8 (R1.2), RN19.5 (R4.2), RN19.6 (R3.2), RN19.7 (R2.2), RN19.8 (R1.2), RN20.5 (R4.2), RN20.6 (R3.2), RN20.7 (R2.2), RN20.8 (R1.2), RN21.5 (R4.2), RN21.6 (R3.2), RN21.7 (R2.2), RN21.8 (R1.2), U25.3 (VO), U25.5 (VOSNS)
DDR3_A0: RN19.4 (R4.1), U23.N3 (A0), U24.N3 (A0); also elsewhere on the board
DDR3_A1: RN18.2 (R2.1), U23.P7 (A1), U24.P7 (A1); also elsewhere on the board
DDR3_A2: RN16.4 (R4.1), U23.P3 (A2), U24.P3 (A2); also elsewhere on the board
DDR3_A3: RN20.2 (R2.1), U23.N2 (A3), U24.N2 (A3); also elsewhere on the board
DDR3_A4: RN18.1 (R1.1), U23.P8 (A4), U24.P8 (A4); also elsewhere on the board
DDR3_A5: RN20.1 (R1.1), U23.P2 (A5), U24.P2 (A5); also elsewhere on the board
DDR3_A6: RN17.1 (R1.1), U23.R8 (A6), U24.R8 (A6); also elsewhere on the board
DDR3_A7: RN16.3 (R3.1), U23.R2 (A7), U24.R2 (A7); also elsewhere on the board
DDR3_A8: RN17.2 (R2.1), U23.T8 (A8), U24.T8 (A8); also elsewhere on the board
DDR3_A9: RN16.2 (R2.1), U23.R3 (A9), U24.R3 (A9); also elsewhere on the board
DDR3_A10: RN19.1 (R1.1), U23.L7 (A10/AP), U24.L7 (A10/AP); also elsewhere on the board
DDR3_A11: RN17.4 (R4.1), U23.R7 (A11), U24.R7 (A11); also elsewhere on the board
DDR3_A12: RN18.3 (R3.1), U23.N7 (A12/~BC), U24.N7 (A12/~BC); also elsewhere on the board
DDR3_A13: RN16.1 (R1.1), U23.T3 (A13), U24.T3 (A13); also elsewhere on the board
DDR3_A14: RN17.3 (R3.1), U23.T7 (A14), U24.T7 (A14); also elsewhere on the board
DDR3_BA0: RN20.3 (R3.1), U23.M2 (BA0), U24.M2 (BA0); also elsewhere on the board
DDR3_BA1: RN18.4 (R4.1), U23.N8 (BA1), U24.N8 (BA1); also elsewhere on the board
DDR3_BA2: RN19.3 (R3.1), U23.M3 (BA2), U24.M3 (BA2); also elsewhere on the board
DDR3_CAS: RN21.4 (R4.1), U23.J3 (~RAS), U24.J3 (~RAS); also elsewhere on the board
DDR3_CKE: RN21.3 (R3.1), U23.K9 (CKE), U24.K9 (CKE); also elsewhere on the board
DDR3_CLK+: R75.1, U23.J7 (CK+), U24.J7 (CK+); also elsewhere on the board
DDR3_CLK-: R76.2, U23.K7 (CK-), U24.K7 (CK-); also elsewhere on the board
DDR3_CS: RN20.4 (R4.1), U23.L2 (~CS), U24.L2 (~CS); also elsewhere on the board
DDR3_DM0: U23.E7 (LDM); also elsewhere on the board
DDR3_DM1: U23.D3 (UDM); also elsewhere on the board
DDR3_DM2: U24.E7 (LDM); also elsewhere on the board
DDR3_DM3: U24.D3 (UDM); also elsewhere on the board
DDR3_DQ0: U23.E3 (DQ0); also elsewhere on the board
DDR3_DQ1: U23.F7 (DQ1); also elsewhere on the board
DDR3_DQ2: U23.F2 (DQ2); also elsewhere on the board
DDR3_DQ3: U23.F8 (DQ3); also elsewhere on the board
DDR3_DQ4: U23.H3 (DQ4); also elsewhere on the board
DDR3_DQ5: U23.H8 (DQ5); also elsewhere on the board
DDR3_DQ6: U23.G2 (DQ6); also elsewhere on the board
DDR3_DQ7: U23.H7 (DQ7); also elsewhere on the board
DDR3_DQ8: U23.D7 (DQ8); also elsewhere on the board
DDR3_DQ9: U23.C3 (DQ9); also elsewhere on the board
DDR3_DQ10: U23.C8 (DQ10); also elsewhere on the board
DDR3_DQ11: U23.C2 (DQ11); also elsewhere on the board
DDR3_DQ12: U23.A7 (DQ12); also elsewhere on the board
DDR3_DQ13: U23.A2 (DQ13); also elsewhere on the board
DDR3_DQ14: U23.B8 (DQ14); also elsewhere on the board
DDR3_DQ15: U23.A3 (DQ15); also elsewhere on the board
DDR3_DQ16: U24.E3 (DQ0); also elsewhere on the board
DDR3_DQ17: U24.F7 (DQ1); also elsewhere on the board
DDR3_DQ18: U24.F2 (DQ2); also elsewhere on the board
DDR3_DQ19: U24.F8 (DQ3); also elsewhere on the board
DDR3_DQ20: U24.H3 (DQ4); also elsewhere on the board
DDR3_DQ21: U24.H8 (DQ5); also elsewhere on the board
DDR3_DQ22: U24.G2 (DQ6); also elsewhere on the board
DDR3_DQ23: U24.H7 (DQ7); also elsewhere on the board
DDR3_DQ24: U24.D7 (DQ8); also elsewhere on the board
DDR3_DQ25: U24.C3 (DQ9); also elsewhere on the board
DDR3_DQ26: U24.C8 (DQ10); also elsewhere on the board
DDR3_DQ27: U24.C2 (DQ11); also elsewhere on the board
DDR3_DQ28: U24.A7 (DQ12); also elsewhere on the board
DDR3_DQ29: U24.A2 (DQ13); also elsewhere on the board
DDR3_DQ30: U24.B8 (DQ14); also elsewhere on the board
DDR3_DQ31: U24.A3 (DQ15); also elsewhere on the board
DDR3_DQS0+: U23.F3 (LDQS+); also elsewhere on the board
DDR3_DQS0-: U23.G3 (LDQS-); also elsewhere on the board
DDR3_DQS1+: U23.C7 (UDQS+); also elsewhere on the board
DDR3_DQS1-: U23.B7 (UDQS-); also elsewhere on the board
DDR3_DQS2+: U24.F3 (LDQS+); also elsewhere on the board
DDR3_DQS2-: U24.G3 (LDQS-); also elsewhere on the board
DDR3_DQS3+: U24.C7 (UDQS+); also elsewhere on the board
DDR3_DQS3-: U24.B7 (UDQS-); also elsewhere on the board
DDR3_ODT: RN21.2 (R2.1), U23.K1 (ODT), U24.K1 (ODT); also elsewhere on the board
DDR3_RAS: RN21.1 (R1.1), U23.K3 (~CAS), U24.K3 (~CAS); also elsewhere on the board
DDR3_RESET: U23.T2 (~RESET), U24.T2 (~RESET); also elsewhere on the board
DDR3_Vref: C181.1, C201.1, C202.1, C207.1, C208.1, U23.H1 (VrefDQ), U23.M8 (VrefCA), U24.H1 (VrefDQ), U24.M8 (VrefCA), U25.6 (REFOUT); also elsewhere on the board
DDR3_Vtt_EN: U25.7 (EN); also elsewhere on the board
DDR3_WE: RN19.2 (R2.1), U23.L3 (~WE), U24.L3 (~WE); also elsewhere on the board
GND: C174.2, C175.1, C176.2, C177.2, C178.2, C179.2, C180.2, C181.2, C182.2, C183.2, C184.2, C185.2, C186.2, C187.2, C188.2, C189.2, C190.2, C191.2, C192.2, C193.2, C194.2, C195.2, C196.2, C197.2, C198.2, C199.2, C200.2, C201.2, C202.2, C203.2, C204.2, C205.2, C206.2, C207.2, C208.2, C209.2, C210.2, C211.2, C212.2, R78.1, R80.2, R81.2, U23.A9 (Vss), U23.B1 (VssQ), U23.B3 (Vss), U23.B9 (VssQ), U23.D1 (VssQ), U23.D8 (VssQ), U23.E1 (Vss), U23.E2 (VssQ), U23.E8 (VssQ), U23.F9 (VssQ), U23.G1 (VssQ), U23.G8 (Vss), U23.G9 (VssQ), U23.J2 (Vss), U23.J8 (Vss), U23.M1 (Vss), U23.M9 (Vss), U23.P1 (Vss), U23.P9 (Vss), U23.T1 (Vss), U23.T9 (Vss), U24.A9 (Vss), U24.B1 (VssQ), U24.B3 (Vss), U24.B9 (VssQ), U24.D1 (VssQ), U24.D8 (VssQ), U24.E1 (Vss), U24.E2 (VssQ), U24.E8 (VssQ), U24.F9 (VssQ), U24.G1 (VssQ), U24.G8 (Vss), U24.G9 (VssQ), U24.J2 (Vss), U24.J8 (Vss), U24.M1 (Vss), U24.M9 (Vss), U24.P1 (Vss), U24.P9 (Vss), U24.T1 (Vss), U24.T9 (Vss), U25.4 (GND), U25.8 (GND), U25.11 (GND); also elsewhere on the board
unnamed: C175.2, R75.2, R76.1
unnamed: C179.1, R77.1, R78.2, U25.1 (REFIN)
unnamed: R79.1, U25.9 (PGOOD)
unnamed: R80.1, U23.L8 (ZQ)
unnamed: R81.1, U24.L8 (ZQ)

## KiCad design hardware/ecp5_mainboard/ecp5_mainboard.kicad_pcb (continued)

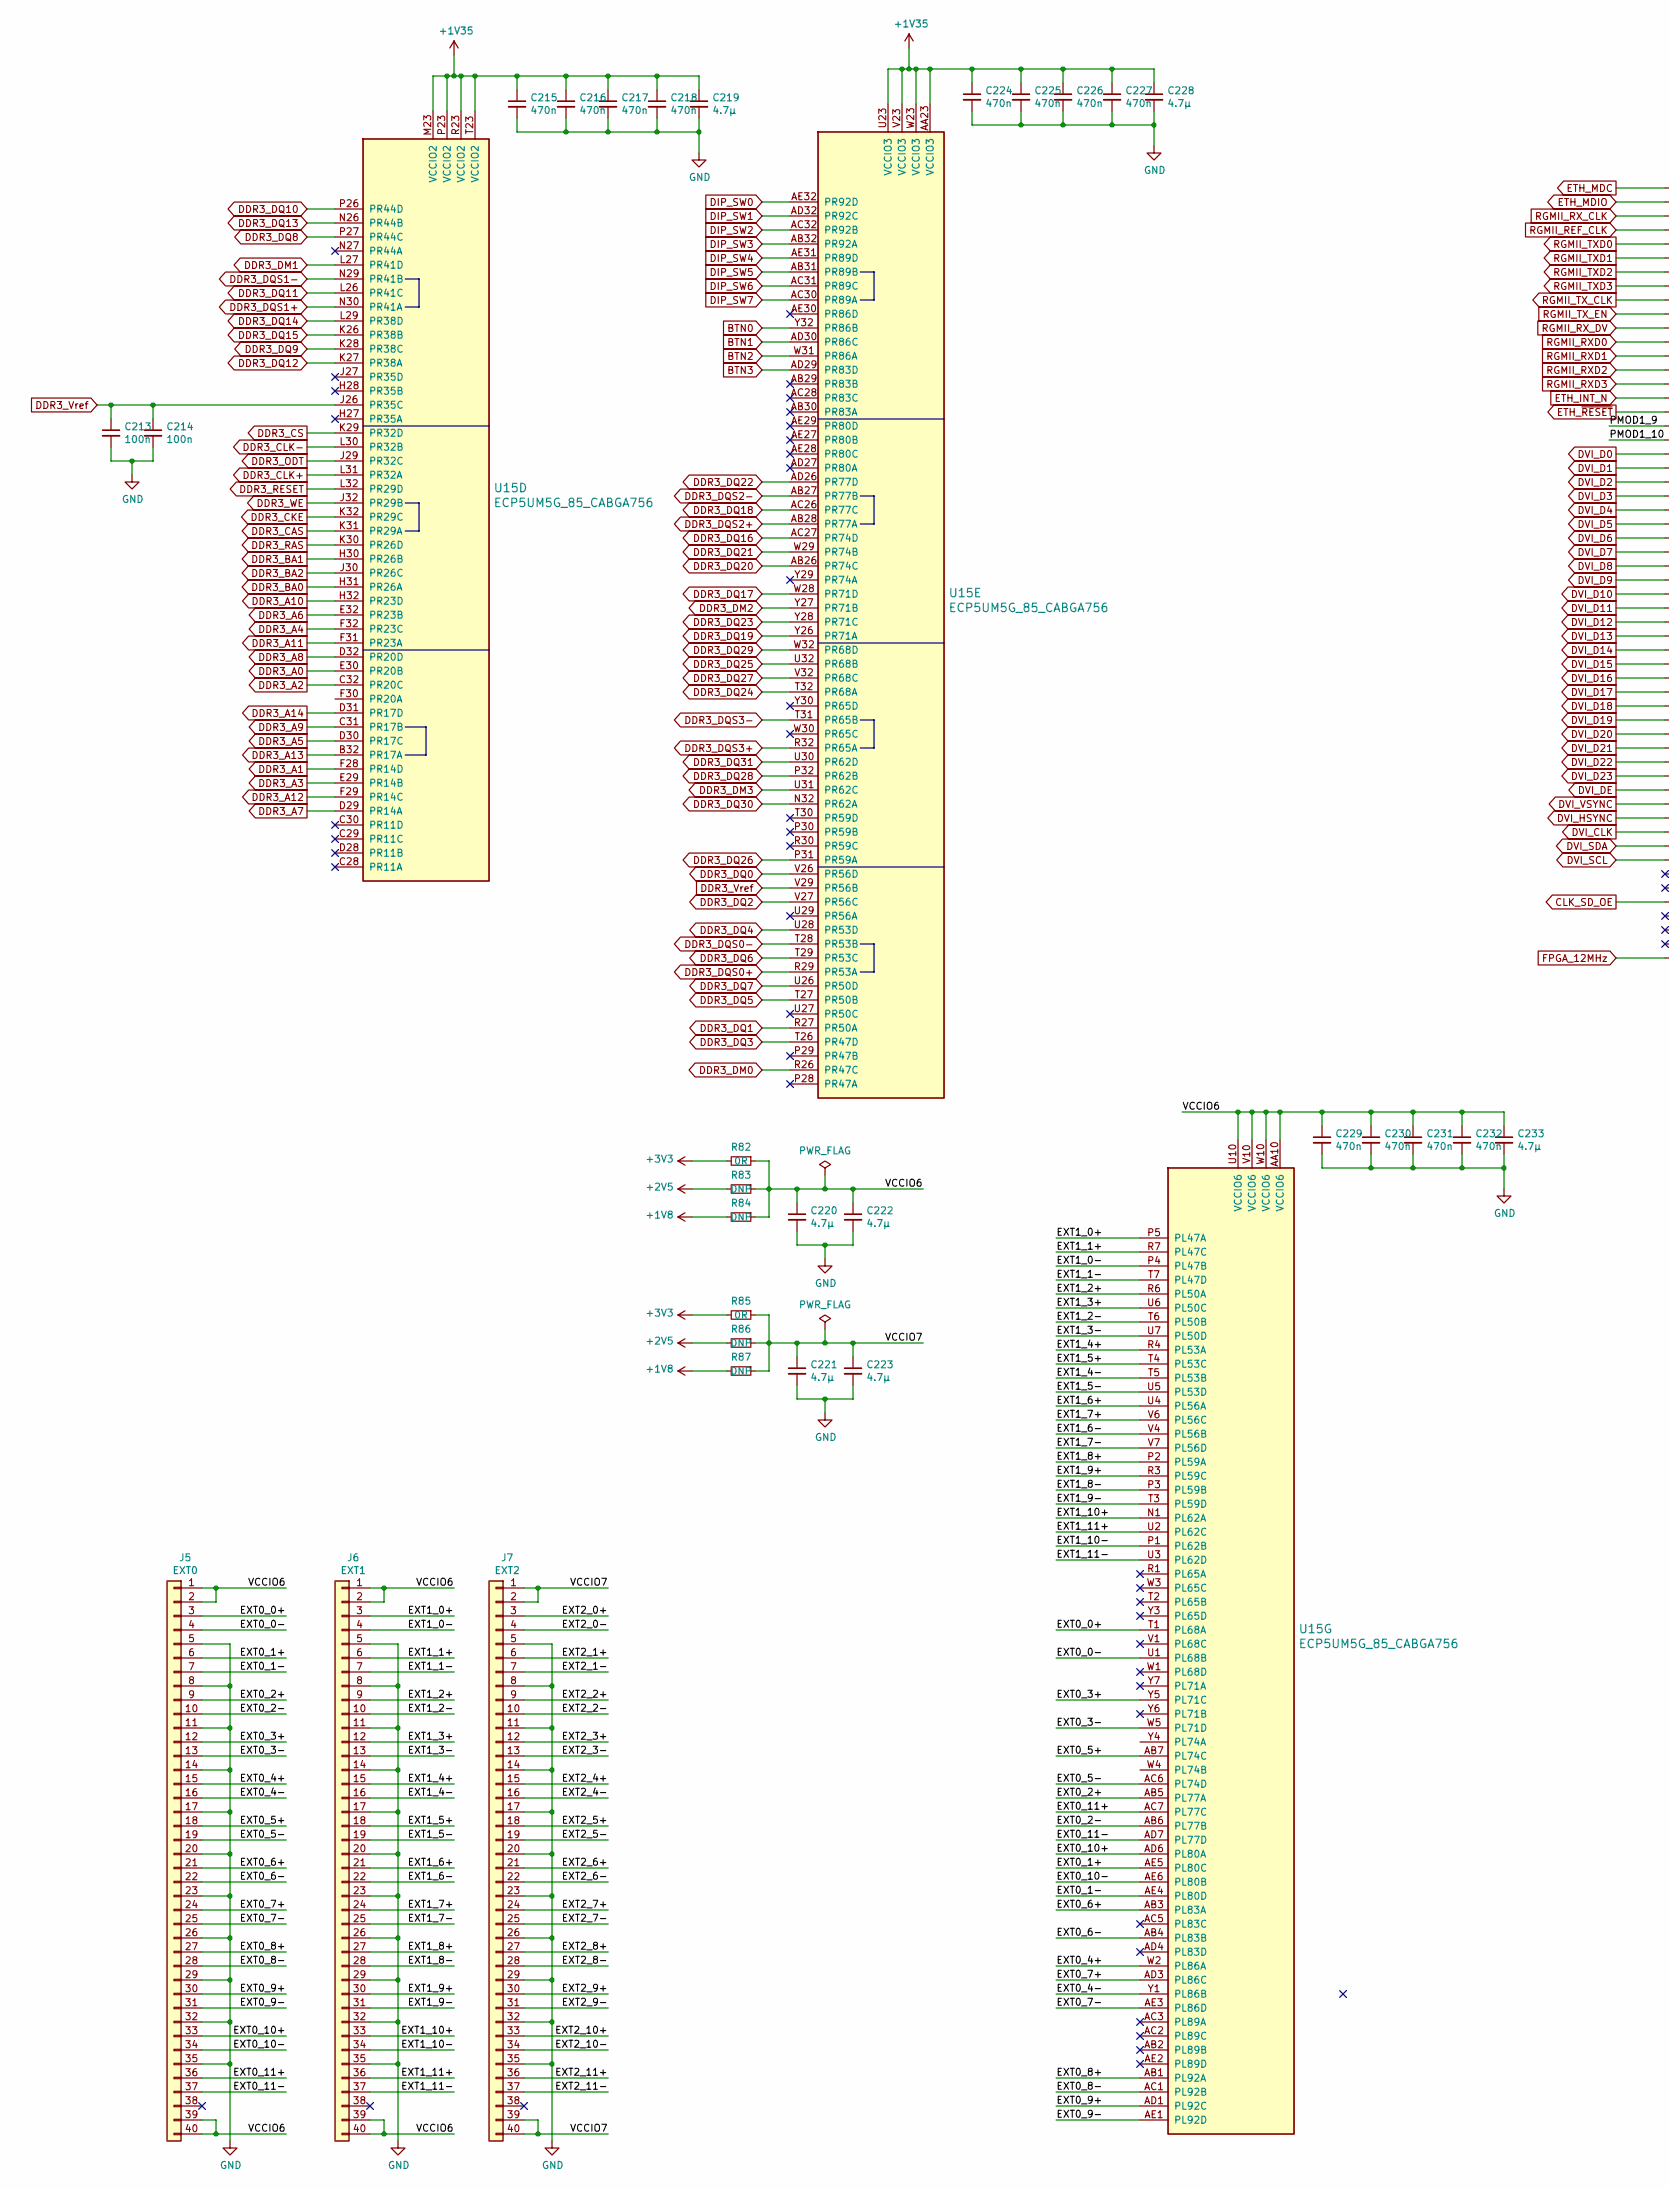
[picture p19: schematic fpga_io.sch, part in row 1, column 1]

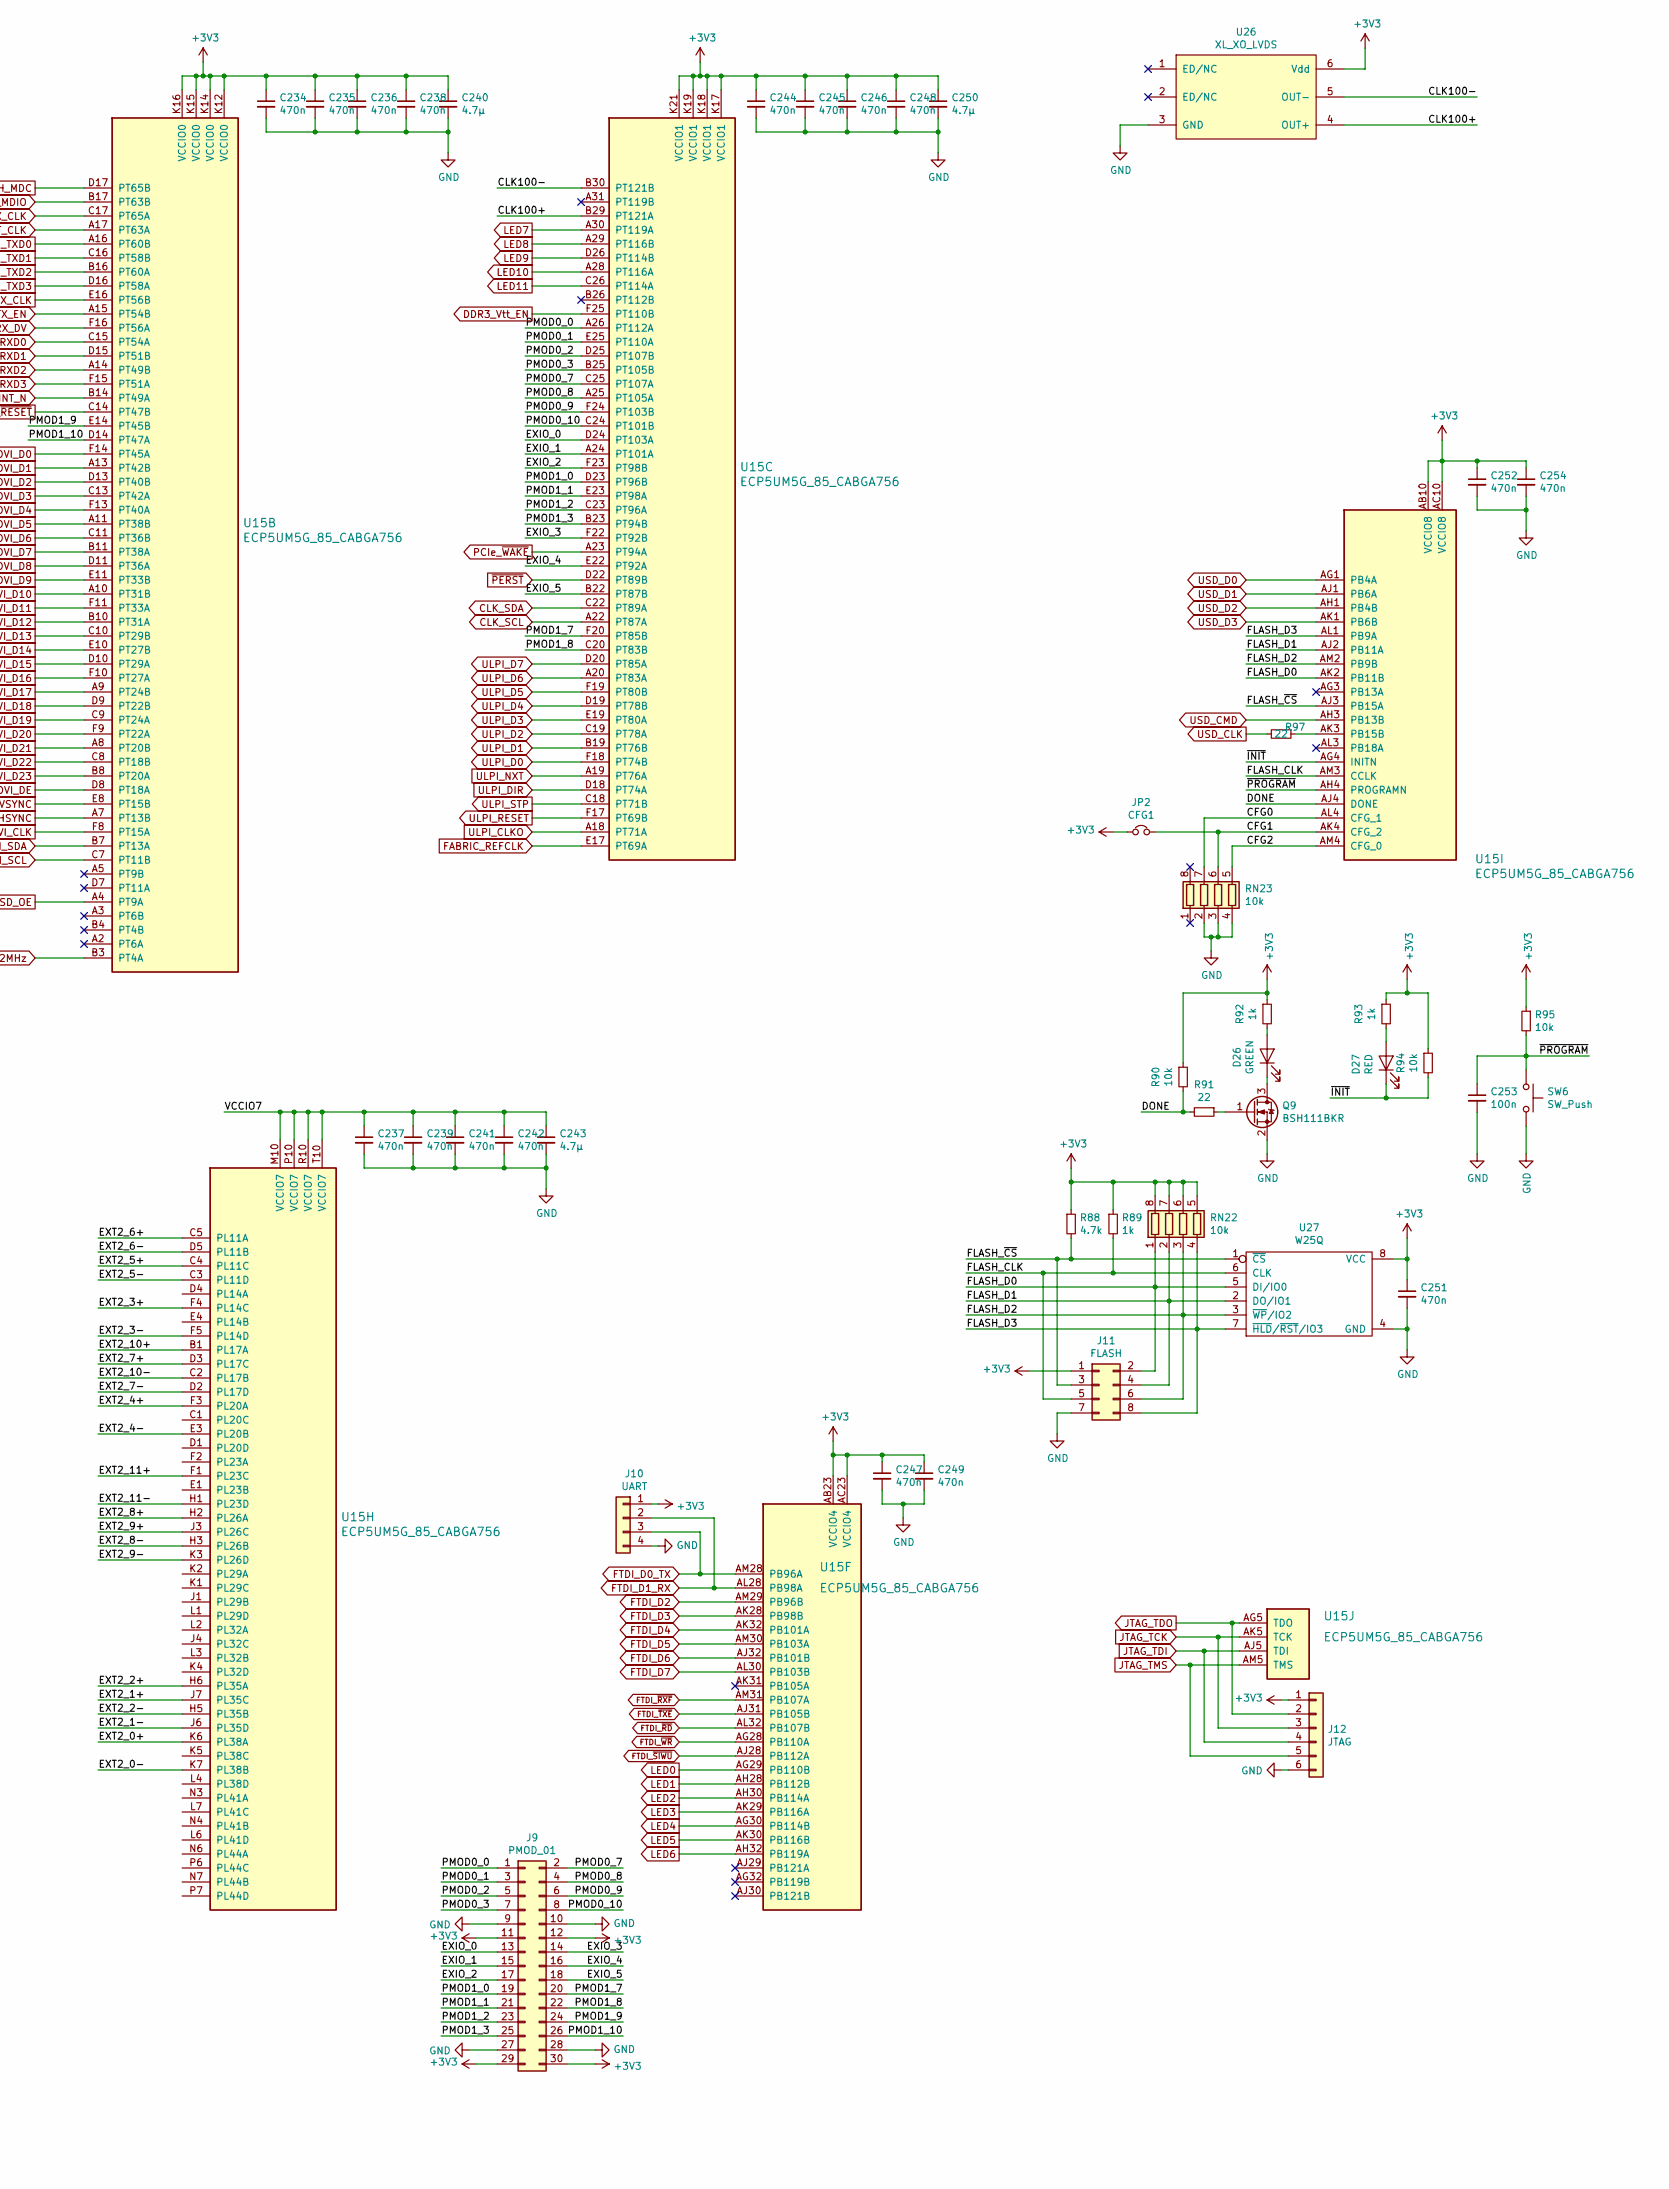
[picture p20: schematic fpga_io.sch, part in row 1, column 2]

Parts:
C213, C214, C253: 100n; C_0402_1005Metric
C215, C216, C217, C218, C224, C225, C226, C227, C229, C230, C231, C232, C234, C235, C236, C237, C238, C239, C241, C242, C244, C245, C246, C247, C248, C249, C251, C252, C254: 470n; C_0402_1005Metric
C219, C220, C221, C222, C223, C228, C233, C240, C243, C250: 4.7µ; C_0603_1608Metric
D26: GREEN; LED_0805_2012Metric
D27: RED; LED_0805_2012Metric
J5: EXT0; TE_FPC_40pin_p0.5mm_4-1734839-0
J6: EXT1; TE_FPC_40pin_p0.5mm_4-1734839-0
J7: EXT2; TE_FPC_40pin_p0.5mm_4-1734839-0
J9: PMOD_01; PinHeader_2x15_P2.54mm_Horizontal
J10: UART; PinHeader_1x04_P2.54mm_Vertical
J11: FLASH; PinHeader_2x04_P2.54mm_Vertical
J12: JTAG; PinHeader_1x06_P2.54mm_Vertical
JP2: CFG1; PinHeader_1x02_P2.54mm_Vertical
Q9: BSH111BKR; SOT-23
R82, R85: 0R; R_0805_2012Metric
R83, R84, R86, R87: DNP; R_0805_2012Metric
R88: 4.7k; R_0402_1005Metric
R89, R92, R93: 1k; R_0402_1005Metric
R90, R94, R95: 10k; R_0402_1005Metric
R91, R97: 22; R_0402_1005Metric
RN22, RN23: 10k; R_Array_Convex_4x0402
SW6: SW_Push; SW_SPST_B3S-1000
U15: ECP5UM5G_85_CABGA756; CABGA756_27x27mm_p0.8mm
U26: XL_XO_LVDS; OSC_IDT_XU_5x3.2mm
U27: W25Q; SO-8_5.3x6.2mm_P1.27mm

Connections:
+1V8: R84.2, R87.2; also elsewhere on the board
+1V35: C215.1, C216.1, C217.1, C218.1, C219.1, C224.1, C225.1, C226.1, C227.1, C228.1, U15.AA23 (VCCIO3), U15.M23 (VCCIO2), U15.P23 (VCCIO2), U15.R23 (VCCIO2), U15.T23 (VCCIO2), U15.U23 (VCCIO3), U15.V23 (VCCIO3), U15.W23 (VCCIO3); also elsewhere on the board
+2V5: R83.2, R86.2; also elsewhere on the board
+3V3: C234.1, C235.1, C236.1, C238.1, C240.1, C244.1, C245.1, C246.1, C247.1, C248.1, C249.1, C250.1, C251.1, C252.1, C254.1, J9.11, J9.12, J9.29, J9.30, J10.1, J11.1, J12.1, JP2.1, R82.2, R85.2, R88.1, R89.1, R90.1, R92.1, R93.1, R94.1, R95.1, RN22.5 (R4.2), RN22.6 (R3.2), RN22.7 (R2.2), RN22.8 (R1.2), U15.AB10 (VCCIO8), U15.AB23 (VCCIO4), U15.AC10 (VCCIO8), U15.AC23 (VCCIO4), U15.K12 (VCCIO0), U15.K14 (VCCIO0), U15.K15 (VCCIO0), U15.K16 (VCCIO0), U15.K17 (VCCIO1), U15.K18 (VCCIO1), U15.K19 (VCCIO1), U15.K21 (VCCIO1), U26.6 (Vdd), U27.8 (VCC); also elsewhere on the board
/FPGA IO/CFG0: RN23.7 (R2.2), U15.AL4 (CFG_1)
/FPGA IO/CFG1: JP2.2, RN23.6 (R3.2), U15.AK4 (CFG_2)
/FPGA IO/CFG2: RN23.5 (R4.2), U15.AM4 (CFG_0)
/FPGA IO/CLK100+: U15.B29 (PT121A), U26.4 (OUT+)
/FPGA IO/CLK100-: U15.B30 (PT121B), U26.5 (OUT-)
/FPGA IO/DONE: R90.2, R91.2, U15.AJ4 (DONE)
/FPGA IO/EXIO_0: J9.13, U15.D24 (PT103A)
/FPGA IO/EXIO_1: J9.15, U15.A24 (PT101A)
/FPGA IO/EXIO_2: J9.17, U15.F23 (PT98B)
/FPGA IO/EXIO_3: J9.14, U15.F22 (PT92B)
/FPGA IO/EXIO_4: J9.16, U15.E22 (PT92A)
/FPGA IO/EXIO_5: J9.18, U15.B22 (PT87B)
/FPGA IO/EXT0_0+: J5.3, U15.T1 (PL68A)
/FPGA IO/EXT0_0-: J5.4, U15.U1 (PL68B)
/FPGA IO/EXT0_1+: J5.6, U15.AE5 (PL80C)
/FPGA IO/EXT0_1-: J5.7, U15.AE4 (PL80D)
/FPGA IO/EXT0_2+: J5.9, U15.AB5 (PL77A)
/FPGA IO/EXT0_2-: J5.10, U15.AB6 (PL77B)
/FPGA IO/EXT0_3+: J5.12, U15.Y5 (PL71C)
/FPGA IO/EXT0_3-: J5.13, U15.W5 (PL71D)
/FPGA IO/EXT0_4+: J5.15, U15.W2 (PL86A)
/FPGA IO/EXT0_4-: J5.16, U15.Y1 (PL86B)
/FPGA IO/EXT0_5+: J5.18, U15.AB7 (PL74C)
/FPGA IO/EXT0_5-: J5.19, U15.AC6 (PL74D)
/FPGA IO/EXT0_6+: J5.21, U15.AB3 (PL83A)
/FPGA IO/EXT0_6-: J5.22, U15.AB4 (PL83B)
/FPGA IO/EXT0_7+: J5.24, U15.AD3 (PL86C)
/FPGA IO/EXT0_7-: J5.25, U15.AE3 (PL86D)
/FPGA IO/EXT0_8+: J5.27, U15.AB1 (PL92A)
/FPGA IO/EXT0_8-: J5.28, U15.AC1 (PL92B)
/FPGA IO/EXT0_9+: J5.30, U15.AD1 (PL92C)
/FPGA IO/EXT0_9-: J5.31, U15.AE1 (PL92D)
/FPGA IO/EXT0_10+: J5.33, U15.AD6 (PL80A)
/FPGA IO/EXT0_10-: J5.34, U15.AE6 (PL80B)
/FPGA IO/EXT0_11+: J5.36, U15.AC7 (PL77C)
/FPGA IO/EXT0_11-: J5.37, U15.AD7 (PL77D)
/FPGA IO/EXT1_0+: J6.3, U15.P5 (PL47A)
/FPGA IO/EXT1_0-: J6.4, U15.P4 (PL47B)
/FPGA IO/EXT1_1+: J6.6, U15.R7 (PL47C)
/FPGA IO/EXT1_1-: J6.7, U15.T7 (PL47D)
/FPGA IO/EXT1_2+: J6.9, U15.R6 (PL50A)
/FPGA IO/EXT1_2-: J6.10, U15.T6 (PL50B)
/FPGA IO/EXT1_3+: J6.12, U15.U6 (PL50C)
/FPGA IO/EXT1_3-: J6.13, U15.U7 (PL50D)
/FPGA IO/EXT1_4+: J6.15, U15.R4 (PL53A)
/FPGA IO/EXT1_4-: J6.16, U15.T5 (PL53B)
/FPGA IO/EXT1_5+: J6.18, U15.T4 (PL53C)
/FPGA IO/EXT1_5-: J6.19, U15.U5 (PL53D)
/FPGA IO/EXT1_6+: J6.21, U15.U4 (PL56A)
/FPGA IO/EXT1_6-: J6.22, U15.V4 (PL56B)
/FPGA IO/EXT1_7+: J6.24, U15.V6 (PL56C)
/FPGA IO/EXT1_7-: J6.25, U15.V7 (PL56D)
/FPGA IO/EXT1_8+: J6.27, U15.P2 (PL59A)
/FPGA IO/EXT1_8-: J6.28, U15.P3 (PL59B)
/FPGA IO/EXT1_9+: J6.30, U15.R3 (PL59C)
/FPGA IO/EXT1_9-: J6.31, U15.T3 (PL59D)
/FPGA IO/EXT1_10+: J6.33, U15.N1 (PL62A)
/FPGA IO/EXT1_10-: J6.34, U15.P1 (PL62B)
/FPGA IO/EXT1_11+: J6.36, U15.U2 (PL62C)
/FPGA IO/EXT1_11-: J6.37, U15.U3 (PL62D)
/FPGA IO/EXT2_0+: J7.3, U15.K6 (PL38A)
/FPGA IO/EXT2_0-: J7.4, U15.K7 (PL38B)
/FPGA IO/EXT2_1+: J7.6, U15.J7 (PL35C)
/FPGA IO/EXT2_1-: J7.7, U15.J6 (PL35D)
/FPGA IO/EXT2_2+: J7.9, U15.H6 (PL35A)
/FPGA IO/EXT2_2-: J7.10, U15.H5 (PL35B)
/FPGA IO/EXT2_3+: J7.12, U15.F4 (PL14C)
/FPGA IO/EXT2_3-: J7.13, U15.F5 (PL14D)
/FPGA IO/EXT2_4+: J7.15, U15.F3 (PL20A)
/FPGA IO/EXT2_4-: J7.16, U15.E3 (PL20B)
/FPGA IO/EXT2_5+: J7.18, U15.C4 (PL11C)
/FPGA IO/EXT2_5-: J7.19, U15.C3 (PL11D)
/FPGA IO/EXT2_6+: J7.21, U15.C5 (PL11A)
/FPGA IO/EXT2_6-: J7.22, U15.D5 (PL11B)
/FPGA IO/EXT2_7+: J7.24, U15.D3 (PL17C)
/FPGA IO/EXT2_7-: J7.25, U15.D2 (PL17D)
/FPGA IO/EXT2_8+: J7.27, U15.H2 (PL26A)
/FPGA IO/EXT2_8-: J7.28, U15.H3 (PL26B)
/FPGA IO/EXT2_9+: J7.30, U15.J3 (PL26C)
/FPGA IO/EXT2_9-: J7.31, U15.K3 (PL26D)
/FPGA IO/EXT2_10+: J7.33, U15.B1 (PL17A)
/FPGA IO/EXT2_10-: J7.34, U15.C2 (PL17B)
/FPGA IO/EXT2_11+: J7.36, U15.F1 (PL23C)
/FPGA IO/EXT2_11-: J7.37, U15.H1 (PL23D)
/FPGA IO/FLASH_CLK: J11.5, R89.2, U15.AM3 (CCLK), U27.6 (CLK)
/FPGA IO/FLASH_D0: J11.2, RN22.1 (R1.1), U15.AK2 (PB11B), U27.5 (DI/IO0)
/FPGA IO/FLASH_D1: J11.4, RN22.2 (R2.1), U15.AJ2 (PB11A), U27.2 (DO/IO1)
/FPGA IO/FLASH_D2: J11.6, RN22.3 (R3.1), U15.AM2 (PB9B), U27.3 (~WP~/IO2)
/FPGA IO/FLASH_D3: J11.8, RN22.4 (R4.1), U15.AL1 (PB9A), U27.7 (~HLD~/~RST~/IO3)
/FPGA IO/FLASH_~CS: J11.3, R88.2, U15.AJ3 (PB15A), U27.1 (~CS)
/FPGA IO/PMOD0_0: J9.1, U15.A26 (PT112A)
/FPGA IO/PMOD0_1: J9.3, U15.E25 (PT110A)
/FPGA IO/PMOD0_2: J9.5, U15.D25 (PT107B)
/FPGA IO/PMOD0_3: J9.7, U15.B25 (PT105B)
/FPGA IO/PMOD0_7: J9.2, U15.C25 (PT107A)
/FPGA IO/PMOD0_8: J9.4, U15.A25 (PT105A)
/FPGA IO/PMOD0_9: J9.6, U15.F24 (PT103B)
/FPGA IO/PMOD0_10: J9.8, U15.C24 (PT101B)
/FPGA IO/PMOD1_0: J9.19, U15.D23 (PT96B)
/FPGA IO/PMOD1_1: J9.21, U15.E23 (PT98A)
/FPGA IO/PMOD1_2: J9.23, U15.C23 (PT96A)
/FPGA IO/PMOD1_3: J9.25, U15.B23 (PT94B)
/FPGA IO/PMOD1_7: J9.20, U15.F20 (PT85B)
/FPGA IO/PMOD1_8: J9.22, U15.C20 (PT83B)
/FPGA IO/PMOD1_9: J9.24, U15.E14 (PT45B)
/FPGA IO/PMOD1_10: J9.26, U15.D14 (PT47A)
/FPGA IO/VCCIO6: C220.1, C222.1, C229.1, C230.1, C231.1, C232.1, C233.1, J5.1, J5.2, J5.39, J5.40, J6.1, J6.2, J6.39, J6.40, R82.1, R83.1, R84.1, U15.AA10 (VCCIO6), U15.U10 (VCCIO6), U15.V10 (VCCIO6), U15.W10 (VCCIO6)
/FPGA IO/VCCIO7: C221.1, C223.1, C237.1, C239.1, C241.1, C242.1, C243.1, J7.1, J7.2, J7.39, J7.40, R85.1, R86.1, R87.1, U15.M10 (VCCIO7), U15.P10 (VCCIO7), U15.R10 (VCCIO7), U15.T10 (VCCIO7)
/FPGA IO/~INIT: D27.1 (K), R94.2, U15.AG4 (INITN)
/FPGA IO/~PROGRAM: C253.1, R95.2, SW6.2, U15.AH4 (PROGRAMN)
BTN0: U15.Y32 (PR86B); also elsewhere on the board
BTN1: U15.AD30 (PR86C); also elsewhere on the board
BTN2: U15.W31 (PR86A); also elsewhere on the board
BTN3: U15.AD29 (PR83D); also elsewhere on the board
CLK_SCL: U15.A22 (PT87A); also elsewhere on the board
CLK_SDA: U15.C22 (PT89A); also elsewhere on the board
CLK_SD_OE: U15.A4 (PT9A); also elsewhere on the board
DDR3_A0: U15.E30 (PR20B); also elsewhere on the board
DDR3_A1: U15.F28 (PR14D); also elsewhere on the board
DDR3_A2: U15.C32 (PR20C); also elsewhere on the board
DDR3_A3: U15.E29 (PR14B); also elsewhere on the board
DDR3_A4: U15.F32 (PR23C); also elsewhere on the board
DDR3_A5: U15.D30 (PR17C); also elsewhere on the board
DDR3_A6: U15.E32 (PR23B); also elsewhere on the board
DDR3_A7: U15.D29 (PR14A); also elsewhere on the board
DDR3_A8: U15.D32 (PR20D); also elsewhere on the board
DDR3_A9: U15.C31 (PR17B); also elsewhere on the board
DDR3_A10: U15.H32 (PR23D); also elsewhere on the board
DDR3_A11: U15.F31 (PR23A); also elsewhere on the board
DDR3_A12: U15.F29 (PR14C); also elsewhere on the board
DDR3_A13: U15.B32 (PR17A); also elsewhere on the board
DDR3_A14: U15.D31 (PR17D); also elsewhere on the board
DDR3_BA0: U15.H31 (PR26A); also elsewhere on the board
DDR3_BA1: U15.H30 (PR26B); also elsewhere on the board
DDR3_BA2: U15.J30 (PR26C); also elsewhere on the board
DDR3_CAS: U15.K31 (PR29A); also elsewhere on the board
DDR3_CKE: U15.K32 (PR29C); also elsewhere on the board
DDR3_CLK+: U15.L31 (PR32A); also elsewhere on the board
DDR3_CLK-: U15.L30 (PR32B); also elsewhere on the board
DDR3_CS: U15.K29 (PR32D); also elsewhere on the board
DDR3_DM0: U15.R26 (PR47C); also elsewhere on the board
DDR3_DM1: U15.L27 (PR41D); also elsewhere on the board
DDR3_DM2: U15.Y27 (PR71B); also elsewhere on the board
DDR3_DM3: U15.U31 (PR62C); also elsewhere on the board
DDR3_DQ0: U15.V26 (PR56D); also elsewhere on the board
DDR3_DQ1: U15.R27 (PR50A); also elsewhere on the board
DDR3_DQ2: U15.V27 (PR56C); also elsewhere on the board
DDR3_DQ3: U15.T26 (PR47D); also elsewhere on the board
DDR3_DQ4: U15.U28 (PR53D); also elsewhere on the board
DDR3_DQ5: U15.T27 (PR50B); also elsewhere on the board
DDR3_DQ6: U15.T29 (PR53C); also elsewhere on the board
DDR3_DQ7: U15.U26 (PR50D); also elsewhere on the board
DDR3_DQ8: U15.P27 (PR44C); also elsewhere on the board
DDR3_DQ9: U15.K28 (PR38C); also elsewhere on the board
DDR3_DQ10: U15.P26 (PR44D); also elsewhere on the board
DDR3_DQ11: U15.L26 (PR41C); also elsewhere on the board
DDR3_DQ12: U15.K27 (PR38A); also elsewhere on the board
DDR3_DQ13: U15.N26 (PR44B); also elsewhere on the board
DDR3_DQ14: U15.L29 (PR38D); also elsewhere on the board
DDR3_DQ15: U15.K26 (PR38B); also elsewhere on the board
DDR3_DQ16: U15.AC27 (PR74D); also elsewhere on the board
DDR3_DQ17: U15.W28 (PR71D); also elsewhere on the board
DDR3_DQ18: U15.AC26 (PR77C); also elsewhere on the board
DDR3_DQ19: U15.Y26 (PR71A); also elsewhere on the board
DDR3_DQ20: U15.AB26 (PR74C); also elsewhere on the board
DDR3_DQ21: U15.W29 (PR74B); also elsewhere on the board
DDR3_DQ22: U15.AD26 (PR77D); also elsewhere on the board
DDR3_DQ23: U15.Y28 (PR71C); also elsewhere on the board
DDR3_DQ24: U15.T32 (PR68A); also elsewhere on the board
DDR3_DQ25: U15.U32 (PR68B); also elsewhere on the board
DDR3_DQ26: U15.P31 (PR59A); also elsewhere on the board
DDR3_DQ27: U15.V32 (PR68C); also elsewhere on the board
DDR3_DQ28: U15.P32 (PR62B); also elsewhere on the board
DDR3_DQ29: U15.W32 (PR68D); also elsewhere on the board
DDR3_DQ30: U15.N32 (PR62A); also elsewhere on the board
DDR3_DQ31: U15.U30 (PR62D); also elsewhere on the board
DDR3_DQS0+: U15.R29 (PR53A); also elsewhere on the board
DDR3_DQS0-: U15.T28 (PR53B); also elsewhere on the board
DDR3_DQS1+: U15.N30 (PR41A); also elsewhere on the board
DDR3_DQS1-: U15.N29 (PR41B); also elsewhere on the board
DDR3_DQS2+: U15.AB28 (PR77A); also elsewhere on the board
DDR3_DQS2-: U15.AB27 (PR77B); also elsewhere on the board
DDR3_DQS3+: U15.R32 (PR65A); also elsewhere on the board
DDR3_DQS3-: U15.T31 (PR65B); also elsewhere on the board
DDR3_ODT: U15.J29 (PR32C); also elsewhere on the board
DDR3_RAS: U15.K30 (PR26D); also elsewhere on the board
DDR3_RESET: U15.L32 (PR29D); also elsewhere on the board
DDR3_Vref: C213.1, C214.1, U15.J26 (PR35C), U15.V29 (PR56B); also elsewhere on the board
DDR3_Vtt_EN: U15.F25 (PT110B); also elsewhere on the board
DDR3_WE: U15.J32 (PR29B); also elsewhere on the board
DIP_SW0: U15.AE32 (PR92D); also elsewhere on the board
DIP_SW1: U15.AD32 (PR92C); also elsewhere on the board
DIP_SW2: U15.AC32 (PR92B); also elsewhere on the board
DIP_SW3: U15.AB32 (PR92A); also elsewhere on the board
DIP_SW4: U15.AE31 (PR89D); also elsewhere on the board
DIP_SW5: U15.AB31 (PR89B); also elsewhere on the board
DIP_SW6: U15.AC31 (PR89C); also elsewhere on the board
DIP_SW7: U15.AC30 (PR89A); also elsewhere on the board
DVI_CLK: U15.F8 (PT15A); also elsewhere on the board
DVI_D0: U15.F14 (PT45A); also elsewhere on the board
DVI_D1: U15.A13 (PT42B); also elsewhere on the board
DVI_D2: U15.D13 (PT40B); also elsewhere on the board
DVI_D3: U15.C13 (PT42A); also elsewhere on the board
DVI_D4: U15.F13 (PT40A); also elsewhere on the board
DVI_D5: U15.A11 (PT38B); also elsewhere on the board
DVI_D6: U15.C11 (PT36B); also elsewhere on the board
DVI_D7: U15.B11 (PT38A); also elsewhere on the board
DVI_D8: U15.D11 (PT36A); also elsewhere on the board
DVI_D9: U15.E11 (PT33B); also elsewhere on the board
DVI_D10: U15.A10 (PT31B); also elsewhere on the board
DVI_D11: U15.F11 (PT33A); also elsewhere on the board
DVI_D12: U15.B10 (PT31A); also elsewhere on the board
DVI_D13: U15.C10 (PT29B); also elsewhere on the board
DVI_D14: U15.E10 (PT27B); also elsewhere on the board
DVI_D15: U15.D10 (PT29A); also elsewhere on the board
DVI_D16: U15.F10 (PT27A); also elsewhere on the board
DVI_D17: U15.A9 (PT24B); also elsewhere on the board
DVI_D18: U15.D9 (PT22B); also elsewhere on the board
DVI_D19: U15.C9 (PT24A); also elsewhere on the board
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

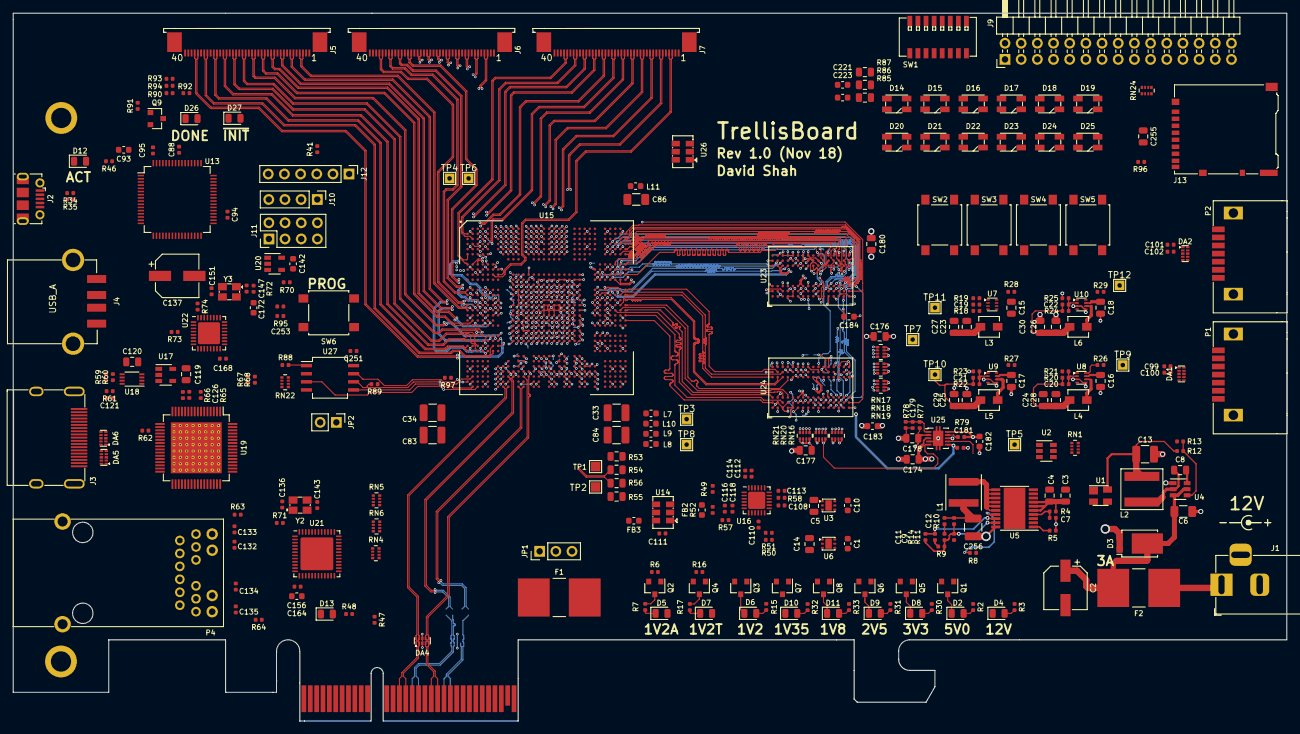
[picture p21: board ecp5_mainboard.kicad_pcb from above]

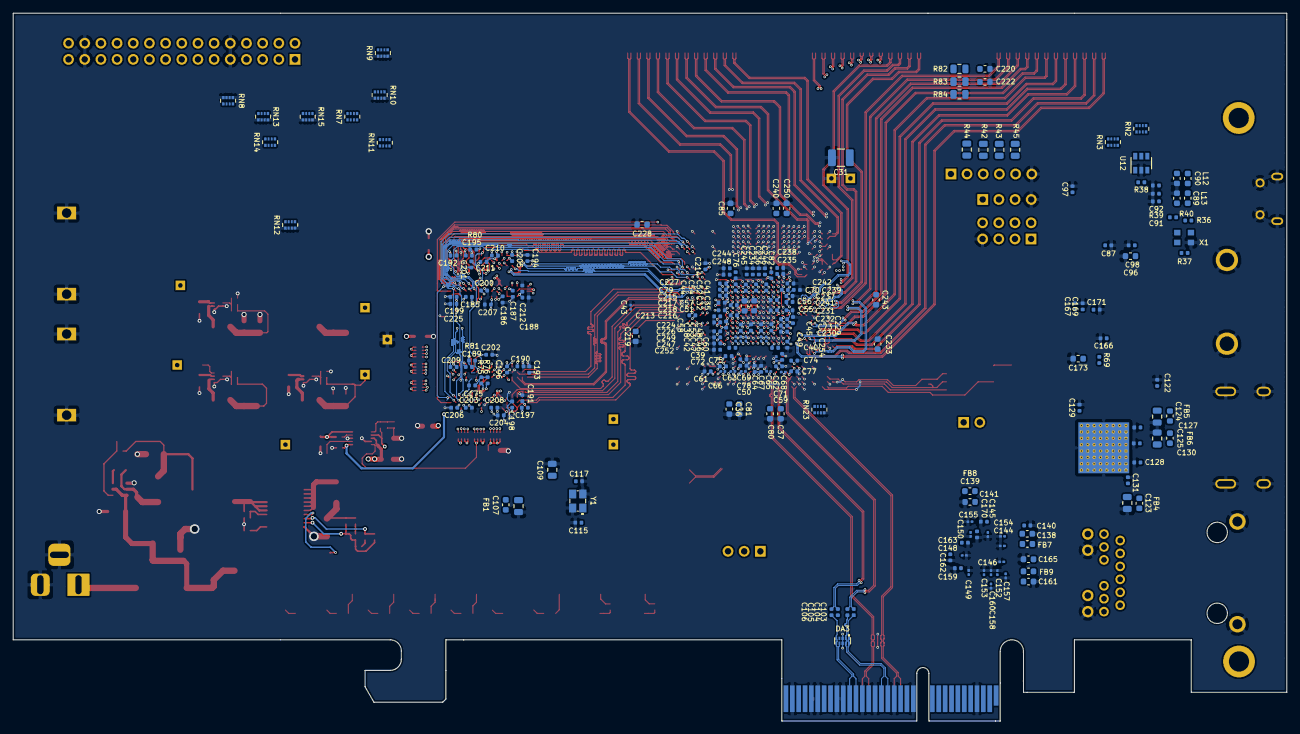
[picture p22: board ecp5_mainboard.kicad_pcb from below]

Board: 8 copper layers, 200.0 x 111.2 mm, 507 parts (213 on the bottom side), 513 nets.

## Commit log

2018-07-28 ecp5_mainboard: Adding empty KiCad project
    [ecp5_mainboard.kicad_pcb, ecp5_mainboard.sch]
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2018-07-29 ecp5_mainboard/power: Add power input circuitry
    [ecp5_mainboard.sch, power.sch]
2018-07-29 ecp5_mainboard/power: Add 1.8V, 2.5V and 3.3V regulators
    [power.sch]
2018-07-29 ecp5_mainboard/power: Add 1.35V DDR3 and 1.2V FPGA core regulators
    [power.sch]
2018-07-29 ecp5_mainboard/power: Add 1.2V analog and termination supplies
    [power.sch]
2018-07-29 ecp5_mainboard/power: Add startup/sequencing control
    [power.sch]
2018-07-30 ecp5_mainboard/fpga_pwr: Add FPGA power connections
    [ecp5_mainboard.sch, fpga_pwr.sch, power.sch]
2018-07-30 ecp5_mainboard: Run ERC and fix issues
    [fpga_pwr.sch, power.sch]
2018-07-30 ecp5_mainboard/debug: FT2232H JTAG interface and USB-C debug conn
    [debug.sch, ecp5_mainboard.sch, fpga_pwr.sch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]
2018-07-31 ecp5_mainboard/debug: Wiring for FTDI 'B' interface
    [debug.sch]
2018-07-31 ecp5_mainboard: Select 1A/3A current limit for debug USB-C power based on CC voltage
    [debug.sch, power.sch]
2018-08-03 ecp5_mainboard: Adding some 'glue' parts, preparing for USB-C and DP schematics
    [debug.sch, ecp5_mainboard.sch, fpga_pwr.sch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]
2018-08-19 ecp5_mainboard: Starting USB-C and DP schematics
    [usbc_dp.sch]
2018-08-21 ecp5_mainboard: Working on USBC/DP section
    [usbc_dp.sch]
2018-11-19 hardware/mainboard: Major spec change; remove USBC/DP; add PCIe and refclk
    [debug.sch, ecp5_mainboard.sch, power.sch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]
2018-11-19 hardware/mainboard: Add SATA and SATA REFCLK
    [serdes.sch]
2018-11-19 hardware/mainboard: Adding GbE magjack and phy
    [debug.sch, ecp5_mainboard.sch, fpga_pwr.sch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]
2018-11-19 hardware/mainboard: Finish GbE, add ULPI USB and TFP410 DVI/HDMI-out
    [ports.sch]
2018-11-19 hardware/mainboard: Add switches and LEDs
    [debug.sch, ecp5_mainboard.sch, fpga_pwr.sch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]
2018-11-19 hardware/mainboard: Switch debug connector to USB micro-B
    [debug.sch]
2018-11-19 hardware/mainboard: Add DDR3 x32 memory
    [ddr3.sch, debug.sch, ecp5_mainboard.sch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]
2018-11-19 hardware/mainboard: Connect DDR3 IO to FPGA IO
    [ddr3.sch, debug.sch, ecp5_mainboard.sch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]
2018-11-19 hardware/mainboard: Connecting more FPGA IO
    [fpga_io.sch, serdes.sch]
2018-11-19 hardware/mainboard: Pin plan external IO FFCs
    [fpga_io.sch]
2018-11-19 hardware/mainboard: Add config, JTAG and boot flash
    [fpga_io.sch]
2018-11-20 hardware/mainboard: Connect FTDI and add quasi-dual-PMOD
    [fpga_io.sch]
2018-11-20 hardware/mainboard: Re-annotate and fix ERC
    [ddr3.sch, debug.sch, fpga_io.sch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]
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2018-11-20 hardware/mainboard: Assign some footprints
    [ddr3.sch, debug.sch, fpga_io.sch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]
2018-11-21 hardware: Add CABGA756 footprint
    [ecp5_mainboard.sch]
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2018-11-21 hardware: Adding USB-A and MagJack footprints
    [ecp5_mainboard.kicad_pcb, ports.sch]
2018-11-21 hardware/mainboard: Assign more footprints
    [debug.sch, fpga_io.sch, fpga_pwr.sch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]
2018-11-21 hardware: Add SATA connector footprint
    [serdes.sch]
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2018-11-21 hardware: Creating and assigning some misc footprints
    [fpga_io.sch, power.sch, serdes.sch]
2018-11-21 hardware/mainboard: More footprint assignment, other small tweaks
    [miscio.sch, ports.sch, power.sch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]
2018-11-21 hardware/mainboard: All footprints assigned
    [fpga_io.sch, power.sch]
2018-11-21 hardware.mainboard: Fixes from PCB import
    [ecp5_mainboard.kicad_pcb]
2018-11-21 hardware/mainboard: Preliminary placement of some major components
    [ecp5_mainboard.kicad_pcb]
2018-11-21 hardware/mainboard: Power related placement
    [ecp5_mainboard.kicad_pcb, power.sch]
2018-11-22 hardware/mainboard: Power circuitry placed
    [ecp5_mainboard.kicad_pcb, power.sch]
2018-11-22 hardware/mainboard: Change LEDs to larger Wurth 3528 LEDs
    [ecp5_mainboard.kicad_pcb, miscio.sch]
2018-11-22 hardware/mainboard: Configure some 3D shapes
    [ecp5_mainboard.kicad_pcb]
2018-11-23 hardware/mainboard: Place FPGA decoupling
    [ecp5_mainboard.kicad_pcb, fpga_pwr.sch]
2018-11-23 hardware/mainboard: Place DDR3 decoupling and termination
    [ecp5_mainboard.kicad_pcb]
2018-11-23 hardware/mainboard: All parts placed
    [ecp5_mainboard.kicad_pcb, fpga_io.sch]
2018-11-24 hardware/mainboard: Working on 3D
    [ecp5_mainboard.kicad_pcb]
2018-11-24 hardware/mainboard: Complete 3D models, other footprint tweaks
    [ecp5_mainboard.kicad_pcb]
2018-11-24 hardware/mainboard: Reduce refdes size to 0.8mm
    [ecp5_mainboard.kicad_pcb]
2018-11-24 hardware/mainboard: Tidy up silkscreen
    [ecp5_mainboard.kicad_pcb]
2018-11-24 hardware/mainboard: Small design tweaks
    [ecp5_mainboard.kicad_pcb, ports.sch, power.sch]
2018-11-24 hardware/mainboard: Set up layers and design rules
    [ecp5_mainboard.kicad_pcb]
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2018-11-24 hardware/mainboard: Swapping DDR3 groups
    [ecp5_mainboard.kicad_pcb, fpga_io.sch]
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2018-11-26 hardware/mainboard: DDR3 CA traces length matched with squiggly bois
    [ecp5_mainboard.kicad_pcb]
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2019-02-16 hardware/mainboard: Switching from SATA to m.2 connector for second DCU
    [fpga_io.sch, serdes.sch]
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2019-02-20 hardware/mainboard: Tweak layout around M.2 and add standoffs for 30&42mm cards
    [serdes.sch]
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2019-03-22 hardware/mainboard: ERC fixes
    [fpga_io.sch, ports.sch]
2019-03-22 hardware/mainboard: DRC fixes
    [power.sch]
2019-04-03 hardware/mainboard: Silkscreen fixes
2019-04-03 hardware/mainboard: BoM fixes, add USB power option
    [ddr3.sch, debug.sch, ecp5_mainboard.sch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]
2019-04-03 hardware/mainboard: Switch debug/power connector from micro-B to C
    [debug.sch, power.sch]
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
